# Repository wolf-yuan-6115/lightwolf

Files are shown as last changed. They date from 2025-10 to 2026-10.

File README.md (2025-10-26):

# LightWolf

> Sponsored by [Hack Club Blueprint](https://blueprint.hackclub.com/r/137?ref=r) program
> 
> To meet program requirements, `JOURNAL.md` and `bom.csv` files are included in this repository root.

LightWolf is a recreate version of Raspberry Pi Pico development board created by me. It's used to experiment with PCB designing and electronics.

Currently, LightWolf comes with following vairants:
- **LightWolf 2350** (`/2350`): Raspberry Pi RP2350 based development board with 4 MB of flash, USB C connector, a bunch of GPIO pins and 3 user LEDs.
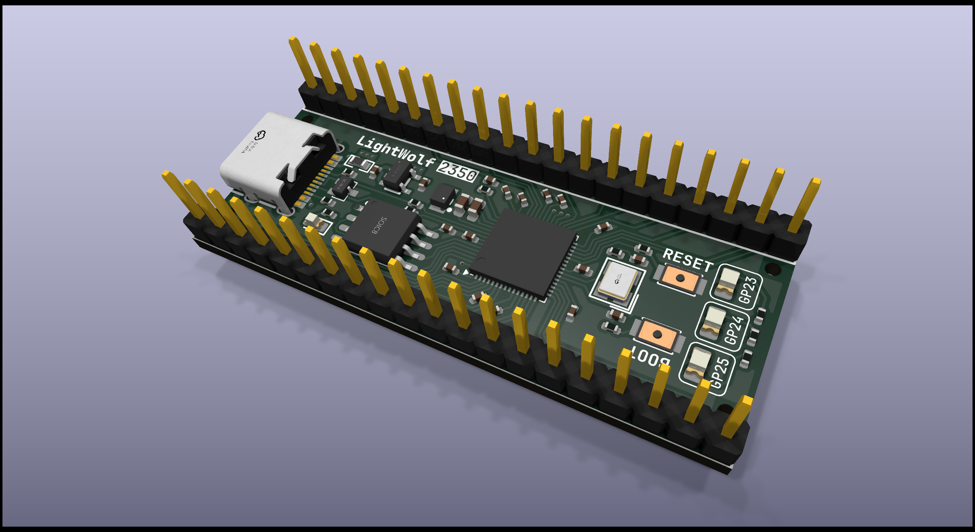
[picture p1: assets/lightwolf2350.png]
LightWolf 2350
  

> Depending on my free time, I may create more variants of LightWolf in the future.

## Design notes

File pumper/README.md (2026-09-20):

# Pumper

Pumper is an experimental RP2354-based USB Audio Class 2 DAC. The board uses a
PCM5102A DAC with OPA1652 and OPA1622 analog stages in a compact design intended
for learning about USB audio and DAC hardware.

The firmware provides a ten-band parametric EQ, headphone crossfeed, output
processing, USB host volume and mute, and persistent EQ profiles. Settings can
be controlled from either the React WebHID controller or the native Android
controller. Both controllers preview edits live and save persistent settings
only through explicit save actions.

## Supported audio formats

Pumper accepts stereo PCM over USB Audio Class 2 in the following formats:

| Sample rate | 16-bit stereo | Packed 24-bit stereo |
| --- | --- | --- |
| 44.1 kHz | Yes | Yes |
| 48 kHz | Yes | Yes |
| 88.2 kHz | Yes | Yes |
| 96 kHz | Yes | Yes |
| 176.4 kHz | Yes | No |
| 192 kHz | Yes | No |

## Audio processing and hardware path

Audio packets cross from the USB-facing core into the real-time DSP core
through a fixed block pool. After processing, ping-pong DMA feeds the PIO I2S
transmitter; the analog stages then filter, buffer, attenuate, and drive the
headphone output.

```mermaid
flowchart TB
    HOST[USB host<br/>UAC2 stereo PCM]

    subgraph DIGITAL[Digital audio path]
        direction LR
        USB[TinyUSB on RP2354 core 0<br/>receive and decode USB packets]
        QUEUE[Fixed audio-block queue<br/>core 0 to core 1]
        EQ[Preamp and<br/>10-band parametric EQ]
        XF[Headphone crossfeed]
        HOSTCTL[USB host<br/>gain and mute]
        OUTPROC[Output processing<br/>balance, mono, and width]
        LIMIT[Always-on<br/>stereo limiter]
        PACK[Final PCM quantization<br/>and I2S packing]
        I2S[Ping-pong DMA and PIO<br/>I2S transmitter]
        DAC[PCM5102A<br/>I2S DAC]

        USB --> QUEUE --> EQ --> XF --> HOSTCTL --> OUTPROC --> LIMIT --> PACK --> I2S --> DAC
    end

    subgraph ANALOG[Analog audio path]
        direction LR
        FILTER[Passive output filters]
        BUFFER[OPA1652<br/>stereo buffer]
        VOLUME[Dual-gang analog<br/>volume control]
        DRIVER[OPA1622<br/>headphone driver]
        PROTECT[Output ESD protection]
        JACK[3.5 mm TRRS<br/>analog output]

        FILTER --> BUFFER --> VOLUME --> DRIVER --> PROTECT --> JACK
    end

    HOST --> USB
    DAC --> FILTER
```

## Repository layout

- [`firmware/`](firmware/) — RP2354 firmware and portable host tests.
- [`web/`](web/) — React/TypeScript WebHID controller.
- [`android/`](android/) — experimental Android USB-host controller.
- [`assets/`](assets/) — board and assembled-device images.
- KiCad source files in the repository root — schematic and PCB design.

## Build and run

### Firmware

The firmware requires the Pico SDK, CMake, Ninja, a native C compiler, and the
Arm GNU embedded toolchain. See [`firmware/README.md`](firmware/README.md) for
SDK setup, supported audio formats, flashing, and troubleshooting.

```sh
export PICO_SDK_PATH="${HOME}/Projects/pico-sdk"
cmake -S firmware -B firmware/build -G Ninja \
  -DCMAKE_BUILD_TYPE=Release \
  -DPICO_BOARD=pico2 \
  -DPICO_PLATFORM=rp2350-arm-s \
  -DPICO_FLASH_SIZE_BYTES=2097152
cmake --build firmware/build --target rp2350_usb_dac -j
```

Flash `firmware/build/rp2350_usb_dac.uf2` using the RP2354 BOOTSEL drive.

### Web controller

Use a Chromium-based browser. WebHID works on a secure origin and on
`http://localhost`.

```sh
cd web
pnpm install
pnpm dev
```

See [`web/README.md`](web/README.md) for Linux HID permissions, tests,
production builds, previewing, and deployment.

### Android controller

The Android controller requires JDK 17 and Android SDK API 37. Android Studio
can open [`android/`](android/) directly.

```sh
cd android
./gradlew testDebugUnitTest lintDebug assembleDebug
```

See [`android/README.md`](android/README.md) for the debug simulator and USB
device requirements.

### Firmware host tests

These tests do not require the Pico SDK:

```sh
cmake -S firmware/tests -B /tmp/pumper-firmware-tests
cmake --build /tmp/pumper-firmware-tests
ctest --test-dir /tmp/pumper-firmware-tests --output-on-failure
```

## Hardware

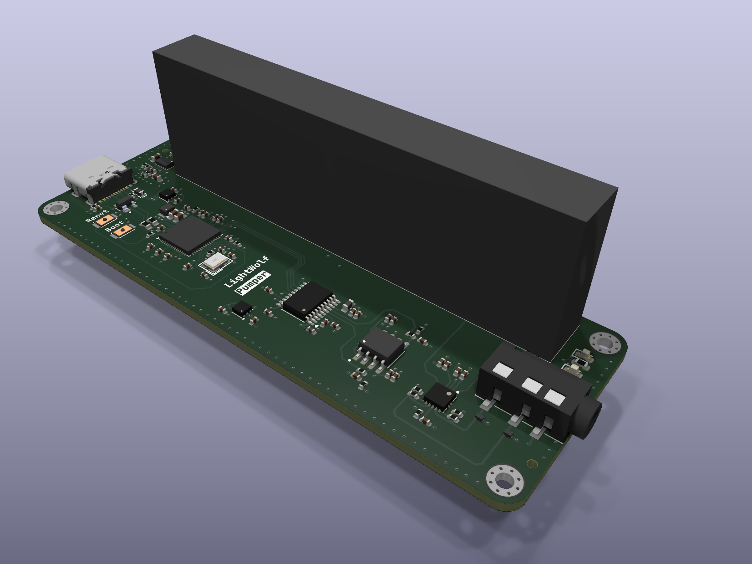
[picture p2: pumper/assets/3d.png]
PCB render


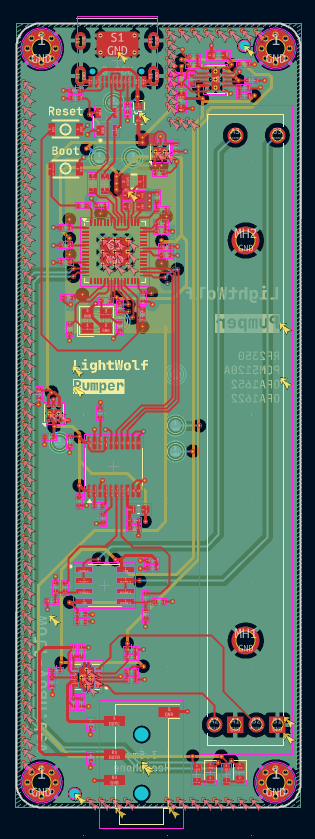
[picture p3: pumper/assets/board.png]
PCB


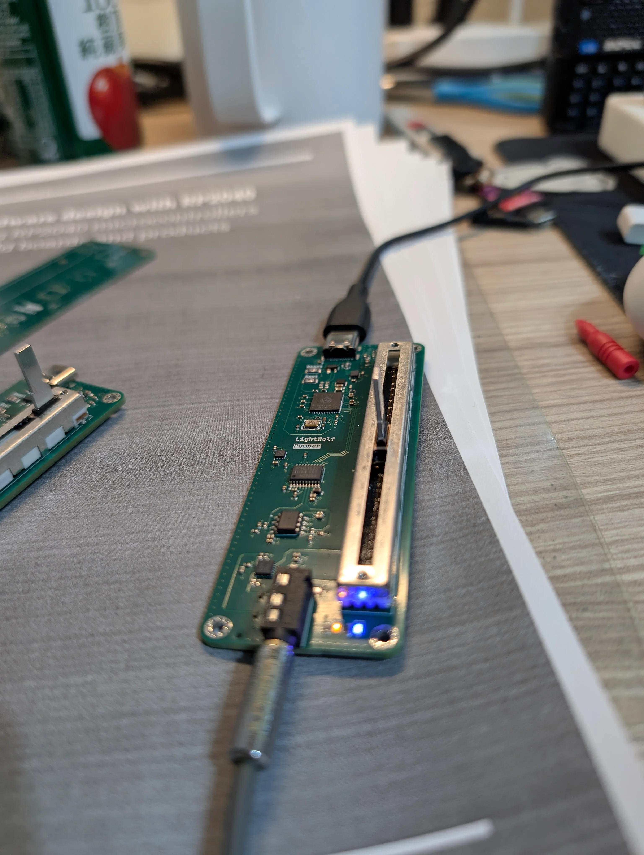
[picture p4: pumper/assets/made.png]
Assembled board


## Bill of materials

| Item | Cost |
| --- | --- |
| PCB shipping | $6.12 |
| PCB assembly | $86.18 |
| PCB | $11.43 |
| **Total** | **$103.73** |

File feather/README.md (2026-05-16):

# Feather

A USB DAC that provides even better audio quality compared to Pumper. Since I want to make the board as small as possible, the board itself is only 6x4 cm.

This board has two outputs: One is 3.5mm unbalanced output, another one is 4.4mm balanced, for headphone that supports this and it can provide more power through this port.

## Why Feather?

Due to being *half* Hi-Fi fan, I want to try out some new method to get better audio. Like previous project Pumper, already got amazing power to drive headphone. Though it has some flaw and I think it's got not very balanced sound profile.

Feather is aimed to elimate the problem encountered on Pumper, with improved DAC and op-amp and one more balanced output. It should be a lot better at driving headphone and provide good audio.

## Images

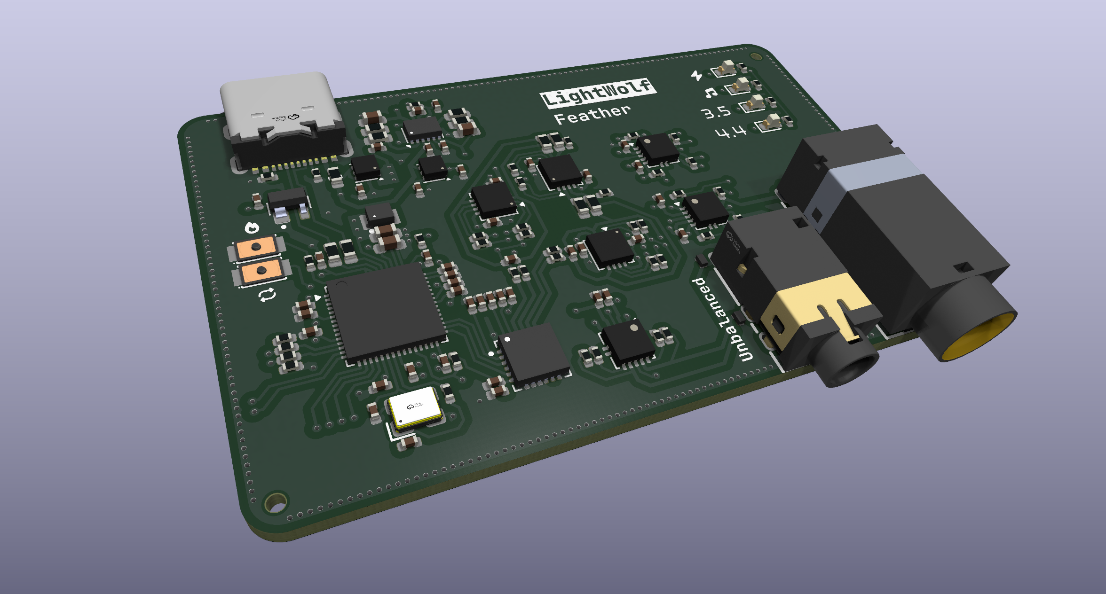
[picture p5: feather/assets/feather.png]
PCB render


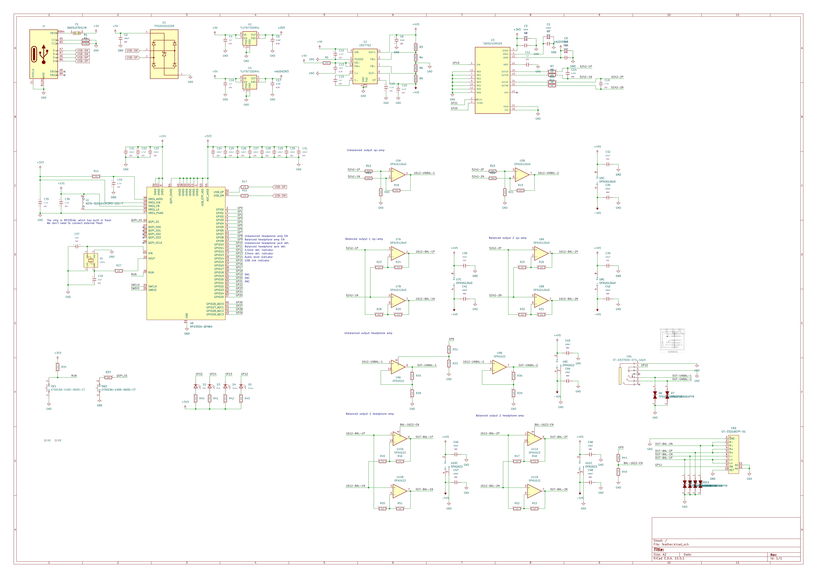
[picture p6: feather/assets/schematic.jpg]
Schematic


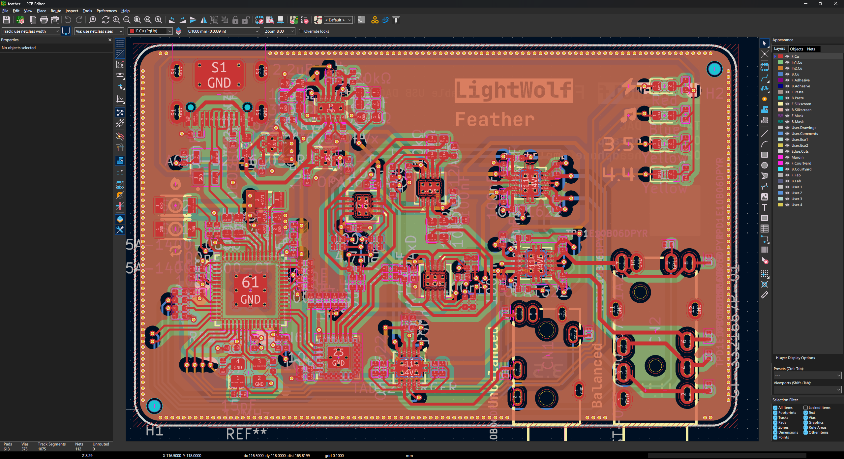
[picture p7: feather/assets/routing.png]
Routing


> It's a 4 layer board, with dedicated GND plane and power plane.

## BOM

| Name | Cost |
| --- | --- |
| PCB Shipping | $4.86 |
| PCB Assambly | $117.63 |
| PCB | $7.00 |
| Coupon | $-9.00 |
| **Total** | **$120.49** |

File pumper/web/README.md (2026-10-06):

# Pumper WebHID controller

The web controller is a static React application for the LightWolf Pumper USB
DAC. It uses TypeScript, Vite, Tailwind CSS 4, daisyUI, and Lucide icons.

It provides:

- Live ten-band parametric EQ preview with response graph, automatic preamp,
  input/output level meters updating at 50 Hz, and a firmware 3.3 limiter activity indicator.
- An always-on live output spectrum behind the EQ curve on firmware 3.5 or newer.
- Ten device profiles with separate load, save, default, and delete actions.
- USB sample-rate, bit-depth, stream, volume, and mute status.
- Headphone crossfeed and, on firmware 3.0 or newer, global output processing.
- The additional low-pass, high-pass, notch, and constant-peak band-pass EQ
  filters available on firmware 3.0 or newer.
- Firmware restart and BOOTSEL handoff actions.
- A responsive firmware 3.4 diagnostics grid for DSP, buffering, USB, and
  storage telemetry.

Live edits are sent to the DAC for preview. Flash is changed only by an
explicit profile, crossfeed, output-processing, default, or delete action.

The output spectrum uses a separate −96–0 dBFS scale and 256 logarithmic
points from 20 Hz to 20 kHz. Its 2,048-sample analysis window covers about
43–46 ms of audio, with native frequency spacing of roughly 22–23 Hz;
the display points do not provide independent resolution below that spacing.
It combines stereo power and targets 20 updates per second, dropping visual
updates when necessary to prioritize playback. Spectrum reports share the level
meter connection lifecycle, with no toggle or browser setting. Animation pauses
while the page is hidden. The spectrum animates
between reports with a fast rise and a short decay. Android does not
have the spectrum feature yet.

## Requirements

- Chromium-based browser with WebHID support
- Node.js and pnpm
- A Pumper DAC for hardware control

WebHID works from a secure origin and from `http://localhost`; no special
firmware development-origin flag is required.

## Development

From this directory:

```sh
pnpm install
pnpm dev
```

Open the local Vite URL in Chromium and connect the DAC over USB.

### Linux device access

Linux may create generic HID nodes without write permission for the logged-in
user. Install the project rule once, reload udev, and reconnect the DAC:

```sh
sudo install -m 0644 ../udev/70-pumper-webhid.rules /etc/udev/rules.d/
sudo udevadm control --reload-rules
```

The rule is restricted to the Pumper USB VID/PID and grants access to the
active desktop session through systemd-logind.

## Verification

```sh
pnpm test
pnpm build
pnpm preview
```

The production build is written to `dist/`.

## Deployment

The project is configured for Cloudflare Workers Static Assets:

```sh
pnpm deploy
```

Configure the Worker's custom domain separately in Cloudflare if deploying to
`pumper.wolf-yuan.dev`.

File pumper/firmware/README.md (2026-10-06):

# Pumper firmware

The firmware runs on the RP2354 board and exposes a composite USB Audio Class
2 device plus a vendor HID control interface. It provides a ten-band
parametric EQ, headphone crossfeed, global output processing, USB host volume
and mute, persistent profiles, and device diagnostics for the WebHID and
Android controllers.

Firmware 3.4 supports stereo PCM in these formats:

- 16-bit at 44.1, 48, 88.2, 96, 176.4, and 192 kHz.
- Packed 24-bit at 44.1, 48, 88.2, and 96 kHz.

The 24-bit alternate is not available at 176.4 or 192 kHz. Profile changes and
audio-control previews are live; persistent settings are changed only by the
corresponding save, default, or delete action. Audio is briefly muted while a
persistent setting is written and verified.
Realtime meter reports also identify limiter gain reduction for controller clip
indicators. A separate telemetry report exposes device uptime, DSP load, I2S
buffer health, USB feedback, limiter activity, and transport/storage counters.

Firmware 4.0 provides a live output spectrum that is always displayed by the web
controller (also supported on firmware 3.5): 256 display points over 20 Hz–20 kHz, targeting 20 updates per
second. The display measures processed digital audio before the fixed I²S
output gain; it does not measure the analog DAC output.

## Requirements

- CMake 3.13 or newer
- Ninja, or another CMake build tool
- A native C/C++ compiler for Pico SDK host tools
- Arm GNU embedded toolchain, including `arm-none-eabi-gcc`
- Pico SDK 2.3.0 with its Git submodules initialized

On Debian or Ubuntu:

```sh
sudo apt install build-essential cmake git ninja-build gcc-arm-none-eabi libnewlib-arm-none-eabi
```

Check the two tools most commonly missing during configuration:

```sh
arm-none-eabi-gcc --version
ninja --version
```

## Pico SDK setup

Clone the verified SDK release with its submodules and point
`PICO_SDK_PATH` at the checkout:

```sh
git clone --branch 2.3.0 --recurse-submodules \
  https://github.com/raspberrypi/pico-sdk.git "${HOME}/Projects/pico-sdk"
export PICO_SDK_PATH="${HOME}/Projects/pico-sdk"
```

The RP2350 USB audio endpoint requires the following TinyUSB fixes when they
are not already present in the SDK checkout:

```sh
git -C "${PICO_SDK_PATH}/lib/tinyusb" fetch origin
git -C "${PICO_SDK_PATH}/lib/tinyusb" cherry-pick 86c28b76f 1ec93757f
```

Keep these SDK changes in the Pico SDK checkout; they are not project source
files.

## Configure and build

Run from the repository root. The project uses the `pico2` board definition,
the `rp2350-arm-s` platform, and the RP2354's 2 MiB flash configuration:

```sh
cmake -S firmware -B firmware/build -G Ninja \
  -DCMAKE_BUILD_TYPE=Release \
  -DPICO_BOARD=pico2 \
  -DPICO_PLATFORM=rp2350-arm-s \
  -DPICO_FLASH_SIZE_BYTES=2097152

cmake --build firmware/build --target rp2350_usb_dac -j
```

The UF2 image is written to:

```text
firmware/build/rp2350_usb_dac.uf2
```

For later source changes, rerun only the build command. Configure into a fresh
build directory if the SDK, board, platform, or toolchain changes. The build
checks the firmware size and reserves the final 8 KiB of flash for settings.

## Flashing

To flash manually:

1. Disconnect the DAC.
2. Hold the RP2354 BOOTSEL button while reconnecting USB.
3. Release BOOTSEL when the USB mass-storage drive appears.
4. Copy `firmware/build/rp2350_usb_dac.uf2` to the drive.
5. Wait for the drive to disconnect and the DAC to restart.

The WebHID and Android controllers can also request a BOOTSEL restart. They do
not upload the UF2; the image must still be copied to the boot-ROM drive.
Existing profiles are stored outside the UF2 image.

## Host tests

The portable configuration, DSP, protocol, audio-format, and profile-storage
tests do not require the Pico SDK:

```sh
cmake -S firmware/tests -B /tmp/pumper-firmware-tests
cmake --build /tmp/pumper-firmware-tests
ctest --test-dir /tmp/pumper-firmware-tests --output-on-failure
```

## Troubleshooting

- `Compiler 'arm-none-eabi-gcc' not found`: install the Arm embedded toolchain
  or add it to `PATH`.
- `CMAKE_MAKE_PROGRAM is not set` with the Ninja generator: install Ninja or
  choose another installed CMake generator.
- If USB audio or its isochronous endpoint does not work, verify the TinyUSB
  fixes above, configure a fresh build directory, and flash the newly built
  UF2.

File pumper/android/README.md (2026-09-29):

# Pumper Controller for Android

The Android app is an experimental native controller for the LightWolf Pumper
USB DAC. It uses Android USB host APIs and the same HID control protocol as the
WebHID controller in [`../web/`](../web/).

The app provides:

- Live ten-band parametric EQ preview, response graph, automatic preamp,
  signal meters, and a firmware 3.3 limiter activity indicator.
- Audio status including USB sample rate, bit depth, stream state, and host
  master volume/mute.
- Headphone crossfeed with Off, Low, Medium, High, and Custom modes.
- Firmware 3.0 output processing for mono, channel swap, polarity, balance,
  and stereo width.
- Firmware 3.0 low-pass, high-pass, notch, and constant-peak band-pass EQ
  filters.
- Ten profiles with separate save, select, default, and delete actions.
- Firmware diagnostics, normal restart, and BOOTSEL handoff.
- Firmware 3.4 telemetry for DSP load, I2S buffering, USB feedback, limiter
  activity, and transport/storage health.

Crossfeed requires firmware 2.2 or newer. Output processing and the additional
EQ filter types require firmware 3.0 or newer. Live edits do not write flash;
the app saves crossfeed, output processing, and profiles independently through
explicit actions.

## Requirements

- Android 14 or newer (`minSdk 34`)
- Android SDK API 37
- JDK 17
- Android Studio, or the included Gradle wrapper
- An Android USB-host device and a data-capable USB cable or OTG adapter for
  physical DAC testing

If the SDK or Java paths are not configured, set `ANDROID_HOME` and
`JAVA_HOME` before using the Gradle wrapper.

## Build and verify

Run from this directory:

```sh
./gradlew testDebugUnitTest
./gradlew lintDebug
./gradlew assembleDebug
```

The debug APK is written to
`app/build/outputs/apk/debug/app-debug.apk`. To install it on a connected
development device, run:

```sh
./gradlew installDebug
```

Android Studio can open the `android/` directory directly.

## Debug simulator

Debug builds include **Open simulated DAC** on the disconnected screen. The
simulator allows UI and controller workflows to be exercised without Pumper
hardware. It is not included in release builds.

The simulator does not validate Android USB permissions, HID endpoint
discovery, or compatibility with a physical DAC. Those paths require an
Android USB-host device and Pumper hardware.

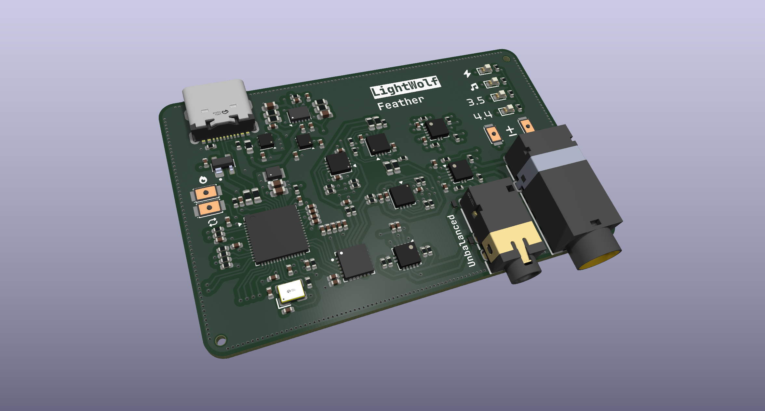
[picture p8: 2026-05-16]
feather/export/feather.png

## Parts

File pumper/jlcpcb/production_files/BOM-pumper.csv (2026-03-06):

Comment | Designator | Footprint | LCSC | Quantity
0603L075SLYR | F1 | F0603 | C207016 | 1
100nF | C12,C14,C15,C16,C17,C18,C19,C20,C21,C22,C3,C31,C32,C33,C35,C37,C42,C43,C47 | C_0402 | C1525 | 19
10kΩ | R5 | R_0402 | C25744 | 1
10uF | C30,C34,C36,C41,C45,C46,C5,C8 | C_0402 | C15525 | 8
120kΩ | R4,R6 | R_0402 | C25750 | 2
15pF | C26,C29 | C_0402 | C1548 | 2
180Ω | R23 | R_0603 | C22828 | 1
1TS015A-1400-0600-CT | SW1,SW2 | SW-SMD_L3.0-W2.0-LS3.5 | C319433 | 2
1kΩ | R12,R13,R16,R17,R18,R19,R20,R21,R8 | R_0402 | C11702 | 9
1uF | C1,C4,C9 | C_0402 | C52923 | 3
2.2nF | C38,C39 | C_0402 | C1531 | 2
2.2uF | C2,C40,C44 | C_0402 | C12530 | 3
2.2uF | C11,C6 | C_0603 | C23630 | 2
27Ω | R10,R11 | R_0603 | C25190 | 2
2kΩ | R14,R15 | R_0402 | C4109 | 2
330kΩ | R3,R7 | R_0402 | C25778 | 2
33Ω | R9 | R_0402 | C25105 | 1
4.7uF | C24,C25 | C_0603 | C19666 | 2
4.7uF | C10,C13,C23,C7 | C_0402 | C23733 | 4
47kΩ | R22 | R_0402 | C25792 | 1
5.1kΩ | R1,R2 | R_0402 | C25905 | 2
560Ω | R24 | R_0603 | C23204 | 1
ABM8-272-T3_C20625731 | U5 | CRYSTAL-SMD_4P-L3.2-W2.5-BL | C20625731 | 1
AOTA-B201610S3R3-101-T | L1 | IND-SMD_L2.0-W1.6_AOTA-B201610S3R3-101-T | C42411119 | 1
AudioJack4 | J2 | Jack_3.5mm_KoreanHropartsElec_PJ-320D-4A_Horizontal | C95562 | 1
Connector, USB-TYPE-C-16P | J1 | TYPE-C-SMD_HX-TYPE-C-16PIN | C5178539 | 1
LED | D2 | D_0603 | C2288 | 1
LM27762 | U3 | WSON-12-1EP_3x2mm_P0.5mm_EP1x2.65_ThermalVias | C473398 | 1
OPA1622IDRCR | U8 | IC_OPA1622IDRCR | C2876559 | 1
OPA1652AIDR | U6 | SOIC127P599X175-8N | C30025 | 1
PCM5102A | U7 | TSSOP-20_4.4x6.5mm_P0.65mm | C107671 | 1
RP2354A-QFN60 | U4 | QFN-60-1EP_7x7mm_P0.4mm_EP3.4x3.4mm_ThermalVias | C41378174 | 1
RS6011DP6002 | VR1 | RS6011DP6002 | C470553 | 1
TLV76733DRVx | U1,U2 | WSON-6-1EP_2x2mm_P0.65mm_EP1x1.6mm_ThermalVias | C2848334 | 2
TPD1E10B06DPYR | D4,D5 | DIO_TPD1E10B06DPYR | C48260 | 2
TPD2E001DZDR | D1 | SOT192P237X122-4N | C89411 | 1
Yellow | D3 | D_0603 | C89811 | 1
~ | FB1 | FB_0603 | C1002 | 1
TestPoint | TP9 | TestPoint_Pad_D1.0mm |  | 1
TestPoint | TP8 | TestPoint_Pad_D1.0mm |  | 1
TestPoint | TP7 | TestPoint_Pad_D1.0mm |  | 1
TestPoint | TP6 | TestPoint_Pad_D1.0mm |  | 1
TestPoint | TP5 | TestPoint_Pad_D1.0mm |  | 1
TestPoint | TP4 | TestPoint_Pad_D1.0mm |  | 1
TestPoint | TP3 | TestPoint_Pad_D1.0mm |  | 1
TestPoint | TP1 | TestPoint_Pad_D1.0mm |  | 1
TestPoint | TP2 | TestPoint_Pad_D1.0mm |  | 1

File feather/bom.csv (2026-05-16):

Comment | Designator | Footprint | LCSC | Quantity
0603L075SLYR | F1 | Fuse_0603_1608Metric | C207016 | 1
100kΩ | R33,R51 | R_0402 | C25741 | 2
100nF | C1,C2,C21,C23,C24,C25,C26,C27,C28,C29,C3,C30,C31,C32,C9 | C_0402 | C1525 | 15
100nF | C34,C38,C39,C41,C42,C43,C44,C45,C46,C47,C48 | C_0402 | C307331 | 11
10kΩ | R18,R19,R20,R21,R5 | R_0402 | C25744 | 5
10kΩ | R12,R13,R15,R16 | R_0603 | C25804 | 4
10uF | C11,C13,C7,C8 | C_0402 | C15525 | 4
120kΩ | R4,R6 | R_0603 | C25808 | 2
12MHz | X1 | OSC-SMD_4P-L3.2-W2.5-BL_SIT8008BI | C20625731 | 1
15pF | C37,C40 | C_0402 | C1548 | 2
1TS015A-1400-0600-CT | SW1,SW2,SW3,SW4 | SW-SMD_L3.0-W2.0-LS3.5 | C319433 | 4
1kΩ | R10,R11,R23,R24,R25,R26,R27,R28,R29,R30,R31,R32,R34,R35,R36,R37,R38,R39,R40,R42,R43,R44,R45,R46,R47,R48,R49,R50,R52,R53,R54,R55,R7,R8 | R_0402 | C11702 | 34
1uF | C12,C15,C16,C4 | C_0402 | C52923 | 4
2.2uF | C17,C5 | C_0402 | C12530 | 2
2.2uF | C20,C6 | C_0603 | C23630 | 2
27Ω | R17,R22 | R_0603 | C25190 | 2
330kΩ | R3,R9 | R_0603 | C23137 | 2
330Ω | R41 | R_0402 | C25104 | 1
33Ω | R14 | R_0402 | C25105 | 1
4.7nF | C14,C18 | C_0402 | C1538 | 2
4.7uF | C35,C36 | C_0603 | C19666 | 2
4.7uF | C10,C19,C22,C33 | C_0402 | C23733 | 4
5.1kΩ | R1,R2 | R_0402 | C25905 | 2
AOTA-B201610S3R3-101-T | L1 | IND-SMD_L2.0-W1.6_AOTA-B201610S3R3-101-T | C42411119 | 1
Blue | D3 | D_0603 | C7496823 | 1
Connector, USB-TYPE-C-16P | J1 | TYPE-C-SMD_HX-TYPE-C-16PIN | C2927039 | 1
GT-3321667P-01 | CN2 | AUDIO-TH_GT-3321667P-01 | C2762984 | 1
LM27762 | U2 | WSON-12-1EP_3x2mm_P0.5mm_EP1x2.65_ThermalVias | C473398 | 1
OPA1612AxD | U5,U7,U8 | WSON-8-1EP_3x3mm_P0.5mm_EP1.2x2mm_ThermalVias | C2058640 | 3
OPA1622 | U10,U11,U9 | Texas_S-PVSON-N10_ThermalVias | C2876559 | 3
RP2354A | U6 | QFN-60-1EP_7x7mm_P0.4mm_EP3.4x3.4mm_ThermalVias | C42411118 | 1
Red | D2 | D_0603 | C2286 | 1
ST-0337D00-071-1A2H | CN1 | AUDIO-TH_ST-0337D00-071-1A2H | C2829972 | 1
TAD5242IRGER | U3 | IC_TAD5242IRGER | C42414591 | 1
TLV76733DRVx | U1,U4 | WSON-6-1EP_2x2mm_P0.65mm_EP1x1.6mm_ThermalVias | C2848334 | 2
TPD1E10B06DPYR | D10,D11,D12,D13,D6,D7,D8,D9 | DIO_TPD1E10B06DPYR | C48260 | 8
TPD2E001DZDR | D1 | SOT192P237X122-4N | C89411 | 1
Yellow | D4,D5 | D_0603 | C89811 | 2

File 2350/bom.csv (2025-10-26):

Comment | Designator | Footprint | LCSC | Quantity
0603L100SLYR | U2 | R0603 | C207017 | 1
100nF | C13,C14,C15,C16,C2,C3,C4,C5,C6,C7,C8 | C_0402 | C1525 | 11
10uF | C12,C9 | C_0402 | C15525 | 2
15pF | C10,C11 | C_0402 | C1548 | 2
1TS015A-1400-0600-CT | BOOT1,RESET1 | SW-SMD_L3.0-W2.0-LS3.5 | C319433 | 2
1kΩ | R1,R8 | R_0402 | C11702 | 2
33Ω | R6,R7,R9 | R_0402 | C25105 | 3
4.7uF | C17,C18 | C_0603 | C19666 | 2
4.7uF | C19 | C_0402 | C23733 | 1
470nF | C1 | C_0402 | C47339 | 1
470Ω | R10,R11,R12,R4 | R_0402 | C25117 | 4
5.1kΩ | R13,R2,R3 | R_0402 | C25905 | 3
ABM8-272-T3_C20625731 | U1 | CRYSTAL-SMD_4P-L3.2-W2.5-BL | C20625731 | 1
AOTA-B201610S3R3-101-T | L1 | IND-SMD_L2.0-W1.6_AOTA-B201610S3R3-101-T | C42411119 | 1
DS1021-1X20SF11-B | U5,U6 | HDR-TH_20P-P2.54-V-M | C7430376 | 2
Green | D4,D5 | D_0805 | C2297 | 2
RP2350A_C42411118 | U4 | QFN-60-1EP_7x7mm_P0.4mm_EP3.4x3.4mm_ThermalVias | C42411118 | 1
TPD2E2U06DCKR | D1 | SC-70-3_L2.0-W1.3-P0.65-LS2.1-BL | C1855726 | 1
TYPE-C-31-M-12 | USBC1 | USB-C_SMD-TYPE-C-31-M-12_1 | C165948 | 1
W25Q64JVSSIQ_C179171 | U3 | SOIC-8_L5.3-W5.3-P1.27-LS8.0-BL | C179171 | 1
White | D2 | D_0603 | C2290 | 1
XC6220B331MR-G | Q1 | SOT-25_L3.0-W1.6-P0.95-LS2.8-TL | C86534 | 1
Yellow | D3 | D_0805 | C2296 | 1

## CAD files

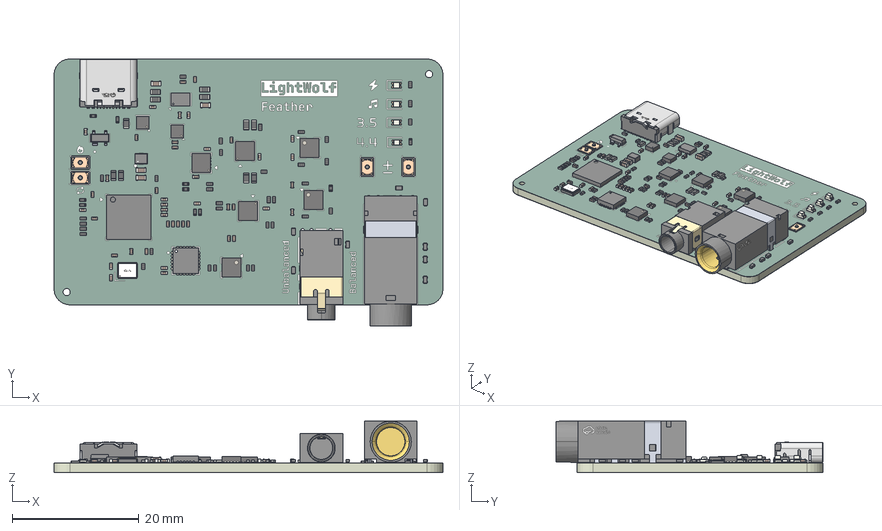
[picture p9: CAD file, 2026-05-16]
feather/export/feather.step
61.4 x 42.2 x 8.17 mm
C_0402_1005Metric x 44
R_0603_1608Metric x 10
R_0402_1005Metric x 45
LED_0603_1608Metric_Castellated x 4
TYPE-C-SMD_HX-TYPE-C-16PIN
WSON_6_1EP_2x2mm_P065mm_EP1x16mm x 2
OSC-SMD_4P-L3.2-W2.5-CJ13-320001210A20
Texas_S_PVSON_N10 x 3
AUDIO-TH_ST-0337D00-071-1A2H
SW-SMD_L3.0-W2.0-LS3.5 x 4
RGE24
WSON_8_1EP_3x3mm_P05mm_EP16x20mm x 3
DPY2 x 8
LM27762DSSR
Fuse_0603_1608Metric
IND-SMD_L2.0-W1.6_AOTA-B201610S3R3-101-T
AUDIO-TH_GT-3321667P-01
C_0603_1608Metric x 4
DZD4
RP2350A-QFN60
feather_silkscreen x 2
feather_soldermask x 2
feather_PCB

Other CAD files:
feather/export/feather.stl

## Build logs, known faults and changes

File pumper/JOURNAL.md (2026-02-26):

# 2/27 Nah LM27762 you come back

So basically, I've done following:

1. Relocated LM27762 to far corner from analog circuit
2. Made some cool branding
3. Rerouted several parts



# 2/25 Getting rid of LM27762

Posted the design in KiCad Discord server, and I got some feedback. The most important one is LM27762 is VERY noisy and picky about PCB design from my research. I'm gonna upgrade (Kinda of) and make both AMP run in BTL mode.



# 2/23 Airnote is now pumper

I initially named it Airnote because I want it to me a portable Bluetooth DAC. But it seems like it's not possible and it's now just a USB DAC.

But I finished the schematic and PCB routing!

pumper_page-0001
pumper_page-0002
pumper_page-0003



# 2/22 It's been a big day

Well I threw my schematic into an AI tool and it told me... OPA2141 is too weak (well I mean tl;dr)



Going to replace it with OPA1652

# 2/22 Completed whole routing

Yayyy, but I'm still not sure wether this board will work or not...



# 2/22 Completed power and OPA2141 routing

The power is harder than I was expecting. The chip is so small...



# 2/22 Completed RP2354 routing



# 2/21 Finished all schematic

airnote_page-0001
airnote_page-0002
airnote_page-0003

# 2/21 RP2354A MCU schematic done!



# 2/21 Back from Lunar New Year holiday

Finally decided to use RP2354A (The one with built in flash), and splitted the design into 3 schematics.



# 2/14 YEAHHHH no ESP32 now

ESP32-C3 doesn't have native USB (USB OTG) so we will stick with RP2350! (Or 2040)

Since ESP32 WROOM needs to use standard SMT, we can save some money through using 2350 or 2040.

# 2/12 Just added two pin headers

Nothing new, just two additional header for GPIOs and UART.

# 2/12 Schematic done!

Basically got three TI's chip to get good audio.

From ESP32-C3, to PCM5102A, to OPA2141, finally to OPA1622. 

airnote_page-0001

But I'm not sure if it will work or not. I get into too much field I'm not familiar with.

# 2/11 Reading datasheet...

Just reading datasheet and drawing schematic



# 2/10 Snap, ESP32-S3 doesn't have classic BT

Initially I went with ESP32-S3 because it got bunch of processing power. But it looks like S3 only have Bluetooth LE which doesn't have A2DP. Gotta went with C3. Currently searching for chips.

# 2/6 TWO USB PORTS? What da hel

Soooo I just realized ESP32-S3 got a native USB, but it seems like we still need USB to UART chip for recovery...? Still digging and I think I will have only one which is native port.

Still researching strapping pins.

# 2/5 Started working on AirNote

Current planning is to use ESP32-S3 as MCU, paired with TI's PCM5102 DAC for high quality audio playback. 



Already has some plan in my mind, currently working on power rails and USB input.

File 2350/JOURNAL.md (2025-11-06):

<!--
  ===================    !!READ THIS NOTICE!!   ====================
  DO NOT edit this file manually. Your changes WILL BE OVERWRITTEN!
  This journal is auto generated and updated by Hack Club Blueprint.
  To edit this file, please edit your journal entries on Blueprint.
  ==================================================================
-->

## 10/21/2025 - Drew the schematic  

Drew the schematic, read whole bunch of datasheets.

I ultimately decided to use RP2350, with a 8 MB SPI flash, along with high technology... USB-C connector.

There will also be some pins header on the board.



## 10/22/2025 12 AM - Partially routed PCB  

Got some routing on the PCB now!

Currently only placed main MCU on the board and pin header, other thing is still waiting to do.

I'm concerned about the very limited board size... Hope everything will fit inside the Raspberry Pi Pico size



## 10/22/2025 11:03 PM - Routed non GPIO part on PCB  

Ayyyy some great progress... though there's a bigger challenge upcoming.

I routed all non GPIO pins to RP2350! This leaves me with a bunch of GPIOs. I hope I could route them without getting myself crazy.



## 10/22/2025 11:25 PM - Changed to 4 layer board  

2 layer board made by routing a lotttt messy, soo I decided to change my board to a 4 layer board.

After switching, I don't need to deal with 3V3 and 1V1 plane anymore, yayy



## 10/23/2025 12 AM - Thing didn't go as expected  

After changing the board to a 4 layer one, I don't think I did a great job at trace management...

The board now looks even more messy, I think I need to redo the whole wring someday.



## 10/23/2025 9 PM - Finished rerouting the PCB!  

Yayyy, finally finished rerouting the PCB with 4 layers board!

The inner layer now acts like 3V3 and 5V pane, it heavily reduced the complexity of my route. I think current one is good to ship... just one thing left...

Time for silkscreen art!




> Sadly Hackatime wasn't up during these hours. I tried my best to remember to run it when I start KiCad

## 10/23/2025 11 PM - Finished cooking silkscreen art  

I think I finished my silkscreen art! Though I didn't find a great way to automate the process of labeling GPIO pins, I just adjust and change them manually.




## 10/26/2025 - Ahh board design got some trouble  

I posted my design on Reddit and some people helped me :D

Fixed several issues, including problematic BOOTSEL button, the board should be done now! I didn't see that my design uses via-in-pad, so um I need to spend few extra bucks on via :/

Hope the board works when it arrives



## 11/6/2025 9 PM - Faulty design, faulty board  

So, I just ran into a trouble.

The board arrived, not shorted but RP2350 did not function (USB drive does not appear on the computer, in other word RP2350 is not working correctly). I currently suspect that `VREG_AVDD`'s capacitor is not correctly wire up, and RP2350 didn't work afterwards.

I've spend a while trying to debug, but this seems like the only possible reason why the board doesn't work.



## 11/6/2025 11 PM - Fixed the board, sort of...  

I fixed the board! Thanks to `@colon three` in Hack Club Slack, the problem is not capacitor, it's not resistor. It's crystal oscillator! The project is finally ended here, for who got `60wfo` revision board, a working board is only a few tweak away!



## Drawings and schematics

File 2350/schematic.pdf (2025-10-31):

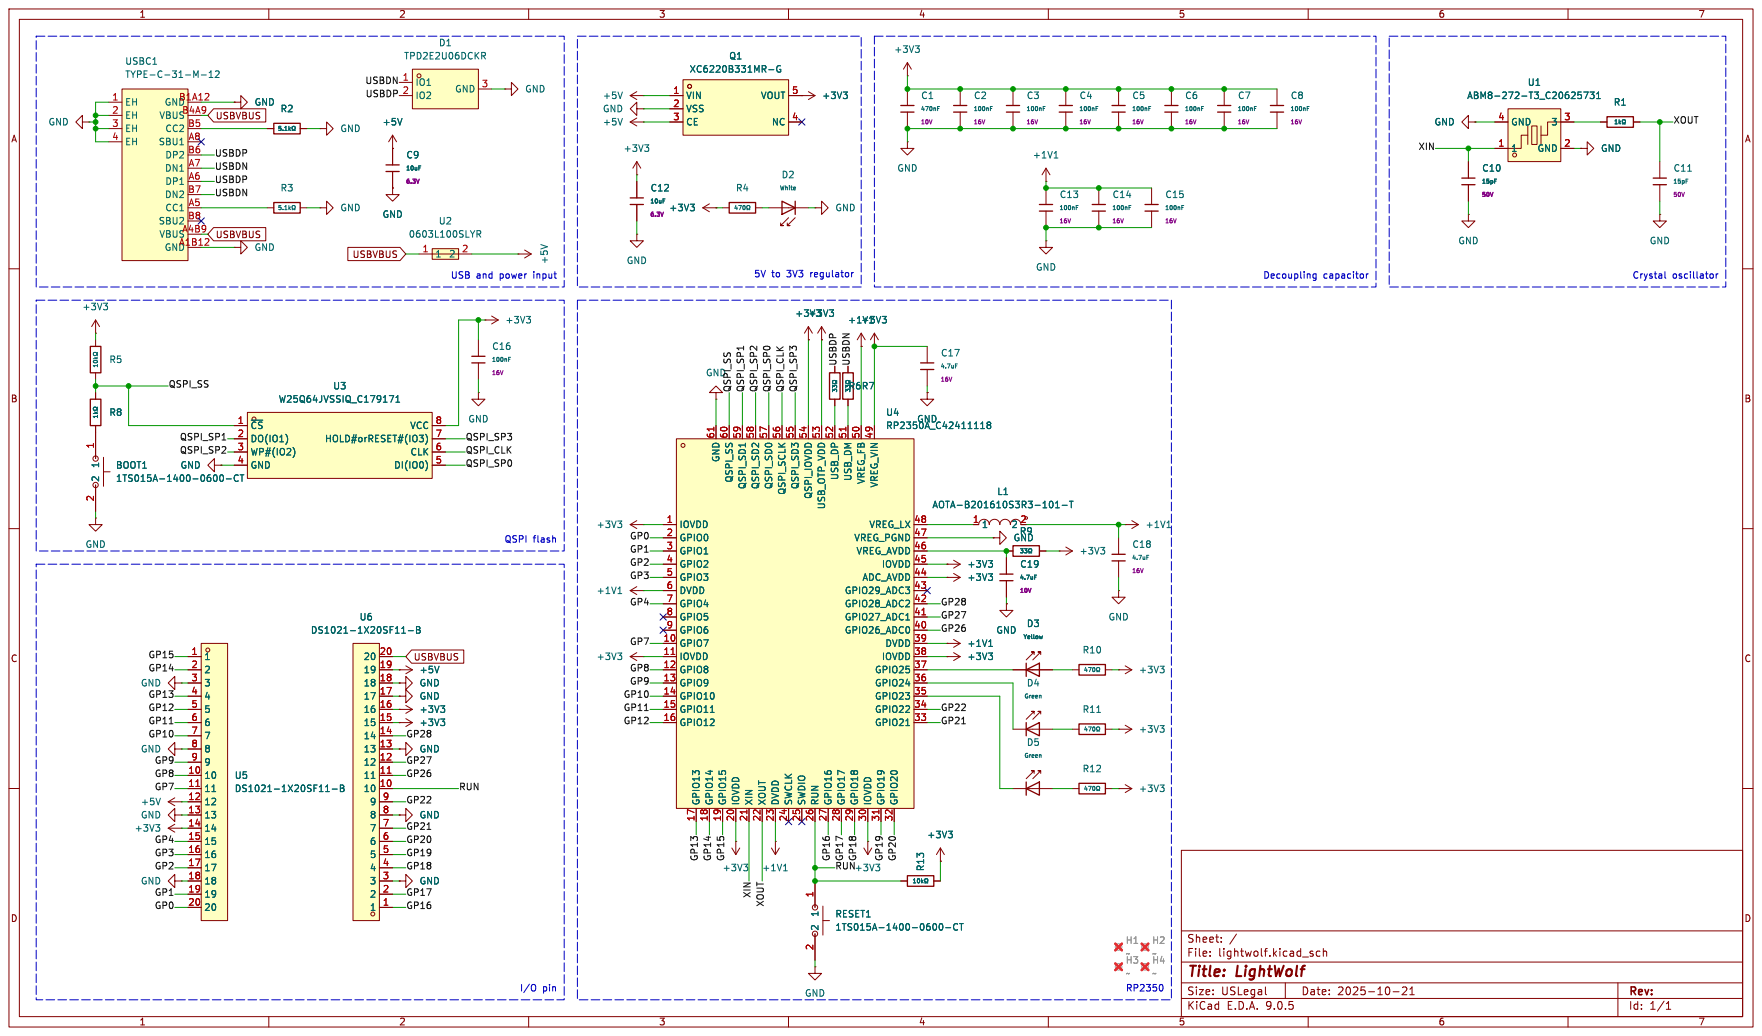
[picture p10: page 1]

+3V3 GND GND GND GND GND

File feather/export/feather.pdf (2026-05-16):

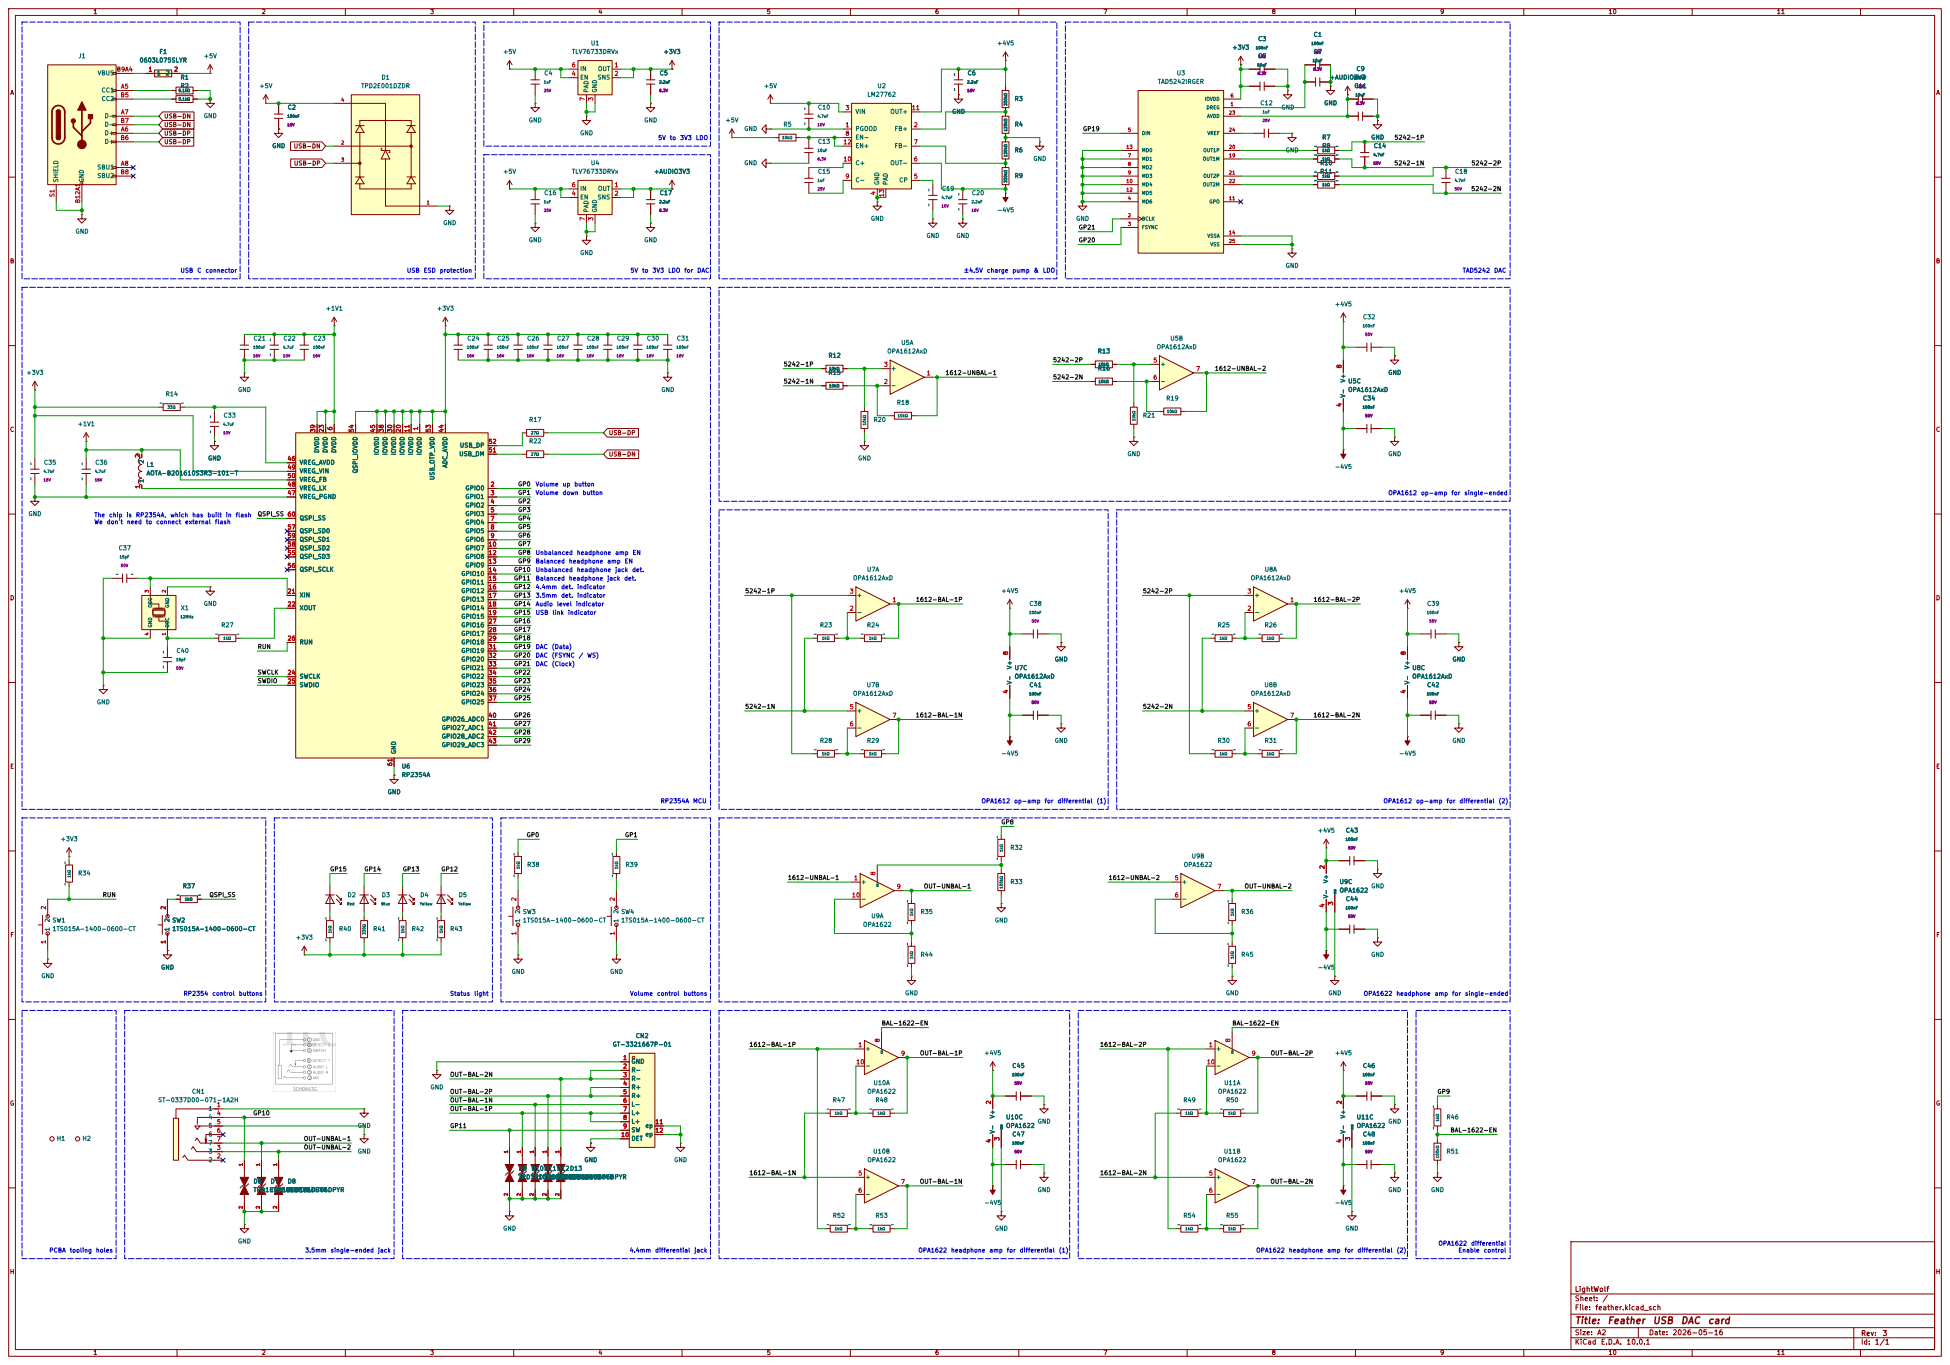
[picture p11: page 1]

4.7uF 10V USB-DP USB-DP USB-DN
USB-DN

5V to 3V3 LDO for DAC

USB-DP USB-DN

Unbalanced headphone jack det. Volume up button
Volume down button Balanced headphone amp EN

OPA1612 op-amp for single-ended OPA1612 op-amp for differential (1) RP2354 control buttons

The chip is RP2354A, which has built in flash We don't need to connect external flash

Unbalanced headphone amp EN

USB link indicator 4.4mm det. indicator

OPA1612 op-amp for differential (2)

OUT-BAL-2P OUT-BAL-1N

OPA1622 headphone amp for differential (1)

LightWolf
Sheet: /
File: feather.kicad_sch
Title: Feather USB DAC card

Size: A2 | Rev: 3
KiCad E.D.A. 10.0.1 | Id: 1/1

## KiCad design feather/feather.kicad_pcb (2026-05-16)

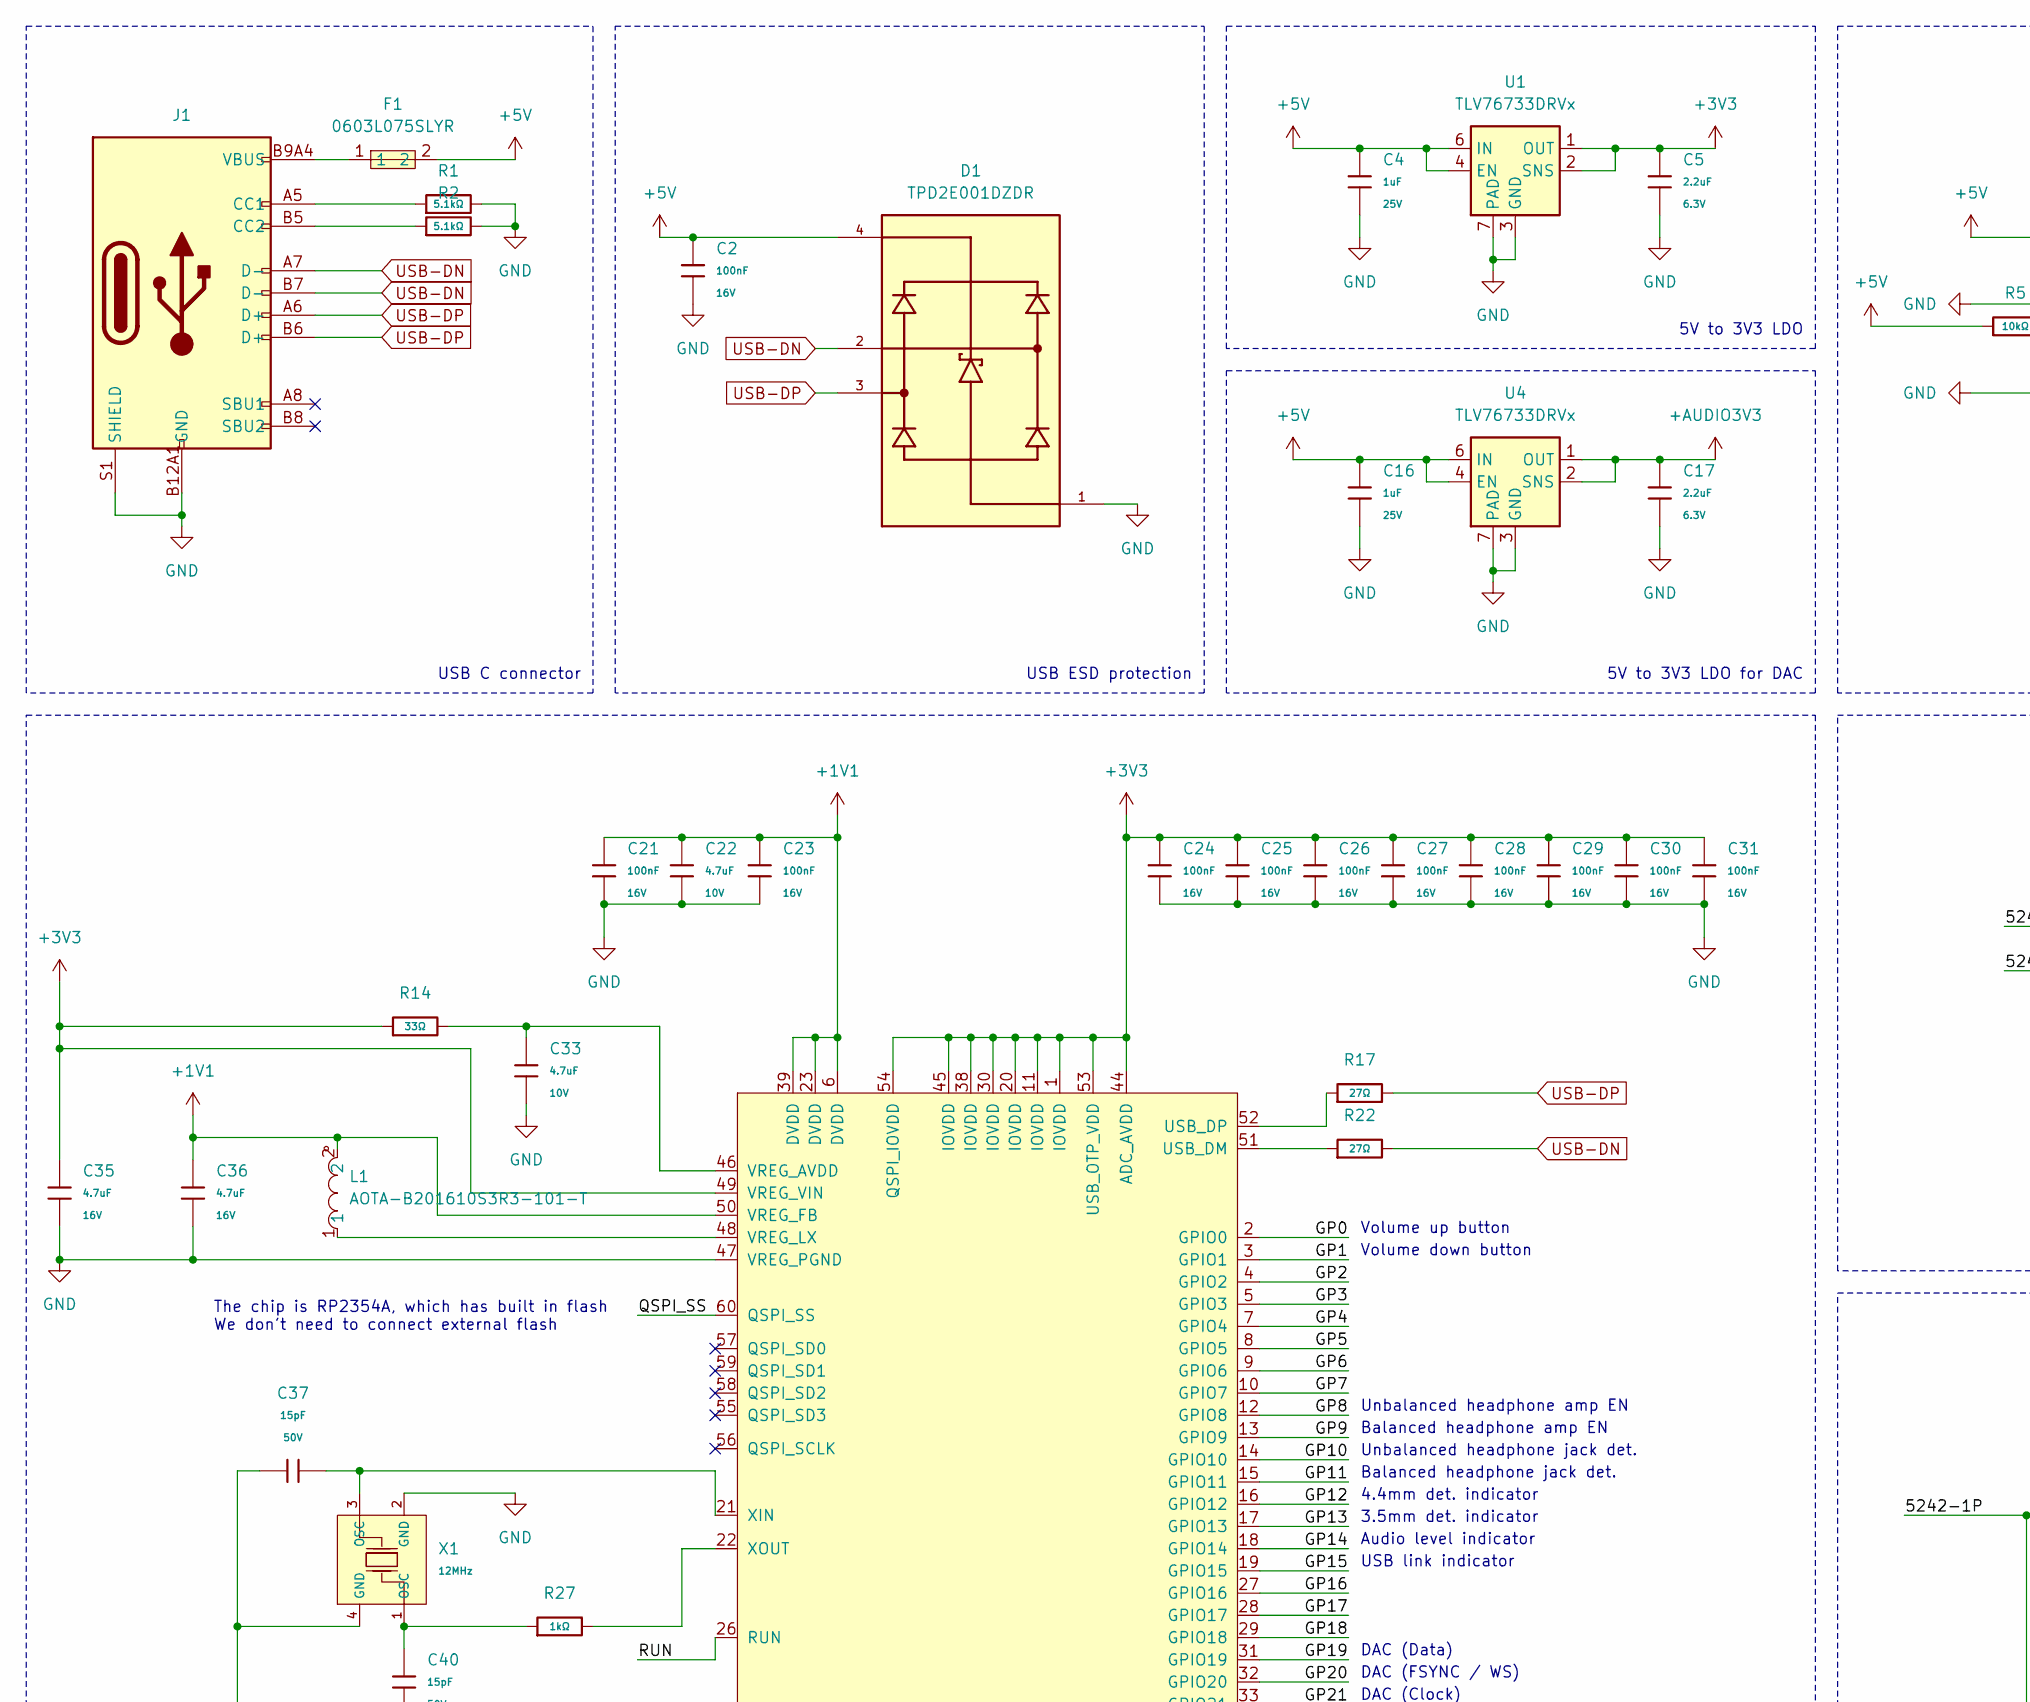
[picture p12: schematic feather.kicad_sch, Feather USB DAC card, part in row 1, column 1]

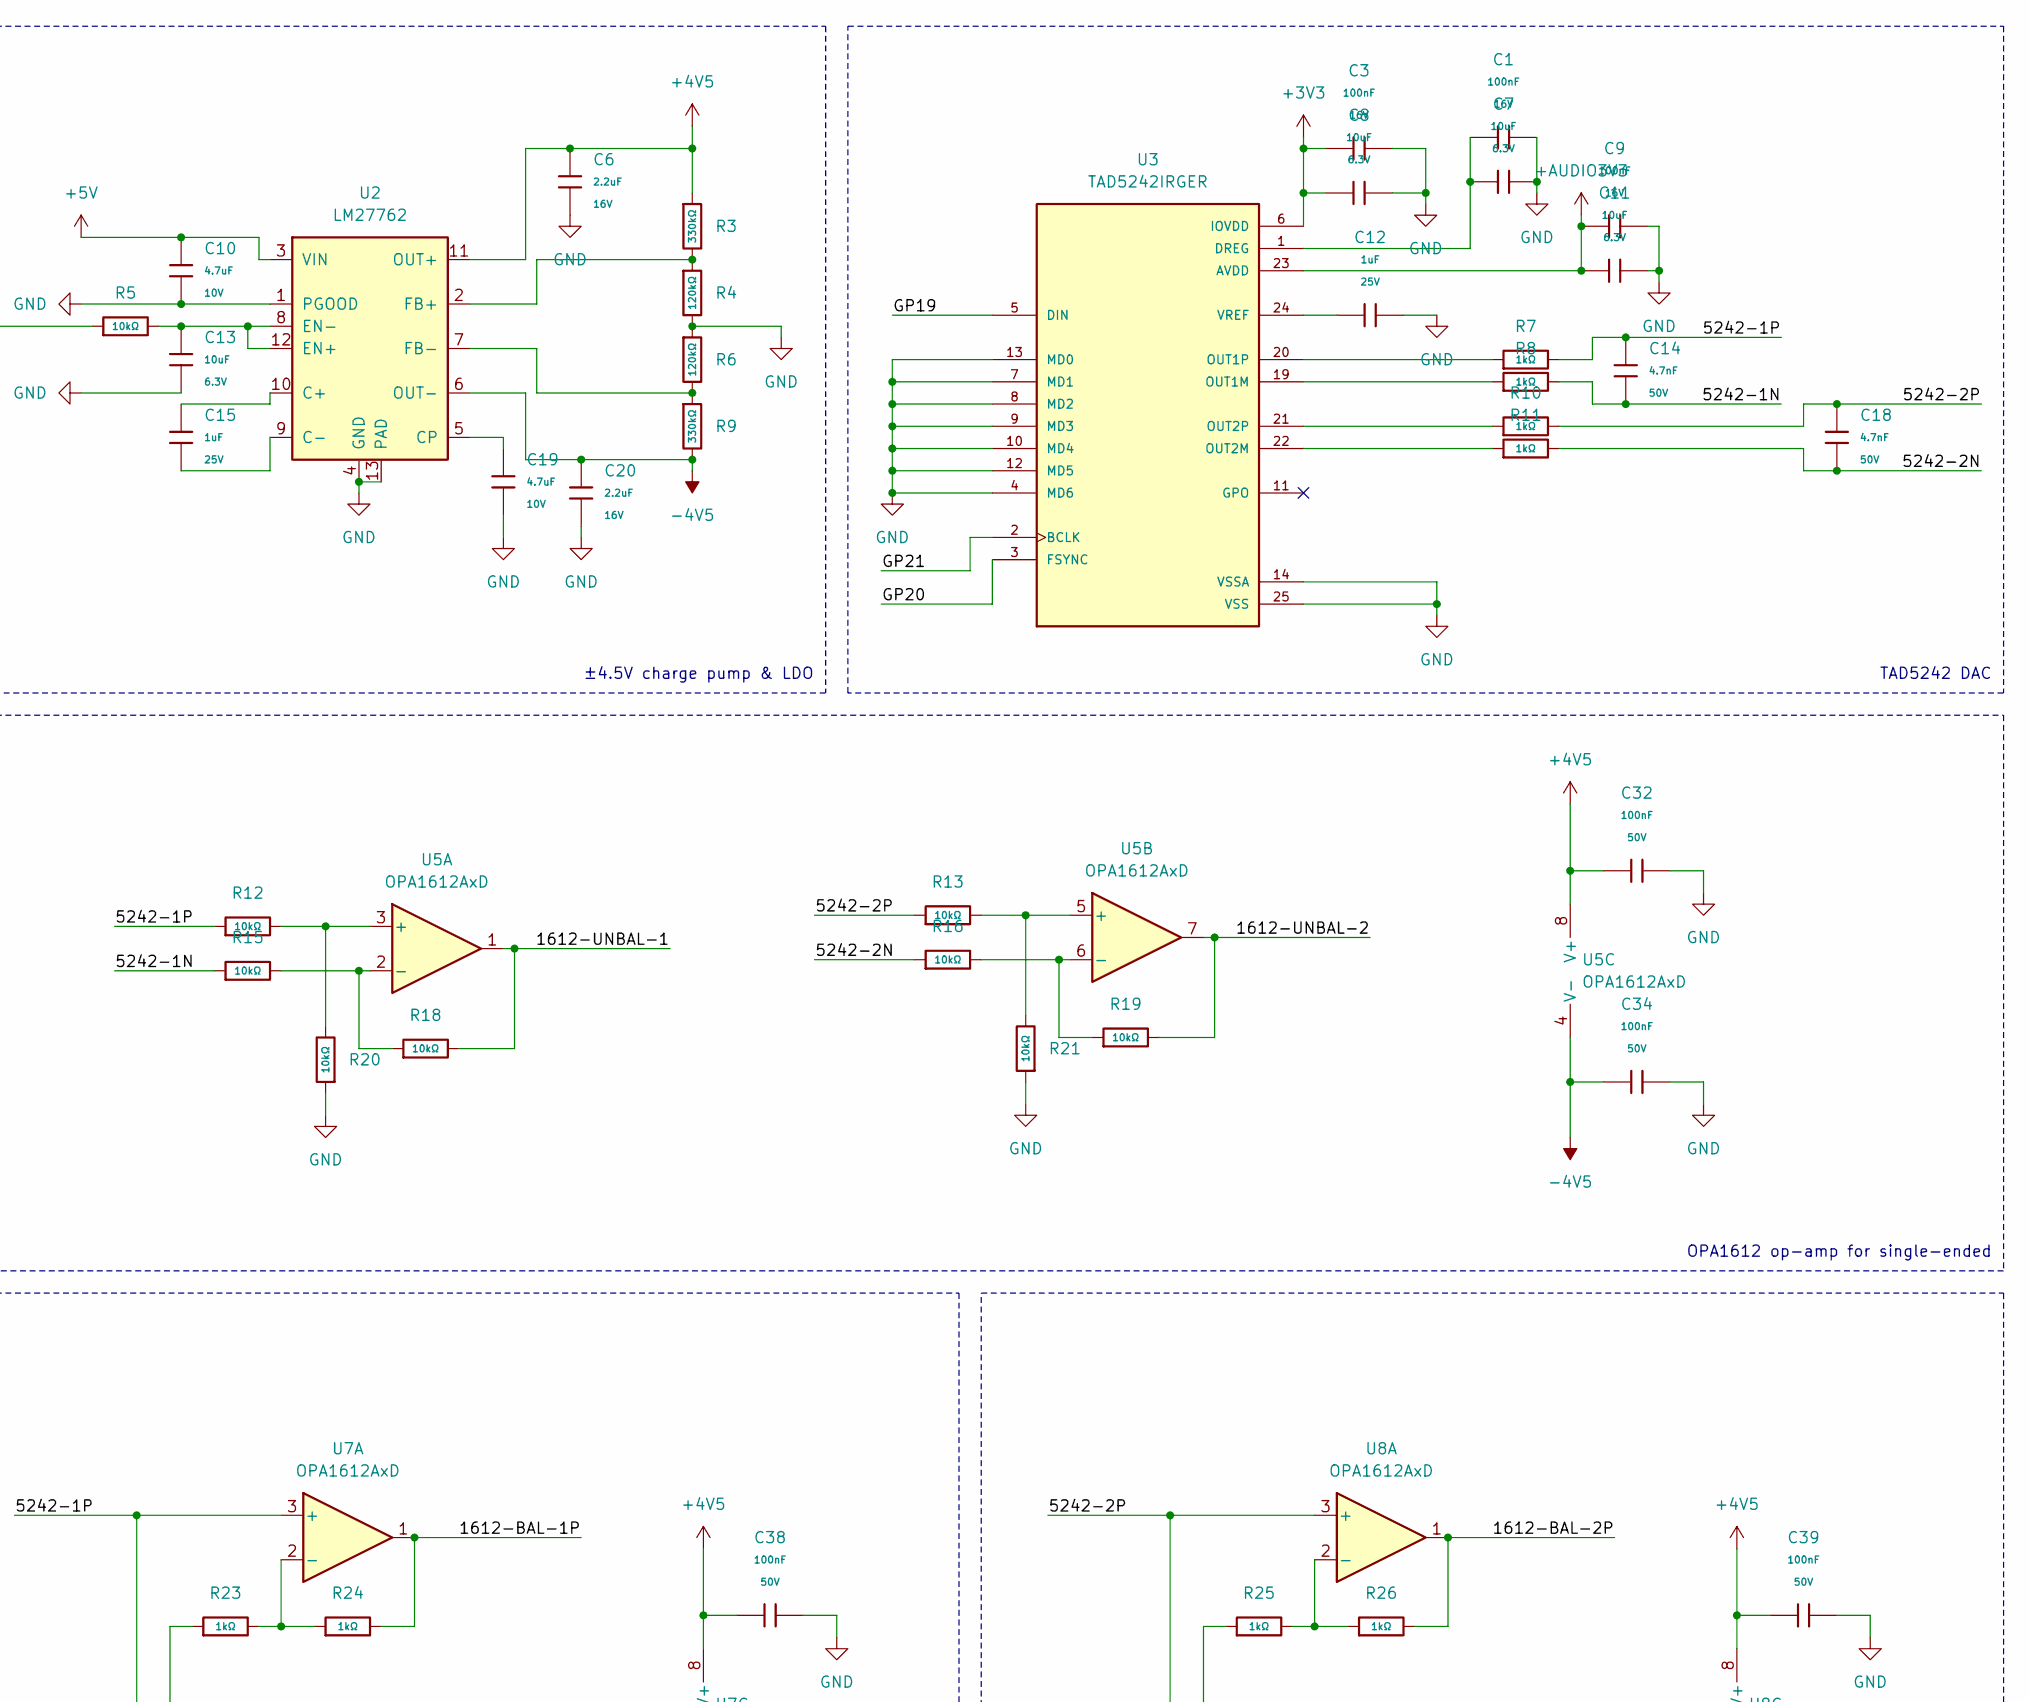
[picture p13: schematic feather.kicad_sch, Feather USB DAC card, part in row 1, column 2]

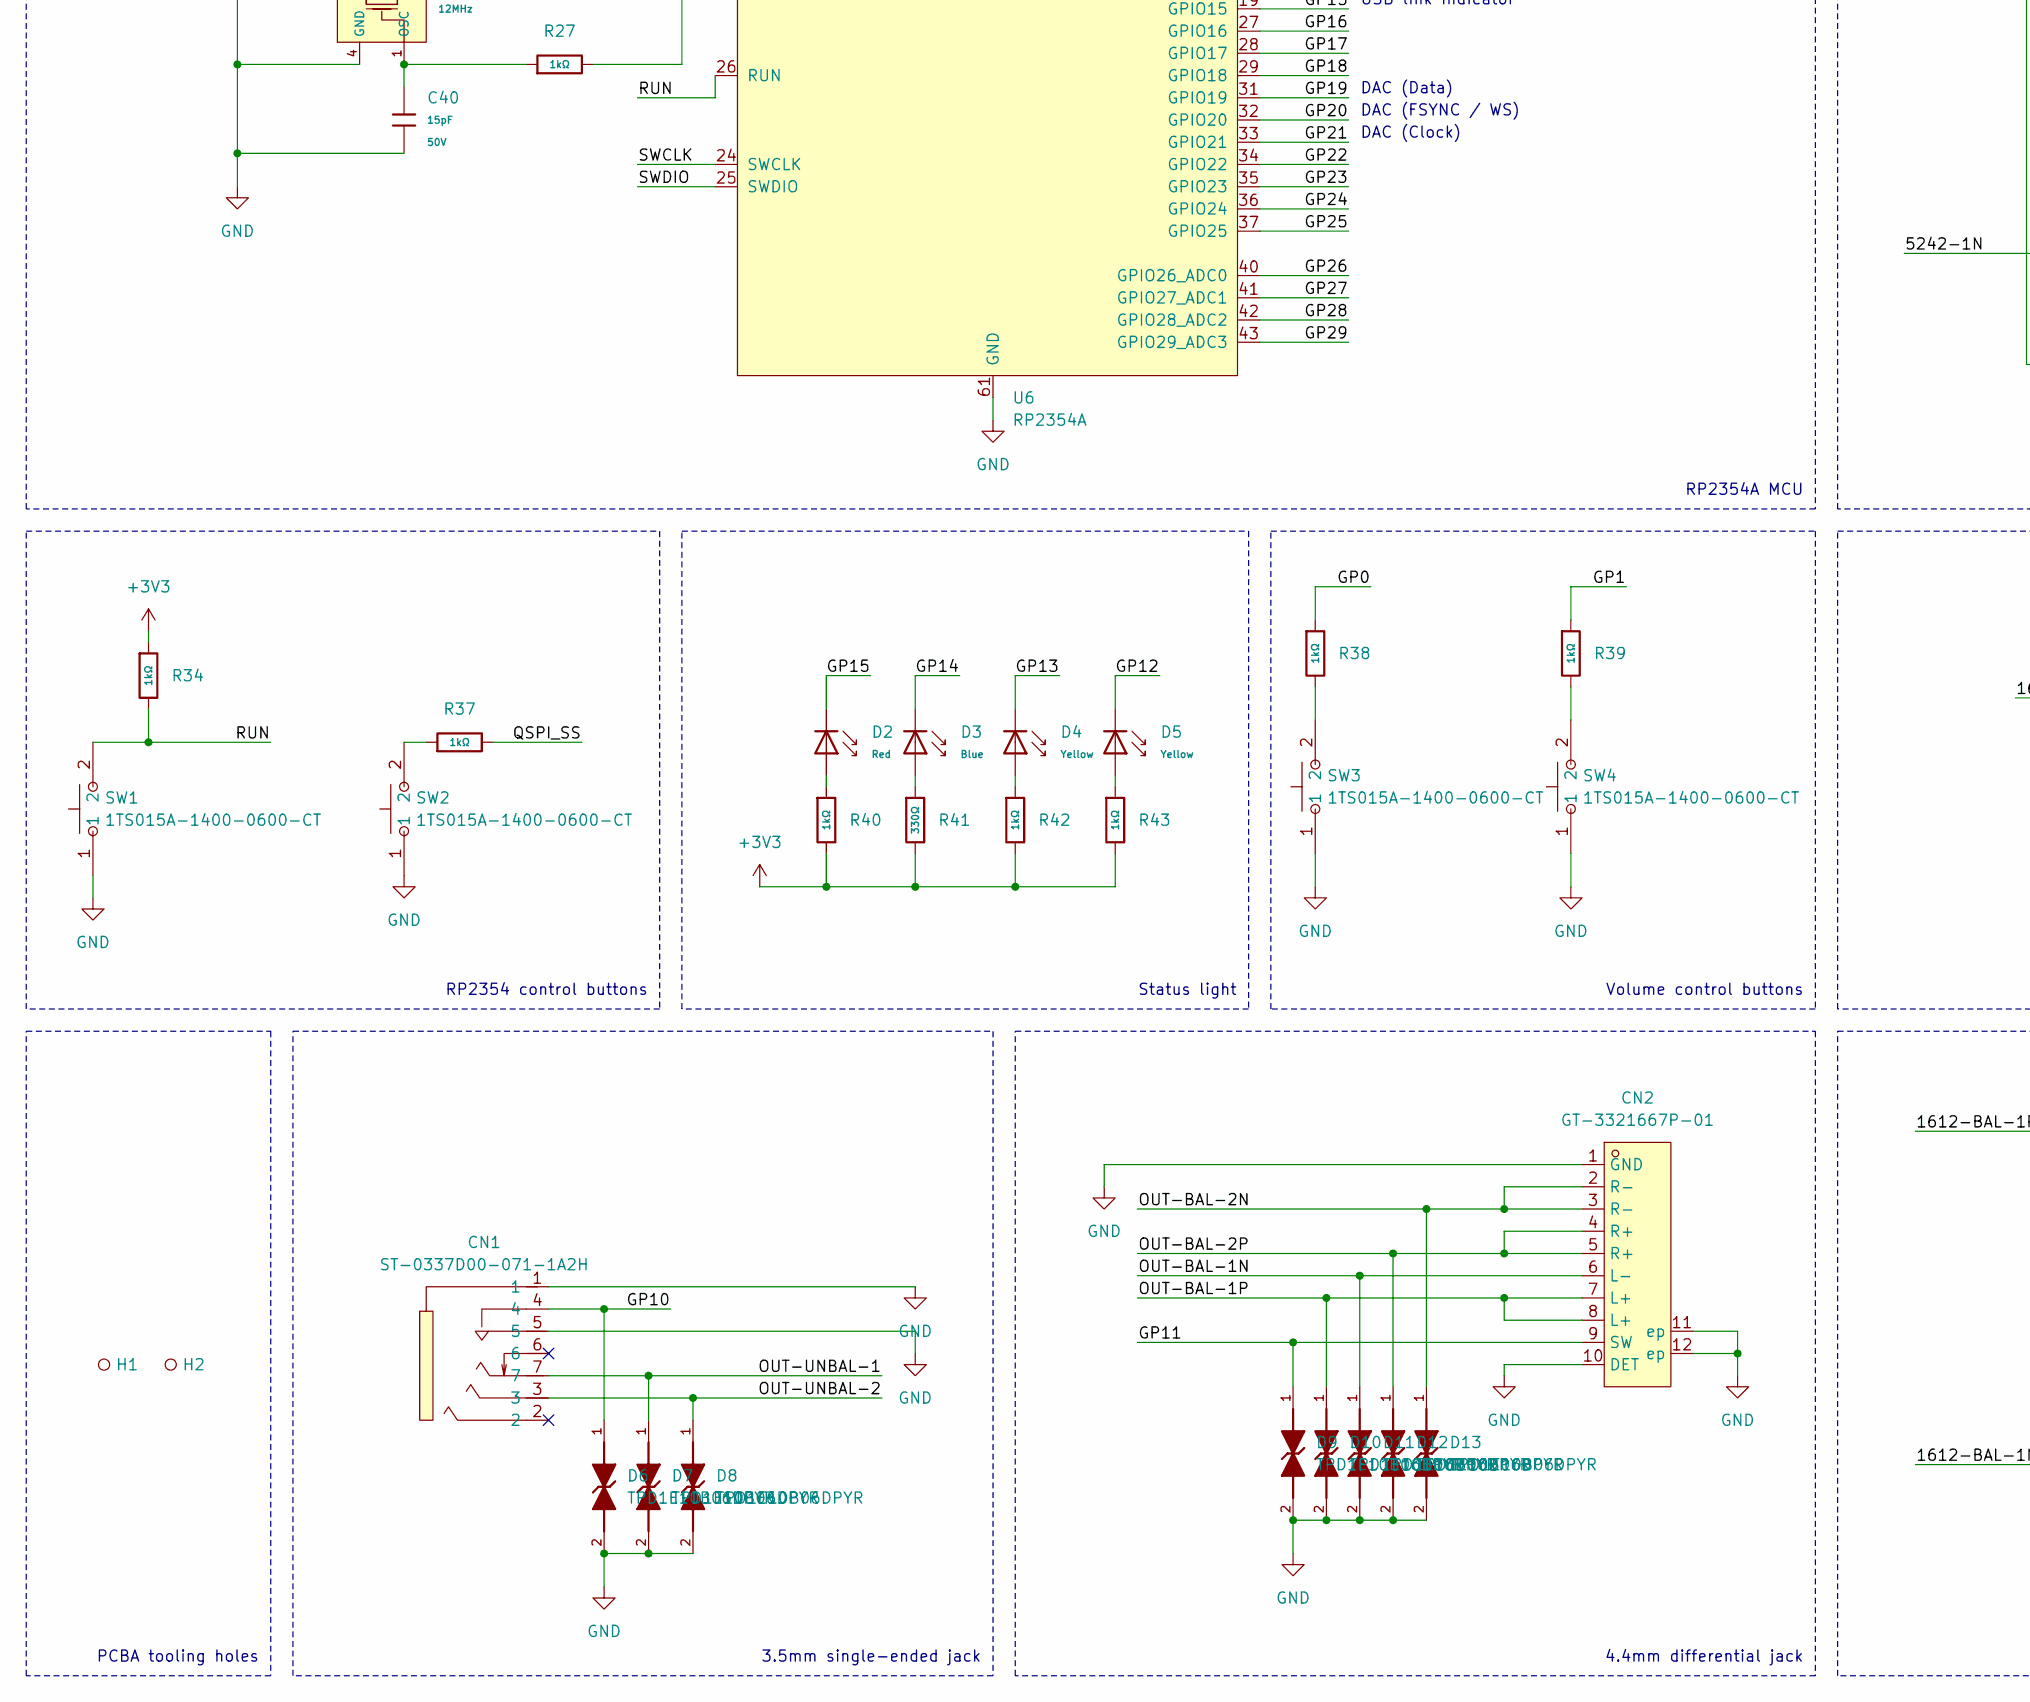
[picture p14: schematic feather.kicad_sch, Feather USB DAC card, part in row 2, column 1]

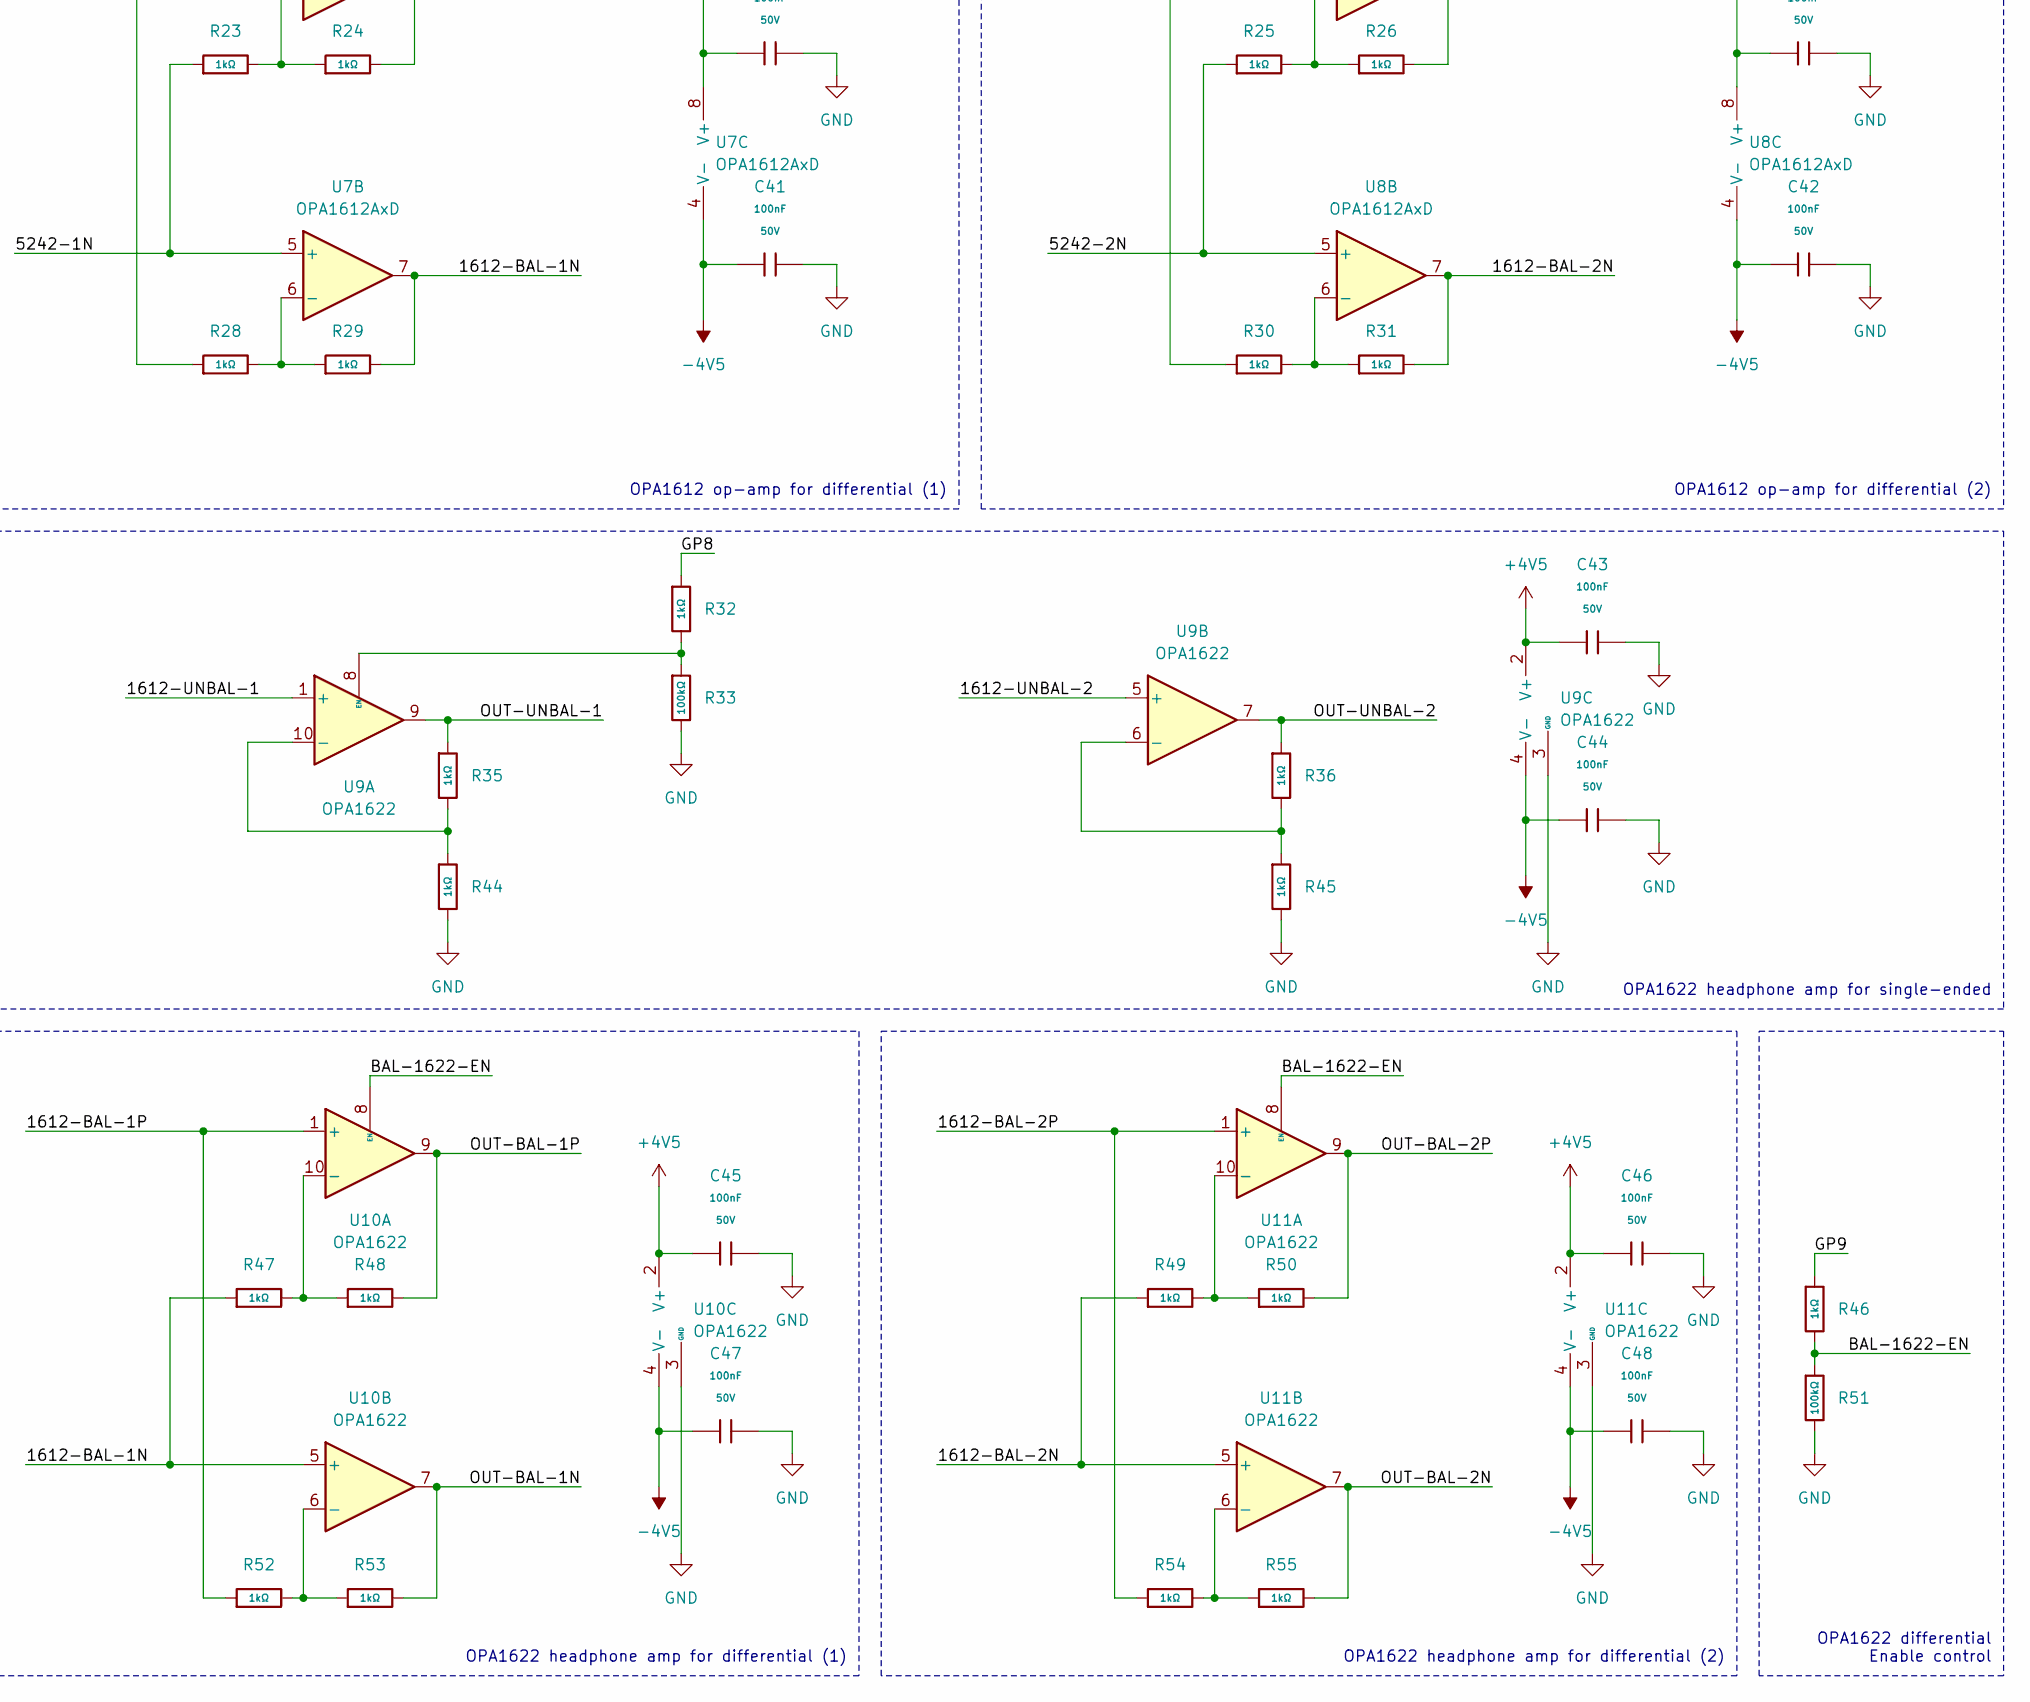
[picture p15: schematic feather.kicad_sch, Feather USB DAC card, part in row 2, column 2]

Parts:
C1, C2, C3, C9, C21, C23, C24, C25, C26, C27, C28, C29, C30, C31: 100nF; C_0402; Voltage Rated 16V; Tolerance ±10%; Part CL05B104KO5NNNC; LCSC C1525
C4, C12, C15, C16: 1uF; C_0402; Voltage Rated 25V; Tolerance ±10%; Part CL05A105KA5NQNC; LCSC C52923
C5, C17: 2.2uF; C_0402; Voltage Rated 6.3V; Tolerance ±20%; Part CL05A225MQ5NSNC; LCSC C12530
C6, C20: 2.2uF; C_0603; Voltage Rated 16V; Tolerance ±10%; Part CL10A225KO8NNNC; LCSC C23630
C7, C8, C11, C13: 10uF; C_0402; Voltage Rated 6.3V; Tolerance ±20%; Part CL05A106MQ5NUNC; LCSC C15525
C10, C19, C22, C33: 4.7uF; C_0402; Voltage Rated 10V; Tolerance ±20%; Part CL05A475MP5NRNC; LCSC C23733
C14, C18: 4.7nF; C_0402; Voltage Rated 50V; Tolerance ±10%; Part 0402B472K500NT; LCSC C1538
C32: 100nF; C_0402; Voltage Rated 50V; Tolerance ±10%; Part CL05B104KB54PNC; LCSC C1525
C34, C38, C39, C41, C42, C43, C44, C45, C46, C47, C48: 100nF; C_0402; Voltage Rated 50V; Tolerance ±10%; Part CL05B104KB54PNC; LCSC C307331
C35, C36: 4.7uF; C_0603; Voltage Rated 16V; Tolerance ±10%; Part CL10A475KO8NNNC; LCSC C19666
C37, C40: 15pF; C_0402; Voltage Rated 50V; Tolerance ±5%; Part 0402CG150J500NT; LCSC C1548
CN1: ST-0337D00-071-1A2H; AUDIO-TH_ST-0337D00-071-1A2H; MPN ST-0337D00-071-1A2H; LCSC Part C2829972
CN2: GT-3321667P-01; AUDIO-TH_GT-3321667P-01; MPN GT-3321667P-01; LCSC Part C2762984
D1: TPD2E001DZDR; SOT192P237X122-4N; PARTREV I; LCSC C89411
D2: Red; D_0603; Forward Voltage (VF) 1.6V~2.6V; Part KT-0603R; LCSC C2286
D3: Blue; D_0603; LCSC C7496823
D4, D5: Yellow; D_0603; Forward Voltage (VF) 1.6V~2.6V; Part NCD0603Y2; LCSC C89811
D6, D7, D8, D9, D10, D11, D12, D13: TPD1E10B06DPYR; DIO_TPD1E10B06DPYR; PARTREV G; LCSC C48260
F1: 0603L075SLYR; Fuse_0603_1608Metric; LCSC Part C207016
H1, H2: Hole_Tooling_JLCPCB
J1: Connector, USB-TYPE-C-16P; TYPE-C-SMD_HX-TYPE-C-16PIN; LCSC C2927039
L1: AOTA-B201610S3R3-101-T; IND-SMD_L2.0-W1.6_AOTA-B201610S3R3-101-T; LCSC Part C42411119
R1, R2: 5.1kΩ; R_0402; Overload Voltage (Max) 50V; Tolerance ±1%; Part 0402WGF5101TCE; LCSC C25905
R3, R9: 330kΩ; R_0603; Overload Voltage (Max) 75V; Tolerance ±1%; Part 0603WAF3303T5E; LCSC C23137
R4, R6: 120kΩ; R_0603; Overload Voltage (Max) 75V; Tolerance ±1%; Part 0603WAF1203T5E; LCSC C25808
R5, R18, R19, R20, R21: 10kΩ; R_0402; Overload Voltage (Max) 50V; Tolerance ±1%; Part 0402WGF1002TCE; LCSC C25744
R7, R8, R10, R11, R23, R24, R25, R26, R27, R28, R29, R30, R31, R32, R34, R35, R36, R37, R38, R39, R40, R42, R43, R44, R45, R46, R47, R48, R49, R50, R52, R53, R54, R55: 1kΩ; R_0402; Overload Voltage (Max) 50V; Tolerance ±1%; Part 0402WGF1001TCE; LCSC C11702
R12, R13, R15, R16: 10kΩ; R_0603; Overload Voltage (Max) 75V; Tolerance ±1%; Part 0603WAF1002T5E; LCSC C25804
R14: 33Ω; R_0402; Overload Voltage (Max) 50V; Tolerance ±1%; Part 0402WGF330JTCE; LCSC C25105
R17, R22: 27Ω; R_0603; Overload Voltage (Max) 75V; Tolerance ±1%; Part 0603WAF270JT5E; LCSC C25190
R33, R51: 100kΩ; R_0402; Overload Voltage (Max) 50V; Tolerance ±1%; Part 0402WGF1003TCE; LCSC C25741
R41: 330Ω; R_0402; Overload Voltage (Max) 50V; Tolerance ±1%; Part 0402WGF3300TCE; LCSC C25104
SW1, SW2, SW3, SW4: 1TS015A-1400-0600-CT; SW-SMD_L3.0-W2.0-LS3.5; LCSC Part C319433
U1, U4: TLV76733DRVx; WSON-6-1EP_2x2mm_P0.65mm_EP1x1.6mm_ThermalVias; LCSC C2848334
U2: LM27762; WSON-12-1EP_3x2mm_P0.5mm_EP1x2.65_ThermalVias; LCSC C473398
U3: TAD5242IRGER; IC_TAD5242IRGER; PARTREV A; LCSC C42414591
U5, U7, U8: OPA1612AxD; WSON-8-1EP_3x3mm_P0.5mm_EP1.2x2mm_ThermalVias; LCSC C2058640
U6: RP2354A; QFN-60-1EP_7x7mm_P0.4mm_EP3.4x3.4mm_ThermalVias; LCSC C42411118
U9, U10, U11: OPA1622; Texas_S-PVSON-N10_ThermalVias; LCSC C2876559
X1: 12MHz; OSC-SMD_4P-L3.2-W2.5-BL_SIT8008BI; LCSC C20625731

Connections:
+1V1: C21.1, C22.1, C23.1, C36.1, L1.2, U6.6 (DVDD), U6.23 (DVDD), U6.39 (DVDD), U6.50 (VREG_FB)
+3V3: C3.1, C5.1, C8.1, C24.1, C25.1, C26.1, C27.1, C28.1, C29.1, C30.1, C31.1, C35.1, R14.1, R34.1, R40.2, R41.2, R42.2, R43.2, U1.1 (OUT), U1.2 (SNS), U3.6 (IOVDD), U6.1 (IOVDD), U6.11 (IOVDD), U6.20 (IOVDD), U6.30 (IOVDD), U6.38 (IOVDD), U6.44 (ADC_AVDD), U6.45 (IOVDD), U6.49 (VREG_VIN), U6.53 (USB_OTP_VDD), U6.54 (QSPI_IOVDD)
+4V5: C6.1, C32.1, C38.1, C39.1, C43.1, C45.1, C46.1, R3.1, U2.11 (OUT+), U5.8 (V+), U7.8 (V+), U8.8 (V+), U9.2 (V+), U10.2 (V+), U11.2 (V+)
+5V: C2.1, C4.1, C10.1, C16.1, D1.4, F1.2, R5.1, U1.4 (EN), U1.6 (IN), U2.3 (VIN), U4.4 (EN), U4.6 (IN)
+AUDIO3V3: C9.1, C11.1, C17.1, U3.23 (AVDD), U4.1 (OUT), U4.2 (SNS)
-4V5: C20.1, C34.1, C41.1, C42.1, C44.1, C47.1, C48.1, R9.2, U2.6 (OUT-), U5.4 (V-), U7.4 (V-), U8.4 (V-), U9.4 (V-), U9.11 (V-), U10.4 (V-), U10.11 (V-), U11.4 (V-), U11.11 (V-)
/1612-BAL-1N: R29.2, R47.1, U7.7, U10.5 (+)
/1612-BAL-1P: R24.2, R52.1, U7.1, U10.1 (+)
/1612-BAL-2N: R31.2, R49.1, U8.7, U11.5 (+)
/1612-BAL-2P: R26.2, R54.1, U8.1, U11.1 (+)
/1612-UNBAL-1: R18.2, U5.1, U9.1 (+)
/1612-UNBAL-2: R19.2, U5.7, U9.5 (+)
/5242-1N: C14.2, R8.2, R15.1, R23.1, U7.5 (+)
/5242-1P: C14.1, R7.2, R12.1, R28.1, U7.3 (+)
/5242-2N: C18.2, R11.2, R16.1, R25.1, U8.5 (+)
/5242-2P: C18.1, R10.2, R13.1, R30.1, U8.3 (+)
/BAL-1622-EN: R46.2, R51.1, U10.8 (EN), U11.8 (EN)
/GP0: R38.1, U6.2 (GPIO0)
/GP1: R39.1, U6.3 (GPIO1)
/GP2: U6.4 (GPIO2)
/GP3: U6.5 (GPIO3)
/GP4: U6.7 (GPIO4)
/GP5: U6.8 (GPIO5)
/GP6: U6.9 (GPIO6)
/GP7: U6.10 (GPIO7)
/GP8: R32.1, U6.12 (GPIO8)
/GP9: R46.1, U6.13 (GPIO9)
/GP10: CN1.4, D6.1, U6.14 (GPIO10)
/GP11: CN2.9 (SW), D9.1, U6.15 (GPIO11)
/GP12: D5.1, U6.16 (GPIO12)
/GP13: D4.1, U6.17 (GPIO13)
/GP14: D3.1, U6.18 (GPIO14)
/GP15: D2.1, U6.19 (GPIO15)
/GP16: U6.27 (GPIO16)
/GP17: U6.28 (GPIO17)
/GP18: U6.29 (GPIO18)
/GP19: U3.5 (DIN), U6.31 (GPIO19)
/GP20: U3.3 (FSYNC), U6.32 (GPIO20)
/GP21: U3.2 (BCLK), U6.33 (GPIO21)
/GP22: U6.34 (GPIO22)
/GP23: U6.35 (GPIO23)
/GP24: U6.36 (GPIO24)
/GP25: U6.37 (GPIO25)
/GP26: U6.40 (GPIO26_ADC0)
/GP27: U6.41 (GPIO27_ADC1)
/GP28: U6.42 (GPIO28_ADC2)
/GP29: U6.43 (GPIO29_ADC3)
/OUT-BAL-1N: CN2.6 (L-), D11.1, R53.2, U10.7
/OUT-BAL-1P: CN2.7 (L+), CN2.8 (L+), D10.1, R48.2, U10.9
/OUT-BAL-2N: CN2.2 (R-), CN2.3 (R-), D13.1, R55.2, U11.7
/OUT-BAL-2P: CN2.4 (R+), CN2.5 (R+), D12.1, R50.2, U11.9
/OUT-UNBAL-1: CN1.7, D7.1, R35.1, U9.9
/OUT-UNBAL-2: CN1.3, D8.1, R36.1, U9.7
/QSPI_SS: R37.2, U6.60 (QSPI_SS)
/RUN: R34.2, SW1.2, U6.26 (RUN)
/SWCLK: U6.24 (SWCLK)
/SWDIO: U6.25 (SWDIO)
GND: C1.2, C2.2, C3.2, C4.2, C5.2, C6.2, C7.2, C8.2, C9.2, C10.2, C11.2, C12.2, C13.2, C16.2, C17.2, C19.2, C20.2, C21.2, C22.2, C23.2, C24.2, C25.2, C26.2, C27.2, C28.2, C29.2, C30.2, C31.2, C32.2, C33.2, C34.2, C35.2, C36.2, C37.1, C38.2, C39.2, C40.2, C41.2, C42.2, C43.2, C44.2, C45.2, C46.2, C47.2, C48.2, CN1.1, CN1.5, CN2.1 (GND), CN2.10 (DET), CN2.11 (ep), CN2.12 (ep), D1.1, D6.2, D7.2, D8.2, D9.2, D10.2, D11.2, D12.2, D13.2, J1.A12B1 (GND), J1.B12A1 (GND), J1.S1 (SHIELD), R1.2, R2.2, R4.2, R6.1, R20.1, R21.1, R33.2, R44.2, R45.2, R51.2, SW1.1, SW2.1, SW3.1, SW4.1, U1.3 (GND), U1.5 (GND), U1.7 (PAD), U2.1 (PGOOD), U2.4 (GND), U2.13 (PAD), U3.4 (MD6), U3.7 (MD1), U3.8 (MD2), U3.9 (MD3), U3.10 (MD4), U3.12 (MD5), U3.13 (MD0), U3.14 (VSSA), U3.15 (VSSA), U3.16 (VSSA), U3.17 (VSSA), U3.18 (VSSA), U3.25 (VSS), U3.A1 (VSS), U3.A2 (VSS), U3.A3 (VSS), U3.A4 (VSS), U4.3 (GND), U4.5 (GND), U4.7 (PAD), U6.47 (VREG_PGND), U6.61 (GND), U9.3 (GND), U10.3 (GND), U11.3 (GND), X1.2 (GND), X1.4 (GND)
unnamed: C40.1, R27.1, X1.1 (OSC)
unnamed: D2.2, R40.1
unnamed: D3.2, R41.1
unnamed: D4.2, R42.1
unnamed: D5.2, R43.1
unnamed: F1.1, J1.A9B4 (VBUS), J1.B9A4 (VBUS)
unnamed: J1.A5 (CC1), R1.1
unnamed: J1.B5 (CC2), R2.1
unnamed: R37.1, SW2.2
unnamed: R38.2, SW3.2
unnamed: R39.2, SW4.2
unnamed: C15.1, U2.10 (C+)
unnamed: C15.2, U2.9 (C-)
unnamed: C19.1, U2.5 (CP)
unnamed: C13.1, R5.2, U2.8 (EN-), U2.12 (EN+)
unnamed: R3.2, R4.1, U2.2 (FB+)
unnamed: R6.2, R9.1, U2.7 (FB-)
unnamed: C1.1, C7.1, U3.1 (DREG)
unnamed: R8.1, U3.19 (OUT1M)
unnamed: R7.1, U3.20 (OUT1P)
unnamed: R11.1, U3.22 (OUT2M)
unnamed: R10.1, U3.21 (OUT2P)
unnamed: C12.1, U3.24 (VREF)
unnamed: R12.2, R20.2, U5.3 (+)
unnamed: R15.2, R18.1, U5.2 (-)
unnamed: R13.2, R21.2, U5.5 (+)
unnamed: R16.2, R19.1, U5.6 (-)
unnamed: R22.1, U6.51 (USB_DM)
unnamed: R17.1, U6.52 (USB_DP)
unnamed: C33.1, R14.2, U6.46 (VREG_AVDD)
unnamed: L1.1, U6.48 (VREG_LX)
unnamed: C37.2, U6.21 (XIN), X1.3 (OSC)
unnamed: R27.2, U6.22 (XOUT)
unnamed: R23.2, R24.1, U7.2 (-)
unnamed: R28.2, R29.1, U7.6 (-)
unnamed: R25.2, R26.1, U8.2 (-)
unnamed: R30.2, R31.1, U8.6 (-)
unnamed: R35.2, R44.1, U9.10 (-)
unnamed: R32.2, R33.1, U9.8 (EN)
unnamed: R36.2, R45.1, U9.6 (-)
unnamed: R47.2, R48.1, U10.10 (-)
unnamed: R52.2, R53.1, U10.6 (-)
unnamed: R49.2, R50.1, U11.10 (-)
unnamed: R54.2, R55.1, U11.6 (-)
USB-DN: D1.2, J1.A7 (D-), J1.B7 (D-), R22.2
USB-DP: D1.3, J1.A6 (D+), J1.B6 (D+), R17.2

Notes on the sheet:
Status light
3.5mm single-ended jack
OPA1622 headphone amp for single-ended
Unbalanced headphone amp EN
OPA1622 headphone amp for differential (1)
RP2354 control buttons
USB link indicator
OPA1622 differential Enable control
USB C connector
5V to 3V3 LDO
Volume up button
OPA1612 op-amp for differential (2)
Unbalanced headphone jack det.
RP2354A MCU
Volume control buttons
DAC (FSYNC / WS)
OPA1612 op-amp for differential (1)
TAD5242 DAC
4.4mm differential jack
Audio level indicator
The chip is RP2354A, which has built in flash We don't need to connect external flash
5V to 3V3 LDO for DAC
DAC (Clock)
PCBA tooling holes
USB ESD protection
Volume down button
4.4mm det. indicator
DAC (Data)
OPA1612 op-amp for single-ended
OPA1622 headphone amp for differential (2)
±4.5V charge pump & LDO
Balanced headphone amp EN
3.5mm det. indicator
Balanced headphone jack det.

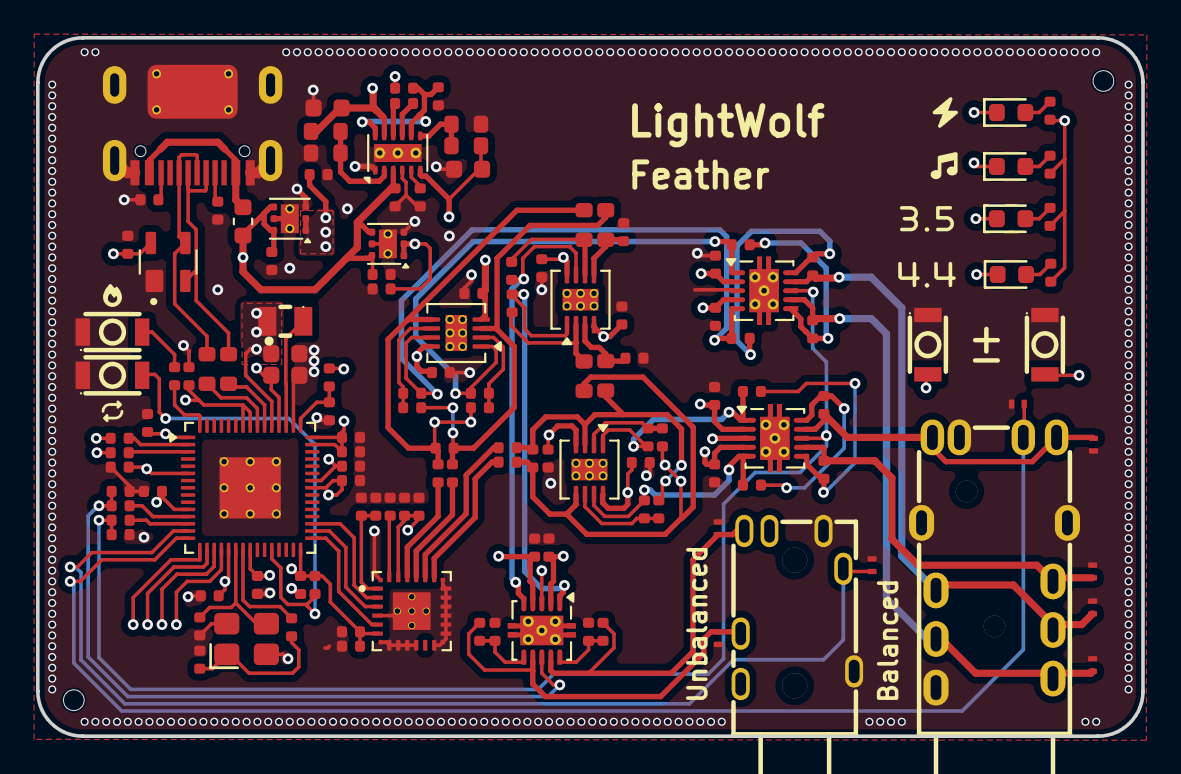
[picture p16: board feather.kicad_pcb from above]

Board: 4 copper layers, 61.4 x 38.8 mm, 139 parts (0 on the bottom side), 85 nets.

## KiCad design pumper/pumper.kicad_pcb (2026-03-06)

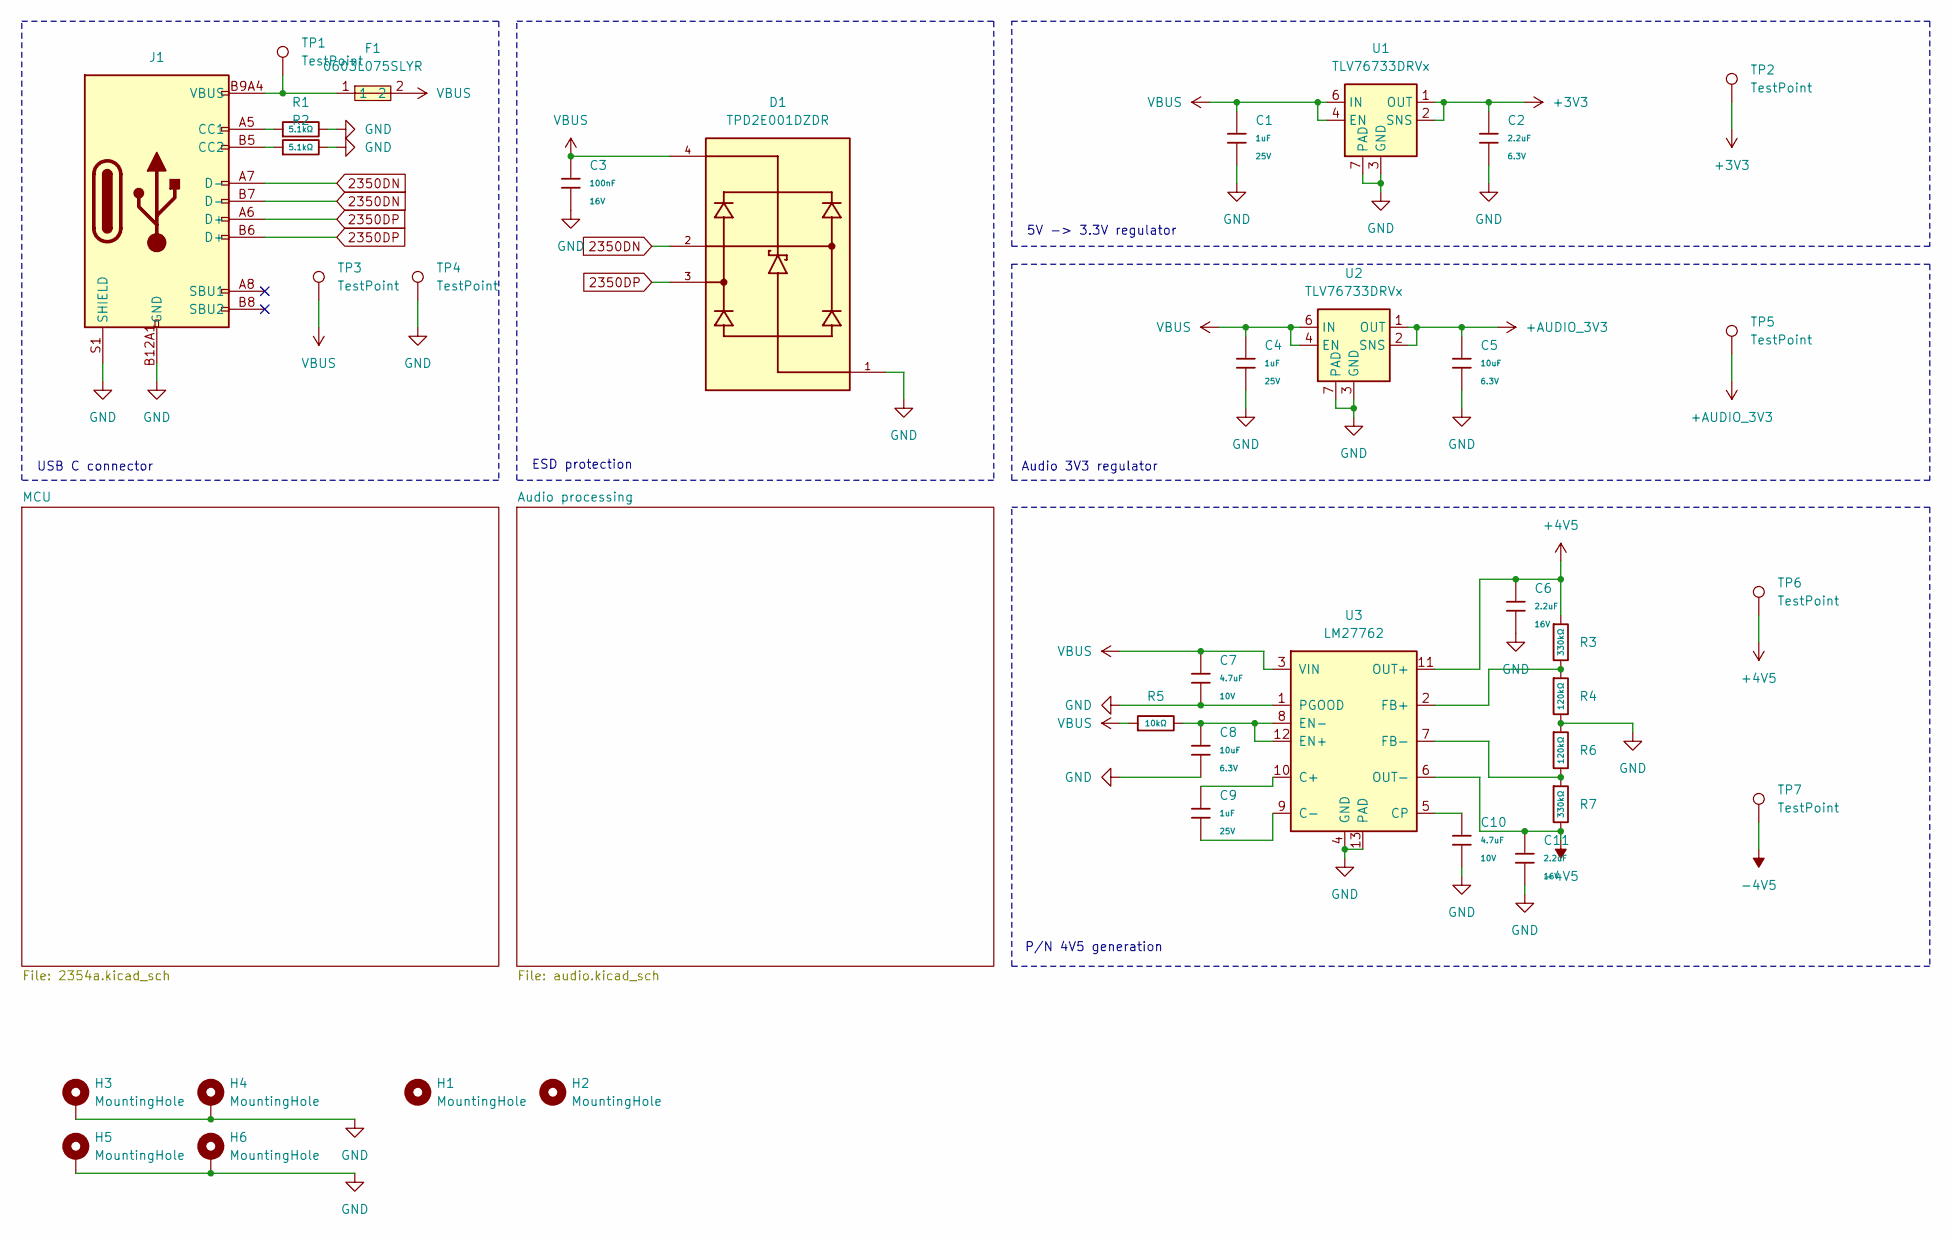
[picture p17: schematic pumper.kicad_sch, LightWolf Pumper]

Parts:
C1, C4, C9: 1uF; C_0402; Voltage Rated 25V; Tolerance ±10%; Part CL05A105KA5NQNC; LCSC C52923
C2: 2.2uF; C_0402; Voltage Rated 6.3V; Tolerance ±20%; Part CL05A225MQ5NSNC; LCSC C12530
C3: 100nF; C_0402; Voltage Rated 16V; Tolerance ±10%; Part CL05B104KO5NNNC; LCSC C1525
C5, C8: 10uF; C_0402; Voltage Rated 6.3V; Tolerance ±20%; Part CL05A106MQ5NUNC; LCSC C15525
C6, C11: 2.2uF; C_0603; Voltage Rated 16V; Tolerance ±10%; Part CL10A225KO8NNNC; LCSC C23630
C7, C10: 4.7uF; C_0402; Voltage Rated 10V; Tolerance ±20%; Part CL05A475MP5NRNC; LCSC C23733
D1: TPD2E001DZDR; SOT192P237X122-4N; PARTREV I
F1: 0603L075SLYR; F0603; LCSC Part C207016
H1, H2: MountingHole; ToolingHole_1.152mm
H3, H4, H5, H6: MountingHole; MountingHole_2.2mm_M2_Pad_Via
J1: Connector, USB-TYPE-C-16P; TYPE-C-SMD_HX-TYPE-C-16PIN; LCSC C2927039
R1, R2: 5.1kΩ; R_0402; Overload Voltage (Max) 50V; Tolerance ±1%; Part 0402WGF5101TCE; LCSC C25905
R3, R7: 330kΩ; R_0402; Overload Voltage (Max) 50V; Tolerance ±1%; Part 0402WGF3303TCE; LCSC C25778
R4, R6: 120kΩ; R_0402; Overload Voltage (Max) 50V; Tolerance ±1%; Part 0402WGF1203TCE; LCSC C25750
R5: 10kΩ; R_0402; Overload Voltage (Max) 50V; Tolerance ±1%; Part 0402WGF1002TCE; LCSC C25744
TP1, TP2, TP3, TP4, TP5, TP6, TP7: TestPoint; TestPoint_Pad_D1.0mm
U1, U2: TLV76733DRVx; WSON-6-1EP_2x2mm_P0.65mm_EP1x1.6mm_ThermalVias
U3: LM27762; WSON-12-1EP_3x2mm_P0.5mm_EP1x2.65_ThermalVias

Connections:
2350DN: D1.2, J1.A7 (D-), J1.B7 (D-); also elsewhere on the board
2350DP: D1.3, J1.A6 (D+), J1.B6 (D+); also elsewhere on the board
+3V3: C2.1, TP2.1, U1.1 (OUT), U1.2 (SNS); also elsewhere on the board
+4V5: C6.1, R3.1, TP6.1, U3.11 (OUT+); also elsewhere on the board
+AUDIO_3V3: C5.1, TP5.1, U2.1 (OUT), U2.2 (SNS); also elsewhere on the board
-4V5: C11.1, R7.2, TP7.1, U3.6 (OUT-); also elsewhere on the board
GND: C1.2, C2.2, C3.2, C4.2, C5.2, C6.2, C7.2, C8.2, C10.2, C11.2, D1.1, H3.1, H4.1, H5.1, H6.1, J1.A12B1 (GND), J1.B12A1 (GND), J1.S1 (SHIELD), R1.2, R2.2, R4.2, R6.1, TP4.1, U1.3 (GND), U1.5 (GND), U1.7 (PAD), U2.3 (GND), U2.5 (GND), U2.7 (PAD), U3.1 (PGOOD), U3.4 (GND), U3.13 (PAD); also elsewhere on the board
unnamed: F1.1, J1.A9B4 (VBUS), J1.B9A4 (VBUS), TP1.1
unnamed: J1.A5 (CC1), R1.1
unnamed: J1.B5 (CC2), R2.1
unnamed: C9.1, U3.10 (C+)
unnamed: C9.2, U3.9 (C-)
unnamed: C10.1, U3.5 (CP)
unnamed: C8.1, R5.2, U3.8 (EN-), U3.12 (EN+)
unnamed: R3.2, R4.1, U3.2 (FB+)
unnamed: R6.2, R7.1, U3.7 (FB-)
VBUS: C1.1, C3.1, C4.1, C7.1, D1.4, F1.2, R5.1, TP3.1, U1.4 (EN), U1.6 (IN), U2.4 (EN), U2.6 (IN), U3.3 (VIN)

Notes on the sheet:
ESD protection
Audio 3V3 regulator
P/N 4V5 generation
USB C connector
5V -> 3.3V regulator

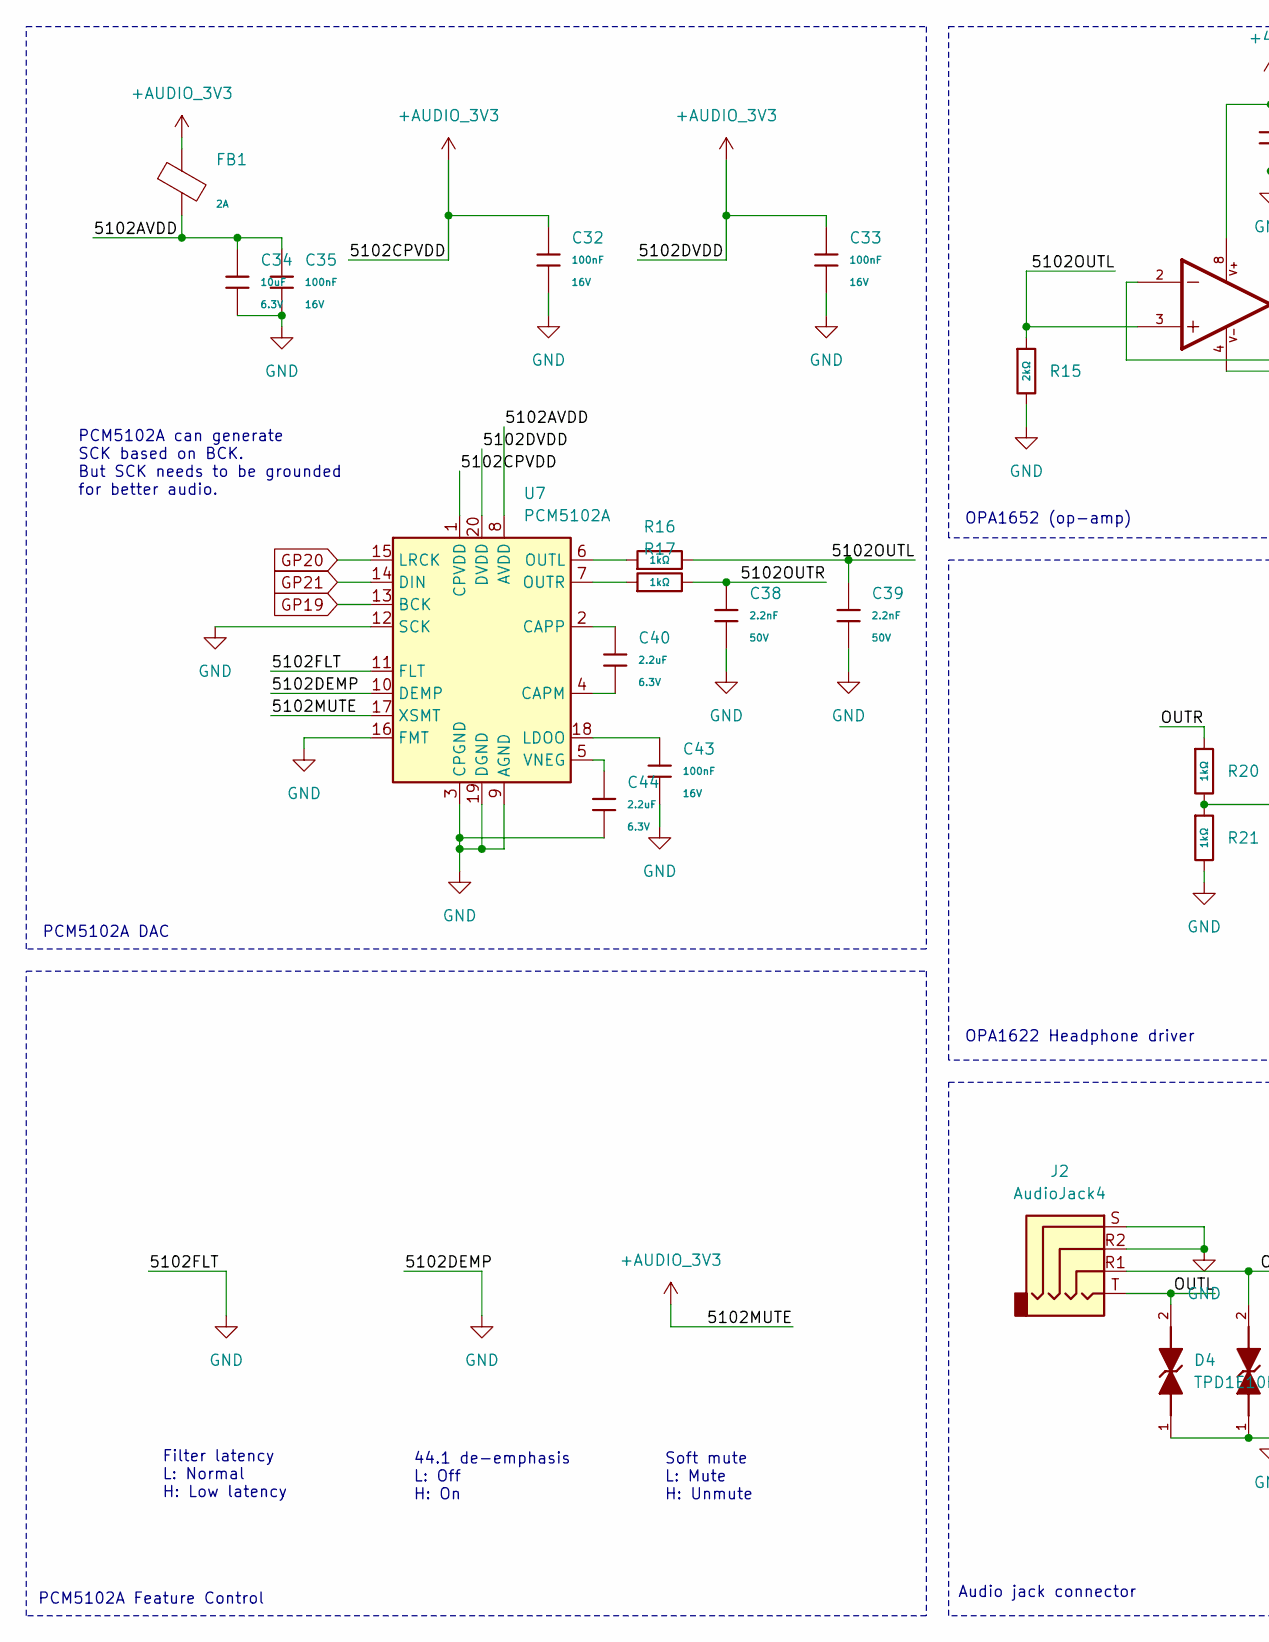
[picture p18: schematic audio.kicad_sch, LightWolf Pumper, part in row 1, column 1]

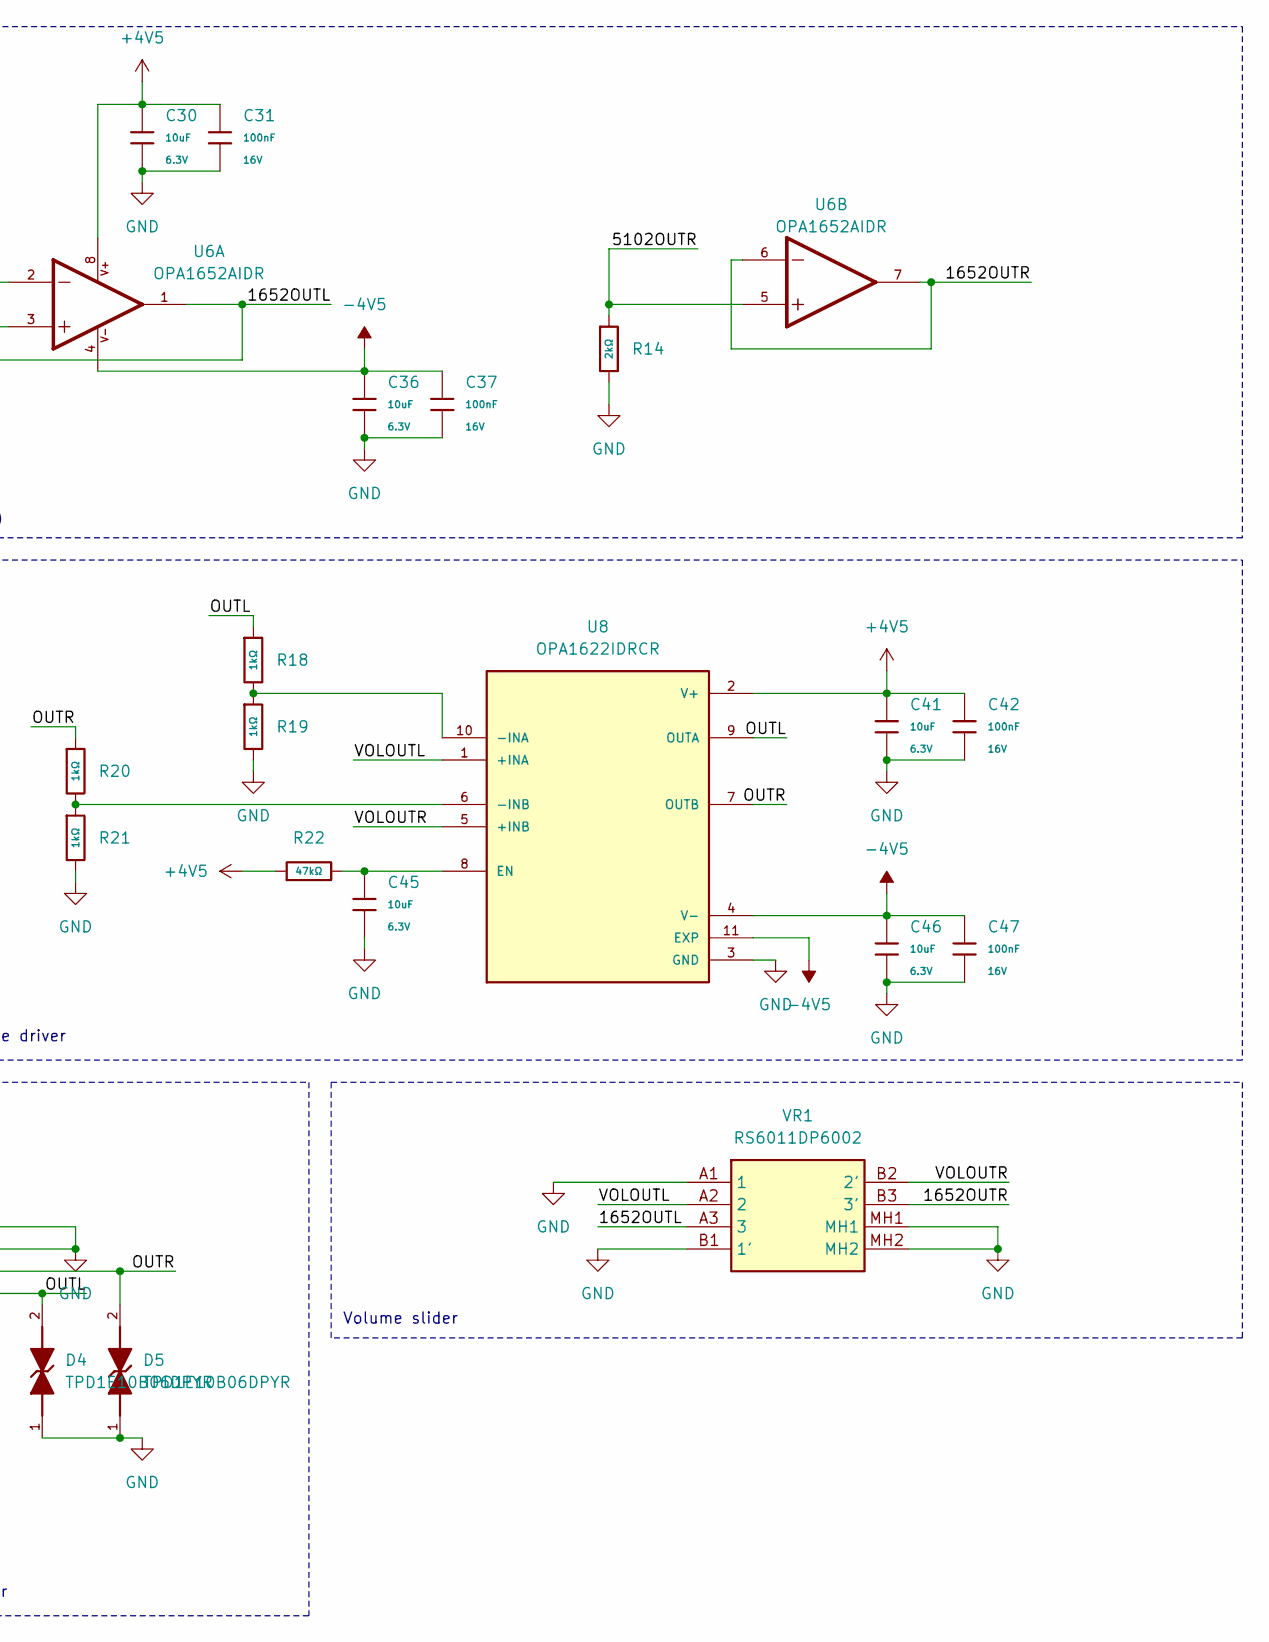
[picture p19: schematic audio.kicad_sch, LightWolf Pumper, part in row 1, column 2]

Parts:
C30, C34, C36, C41, C45, C46: 10uF; C_0402; Voltage Rated 6.3V; Tolerance ±20%; Part CL05A106MQ5NUNC; LCSC C15525
C31, C32, C33, C35, C37, C42, C43, C47: 100nF; C_0402; Voltage Rated 16V; Tolerance ±10%; Part CL05B104KO5NNNC; LCSC C1525
C38, C39: 2.2nF; C_0402; Voltage Rated 50V; Tolerance ±10%; Part 0402B222K500NT; LCSC C1531
C40, C44: 2.2uF; C_0402; Voltage Rated 6.3V; Tolerance ±20%; Part CL05A225MQ5NSNC; LCSC C12530
D4, D5: TPD1E10B06DPYR; DIO_TPD1E10B06DPYR; PARTREV G
FB1: FB_0603; Current Rating 2A; Tolerance ±25%; Part BLM18PG121SN1D; LCSC C14709
J2: AudioJack4; Jack_3.5mm_KoreanHropartsElec_PJ-320D-4A_Horizontal
R14, R15: 2kΩ; R_0402; Overload Voltage (Max) 50V; Tolerance ±1%; Part 0402WGF2001TCE; LCSC C4109
R16, R17, R18, R19, R20, R21: 1kΩ; R_0402; Overload Voltage (Max) 50V; Tolerance ±1%; Part 0402WGF1001TCE; LCSC C11702
R22: 47kΩ; R_0402; Overload Voltage (Max) 50V; Tolerance ±1%; Part 0402WGF4702TCE; LCSC C25792
U6: OPA1652AIDR; SOIC127P599X175-8N; PARTREV B
U7: PCM5102A; TSSOP-20_4.4x6.5mm_P0.65mm
U8: OPA1622IDRCR; IC_OPA1622IDRCR; PARTREV B; DigiKey_Part_Number 296-45038-1-ND
VR1: RS6011DP6002; Mouser Part Number 688-RS6011DP6002

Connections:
+4V5: C30.1, C31.1, C41.1, C42.1, R22.1, U6.8, U8.2 (V+); also elsewhere on the board
+AUDIO_3V3: C32.1, C33.1, FB1.1, U7.1 (CPVDD), U7.17 (XSMT), U7.20 (DVDD); also elsewhere on the board
-4V5: C36.1, C37.1, C46.1, C47.1, U6.4, U8.4 (V-), U8.11 (EXP), U8.12 (EXP), U8.13 (EXP), U8.14 (EXP), U8.15 (EXP); also elsewhere on the board
/Audio processing/1652OUTL: U6.1, U6.2, VR1.A3 (3)
/Audio processing/1652OUTR: U6.6, U6.7, VR1.B3 (3')
/Audio processing/5102AVDD: C34.1, C35.1, FB1.2, U7.8 (AVDD)
/Audio processing/5102OUTL: C39.1, R15.1, R16.2, U6.3
/Audio processing/5102OUTR: C38.1, R14.1, R17.2, U6.5
/Audio processing/OUTL: D4.2, J2.T, R18.1, U8.9 (OUTA)
/Audio processing/OUTR: D5.2, J2.R1, R20.1, U8.7 (OUTB)
/Audio processing/VOLOUTL: U8.1 (+INA), VR1.A2 (2)
/Audio processing/VOLOUTR: U8.5 (+INB), VR1.B2 (2')
GND: C30.2, C31.2, C32.2, C33.2, C34.2, C35.2, C36.2, C37.2, C38.2, C39.2, C41.2, C42.2, C43.2, C44.2, C45.2, C46.2, C47.2, D4.1, D5.1, J2.R2, J2.S, R14.2, R15.2, R19.2, R21.2, U7.3 (CPGND), U7.9 (AGND), U7.10 (DEMP), U7.11 (FLT), U7.12 (SCK), U7.16 (FMT), U7.19 (DGND), U8.3 (GND), VR1.A1 (1), VR1.B1 (1'), VR1.MH1, VR1.MH2; also elsewhere on the board
GP19: U7.13 (BCK); also elsewhere on the board
GP20: U7.15 (LRCK); also elsewhere on the board
GP21: U7.14 (DIN); also elsewhere on the board
unnamed: C40.2, U7.4 (CAPM)
unnamed: C40.1, U7.2 (CAPP)
unnamed: C43.1, U7.18 (LDOO)
unnamed: R16.1, U7.6 (OUTL)
unnamed: R17.1, U7.7 (OUTR)
unnamed: C44.1, U7.5 (VNEG)
unnamed: R18.2, R19.1, U8.10 (-INA)
unnamed: R20.2, R21.1, U8.6 (-INB)
unnamed: C45.1, R22.2, U8.8 (EN)

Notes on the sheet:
Audio jack connector
OPA1622 Headphone driver
PCM5102A DAC
Soft mute L: Mute H: Unmute
Filter latency L: Normal H: Low latency
44.1 de-emphasis L: Off H: On
OPA1652 (op-amp)
PCM5102A Feature Control
Volume slider
PCM5102A can generate SCK based on BCK. But SCK needs to be grounded for better audio.

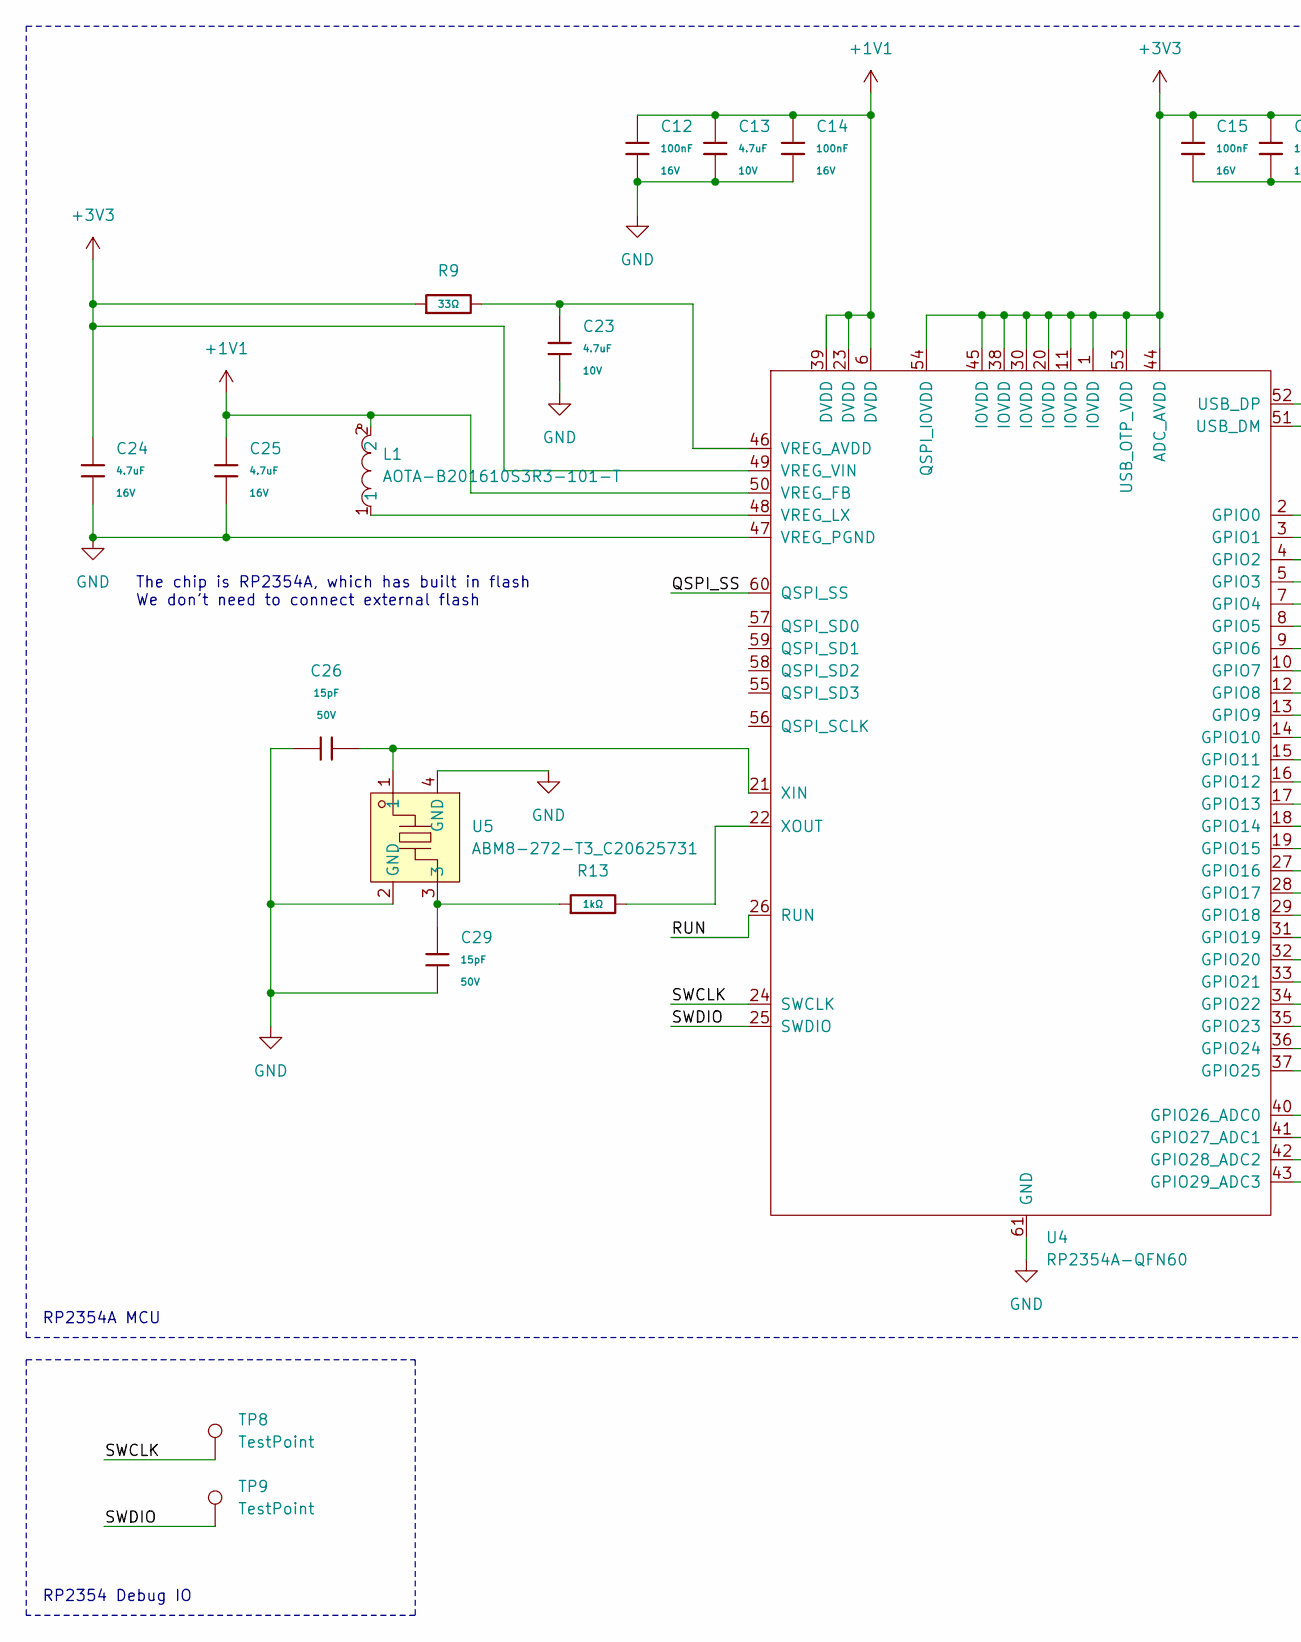
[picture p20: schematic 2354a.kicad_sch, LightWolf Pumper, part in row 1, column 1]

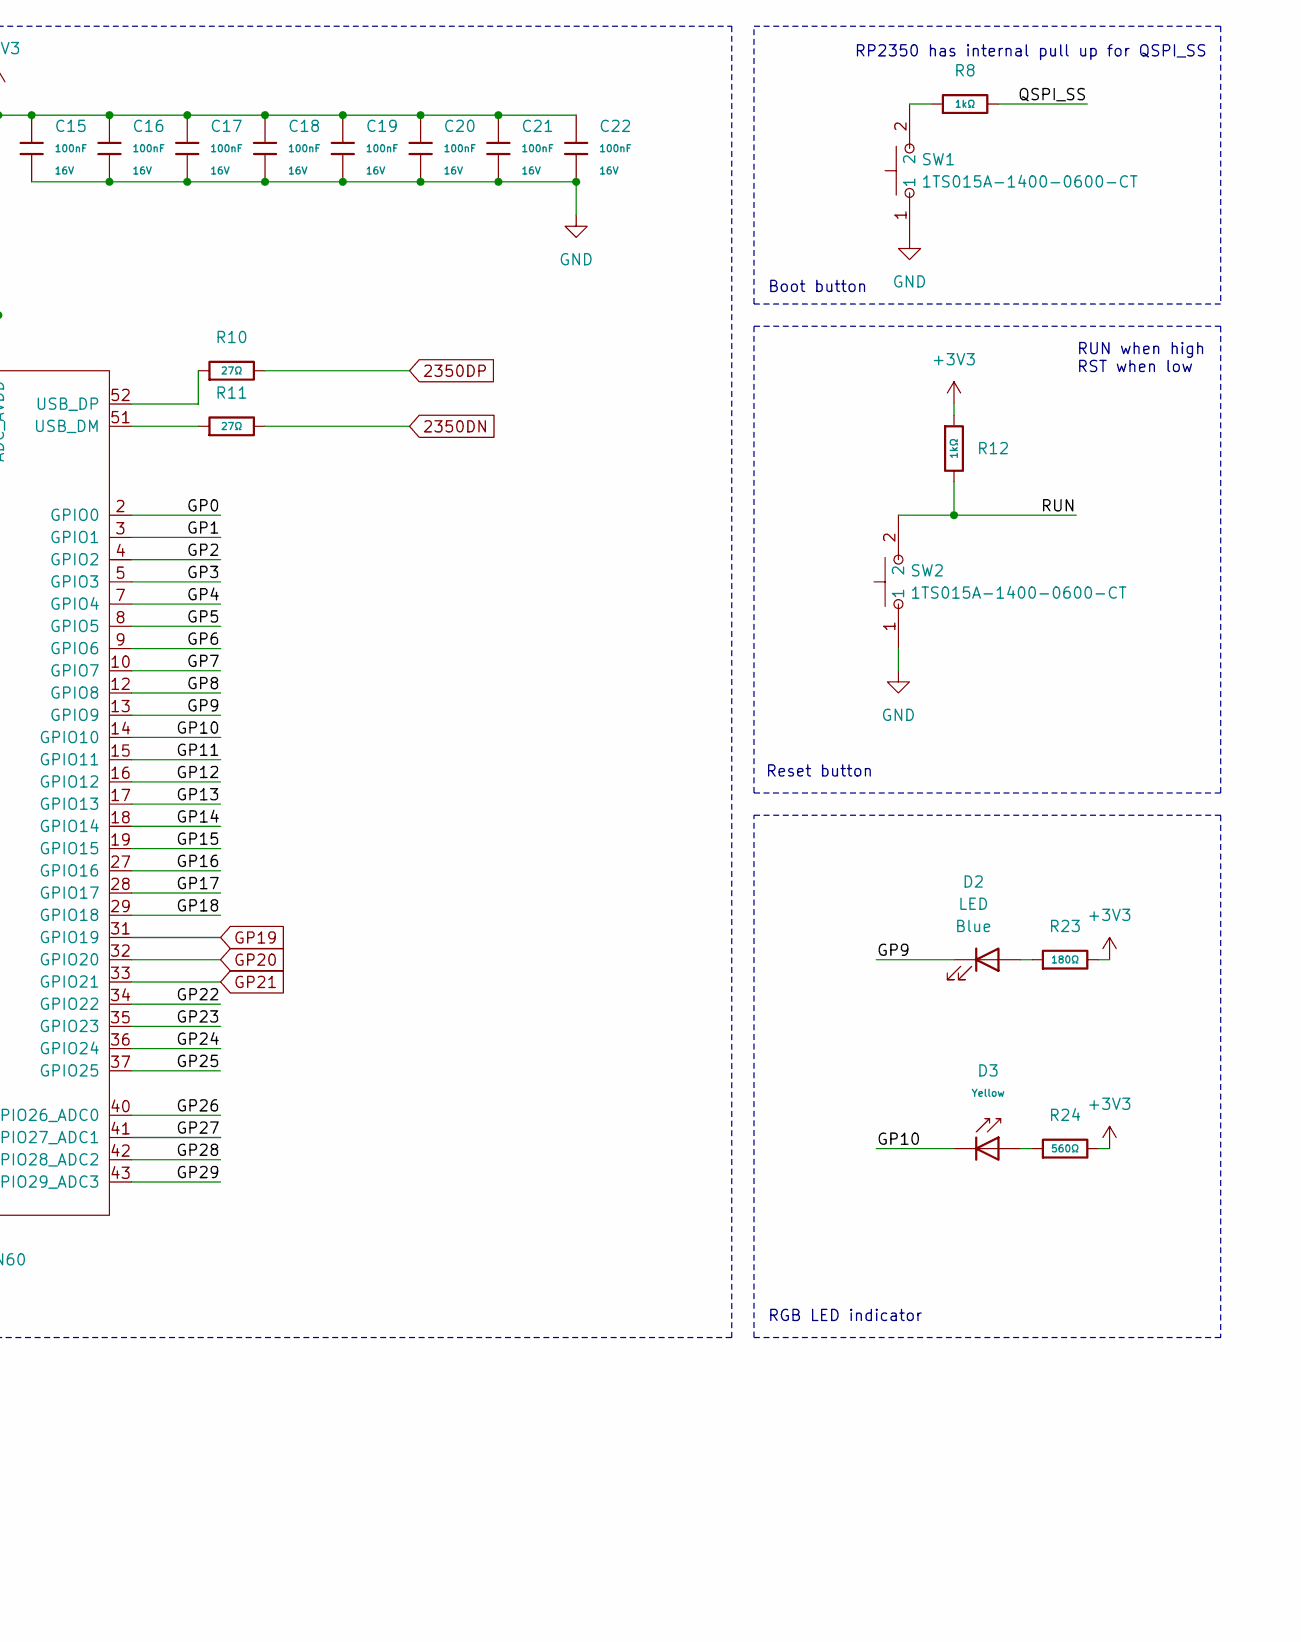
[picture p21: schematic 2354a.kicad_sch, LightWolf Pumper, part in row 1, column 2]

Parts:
C12, C14, C15, C16, C17, C18, C19, C20, C21, C22: 100nF; C_0402; Voltage Rated 16V; Tolerance ±10%; Part CL05B104KO5NNNC; LCSC C1525
C13, C23: 4.7uF; C_0402; Voltage Rated 10V; Tolerance ±20%; Part CL05A475MP5NRNC; LCSC C23733
C24, C25: 4.7uF; C_0603; Voltage Rated 16V; Tolerance ±10%; Part CL10A475KO8NNNC; LCSC C19666
C26, C29: 15pF; C_0402; Voltage Rated 50V; Tolerance ±5%; Part 0402CG150J500NT; LCSC C1548
D2: LED; D_0603; LCSC C2288
D3: Yellow; D_0603; Forward Voltage (VF) 1.6V~2.6V; Part NCD0603Y2; LCSC C89811
L1: AOTA-B201610S3R3-101-T; IND-SMD_L2.0-W1.6_AOTA-B201610S3R3-101-T; LCSC Part C42411119
R8, R12, R13: 1kΩ; R_0402; Overload Voltage (Max) 50V; Tolerance ±1%; Part 0402WGF1001TCE; LCSC C11702
R9: 33Ω; R_0402; Overload Voltage (Max) 50V; Tolerance ±1%; Part 0402WGF330JTCE; LCSC C25105
R10, R11: 27Ω; R_0603; Overload Voltage (Max) 75V; Tolerance ±1%; Part 0603WAF270JT5E; LCSC C25190
R23: 180Ω; R_0603; Overload Voltage (Max) 75V; Tolerance ±1%; Part 0603WAF1800T5E; LCSC C22828
R24: 560Ω; R_0603; Overload Voltage (Max) 75V; Tolerance ±1%; Part 0603WAF5600T5E; LCSC C23204
SW1, SW2: 1TS015A-1400-0600-CT; SW-SMD_L3.0-W2.0-LS3.5; LCSC Part C319433
TP8, TP9: TestPoint; TestPoint_Pad_D1.0mm
U4: RP2354A-QFN60; QFN-60-1EP_7x7mm_P0.4mm_EP3.4x3.4mm_ThermalVias
U5: ABM8-272-T3_C20625731; CRYSTAL-SMD_4P-L3.2-W2.5-BL; LCSC Part C20625731

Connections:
2350DN: R11.2; also elsewhere on the board
2350DP: R10.2; also elsewhere on the board
+1V1: C12.1, C13.1, C14.1, C25.1, L1.2, U4.6 (DVDD), U4.23 (DVDD), U4.39 (DVDD), U4.50 (VREG_FB)
+3V3: C15.1, C16.1, C17.1, C18.1, C19.1, C20.1, C21.1, C22.1, C24.1, R9.1, R12.1, R23.2, R24.2, U4.1 (IOVDD), U4.11 (IOVDD), U4.20 (IOVDD), U4.30 (IOVDD), U4.38 (IOVDD), U4.44 (ADC_AVDD), U4.45 (IOVDD), U4.49 (VREG_VIN), U4.53 (USB_OTP_VDD), U4.54 (QSPI_IOVDD); also elsewhere on the board
/MCU/GP0: U4.2 (GPIO0)
/MCU/GP1: U4.3 (GPIO1)
/MCU/GP2: U4.4 (GPIO2)
/MCU/GP3: U4.5 (GPIO3)
/MCU/GP4: U4.7 (GPIO4)
/MCU/GP5: U4.8 (GPIO5)
/MCU/GP6: U4.9 (GPIO6)
/MCU/GP7: U4.10 (GPIO7)
/MCU/GP8: U4.12 (GPIO8)
/MCU/GP9: D2.1 (K), U4.13 (GPIO9)
/MCU/GP10: D3.1, U4.14 (GPIO10)
/MCU/GP11: U4.15 (GPIO11)
/MCU/GP12: U4.16 (GPIO12)
/MCU/GP13: U4.17 (GPIO13)
/MCU/GP14: U4.18 (GPIO14)
/MCU/GP15: U4.19 (GPIO15)
/MCU/GP16: U4.27 (GPIO16)
/MCU/GP17: U4.28 (GPIO17)
/MCU/GP18: U4.29 (GPIO18)
/MCU/GP22: U4.34 (GPIO22)
/MCU/GP23: U4.35 (GPIO23)
/MCU/GP24: U4.36 (GPIO24)
/MCU/GP25: U4.37 (GPIO25)
/MCU/GP26: U4.40 (GPIO26_ADC0)
/MCU/GP27: U4.41 (GPIO27_ADC1)
/MCU/GP28: U4.42 (GPIO28_ADC2)
/MCU/GP29: U4.43 (GPIO29_ADC3)
/MCU/QSPI_SS: R8.2, U4.60 (QSPI_SS)
/MCU/RUN: R12.2, SW2.2, U4.26 (RUN)
/MCU/SWCLK: TP8.1, U4.24 (SWCLK)
/MCU/SWDIO: TP9.1, U4.25 (SWDIO)
GND: C12.2, C13.2, C14.2, C15.2, C16.2, C17.2, C18.2, C19.2, C20.2, C21.2, C22.2, C23.2, C24.2, C25.2, C26.1, C29.2, SW1.1, SW2.1, U4.47 (VREG_PGND), U4.61 (GND), U5.2 (GND), U5.4 (GND); also elsewhere on the board
GP19: U4.31 (GPIO19); also elsewhere on the board
GP20: U4.32 (GPIO20); also elsewhere on the board
GP21: U4.33 (GPIO21); also elsewhere on the board
unnamed: C29.1, R13.1, U5.3
unnamed: D2.2 (A), R23.1
unnamed: D3.2, R24.1
unnamed: R8.1, SW1.2
unnamed: R11.1, U4.51 (USB_DM)
unnamed: R10.1, U4.52 (USB_DP)
unnamed: C23.1, R9.2, U4.46 (VREG_AVDD)
unnamed: L1.1, U4.48 (VREG_LX)
unnamed: C26.2, U4.21 (XIN), U5.1
unnamed: R13.2, U4.22 (XOUT)

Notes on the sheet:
The chip is RP2354A, which has built in flash We don't need to connect external flash
Reset button
RP2354A MCU
RP2354 Debug IO
RUN when high RST when low
Boot button
RP2350 has internal pull up for QSPI_SS
RGB LED indicator

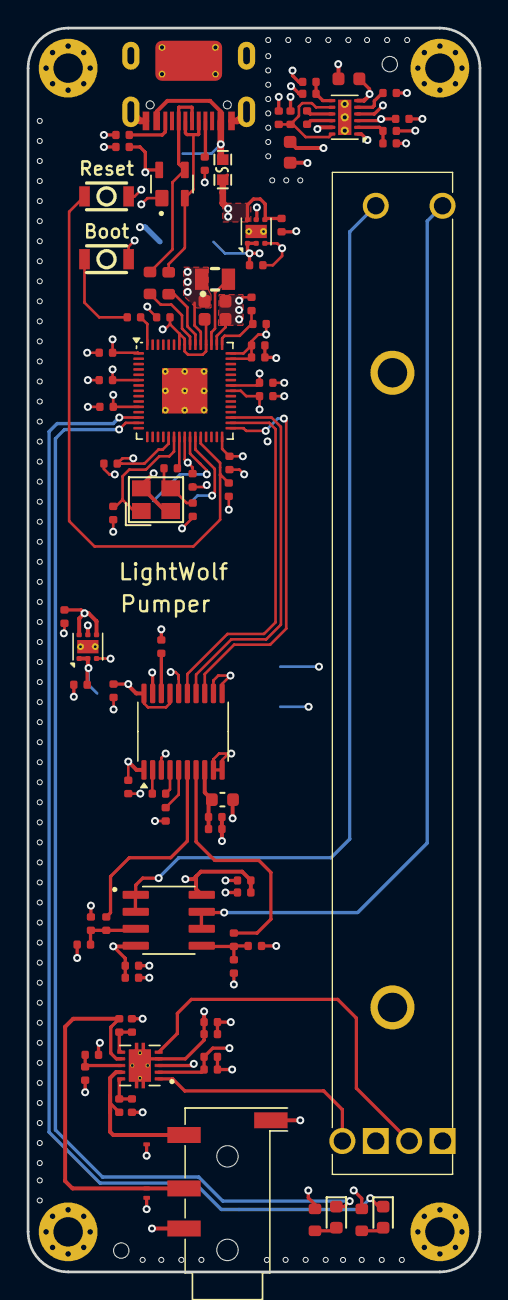
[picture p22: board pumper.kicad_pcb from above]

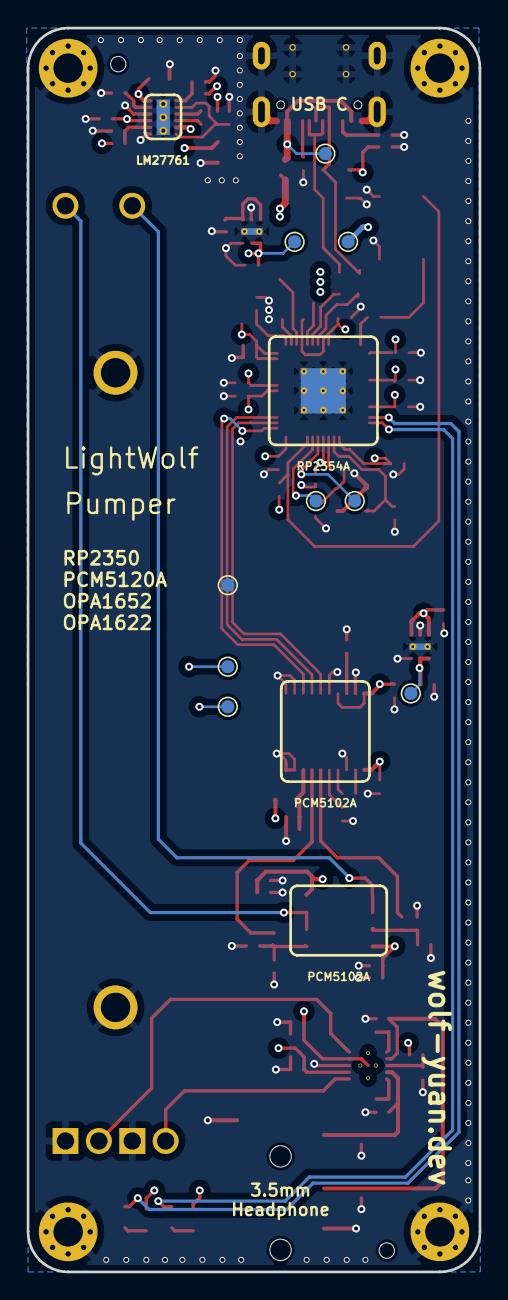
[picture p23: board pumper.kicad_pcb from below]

Board: 4 copper layers, 33.8 x 93.1 mm, 105 parts (9 on the bottom side), 55 nets.

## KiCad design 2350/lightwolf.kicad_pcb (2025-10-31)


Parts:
BOOT1: 1TS015A-1400-0600-CT; SW-SMD_L3.0-W2.0-LS3.5; LCSC Part C319433
C1: 470nF; C_0402; Voltage Rated 10V; Tolerance ±10%; Part CL05A474KP5NNNC; LCSC C47339
C2, C3, C4, C5, C6, C7, C8, C13, C14, C15, C16: 100nF; C_0402; Voltage Rated 16V; Tolerance ±10%; Part CL05B104KO5NNNC; LCSC C1525
C9, C12: 10uF; C_0402; Voltage Rated 6.3V; Tolerance ±20%; Part CL05A106MQ5NUNC; LCSC C15525
C10, C11: 15pF; C_0402; Voltage Rated 50V; Tolerance ±5%; Part 0402CG150J500NT; LCSC C1548
C17, C18: 4.7uF; C_0603; Voltage Rated 16V; Tolerance ±10%; Part CL10A475KO8NNNC; LCSC C19666
C19: 4.7uF; C_0402; Voltage Rated 10V; Tolerance ±20%; Part CL05A475MP5NRNC; LCSC C23733
D1: TPD2E2U06DCKR; SC-70-3_L2.0-W1.3-P0.65-LS2.1-BL; LCSC Part C1855726
D2: White; D_0603; Part KT-0603W; LCSC C2290
D3: Yellow; D_0805; Part KT-0805Y; LCSC C2296
D4, D5: Green; D_0805; Part KT-0805G; LCSC C2297
H1, H2, H3, H4: Hole_Tooling_JLCPCB; not fitted
L1: AOTA-B201610S3R3-101-T; IND-SMD_L2.0-W1.6_AOTA-B201610S3R3-101-T; LCSC Part C42411119
Q1: XC6220B331MR-G; SOT-25_L3.0-W1.6-P0.95-LS2.8-TL; LCSC Part C86534
R1, R8: 1kΩ; R_0402; Overload Voltage (Max) 50V; Tolerance ±1%; Part 0402WGF1001TCE; LCSC C11702
R2, R3: 5.1kΩ; R_0402; Overload Voltage (Max) 50V; Tolerance ±1%; Part 0402WGF5101TCE; LCSC C25905
R4, R10, R11, R12: 470Ω; R_0402; Overload Voltage (Max) 50V; Tolerance ±1%; Part 0402WGF4700TCE; LCSC C25117
R5, R13: 10kΩ; R_0402; Overload Voltage (Max) 50V; Tolerance ±1%; Part 0402WGF1002TCE; LCSC C25744
R6, R7, R9: 33Ω; R_0402; Overload Voltage (Max) 50V; Tolerance ±1%; Part 0402WGF330JTCE; LCSC C25105
RESET1: 1TS015A-1400-0600-CT; SW-SMD_L3.0-W2.0-LS3.5; LCSC Part C319433
U1: ABM8-272-T3_C20625731; CRYSTAL-SMD_4P-L3.2-W2.5-BL; LCSC Part C20625731
U2: 0603L100SLYR; R0603; LCSC Part C207017
U3: W25Q64JVSSIQ_C179171; SOIC-8_L5.3-W5.3-P1.27-LS8.0-BL; LCSC Part C179171
U4: RP2350A_C42411118; QFN-60-1EP_7x7mm_P0.4mm_EP3.4x3.4mm_ThermalVias; LCSC Part C42411118
U5, U6: DS1021-1X20SF11-B; HDR-TH_20P-P2.54-V-M; LCSC Part C7430376
USBC1: TYPE-C-31-M-12; USB-C_SMD-TYPE-C-31-M-12_1; LCSC Part C165948

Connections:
+1V1: C13.1, C14.1, C15.1, C18.1, L1.2, U4.6 (DVDD), U4.23 (DVDD), U4.39 (DVDD), U4.50 (VREG_FB)
+3V3: C1.1, C2.1, C3.1, C4.1, C5.1, C6.1, C7.1, C8.1, C12.1, C16.1, C17.1, Q1.5 (VOUT), R4.1, R5.1, R9.1, R10.2, R11.2, R12.2, R13.2, U3.8 (VCC), U4.1 (IOVDD), U4.11 (IOVDD), U4.20 (IOVDD), U4.30 (IOVDD), U4.38 (IOVDD), U4.44 (ADC_AVDD), U4.45 (IOVDD), U4.49 (VREG_VIN), U4.53 (USB_OTP_VDD), U4.54 (QSPI_IOVDD), U5.14, U6.15, U6.16
+5V: C9.1, Q1.1 (VIN), Q1.3 (CE), U2.2, U5.12, U6.19
/GP0: U4.2 (GPIO0), U5.20
/GP1: U4.3 (GPIO1), U5.19
/GP2: U4.4 (GPIO2), U5.17
/GP3: U4.5 (GPIO3), U5.16
/GP4: U4.7 (GPIO4), U5.15
/GP7: U4.10 (GPIO7), U5.11
/GP8: U4.12 (GPIO8), U5.10
/GP9: U4.13 (GPIO9), U5.9
/GP10: U4.14 (GPIO10), U5.7
/GP11: U4.15 (GPIO11), U5.6
/GP12: U4.16 (GPIO12), U5.5
/GP13: U4.17 (GPIO13), U5.4
/GP14: U4.18 (GPIO14), U5.2
/GP15: U4.19 (GPIO15), U5.1
/GP16: U4.27 (GPIO16), U6.1
/GP17: U4.28 (GPIO17), U6.2
/GP18: U4.29 (GPIO18), U6.4
/GP19: U4.31 (GPIO19), U6.5
/GP20: U4.32 (GPIO20), U6.6
/GP21: U4.33 (GPIO21), U6.7
/GP22: U4.34 (GPIO22), U6.9
/GP26: U4.40 (GPIO26_ADC0), U6.11
/GP27: U4.41 (GPIO27_ADC1), U6.12
/GP28: U4.42 (GPIO28_ADC2), U6.14
/QSPI_CLK: U3.6 (CLK), U4.56 (QSPI_SCLK)
/QSPI_SP0: U3.5 (DI(IO0)), U4.57 (QSPI_SD0)
/QSPI_SP1: U3.2 (DO(IO1)), U4.59 (QSPI_SD1)
/QSPI_SP2: U3.3 (WP#(IO2)), U4.58 (QSPI_SD2)
/QSPI_SP3: U3.7 (HOLD#orRESET#(IO3)), U4.55 (QSPI_SD3)
/QSPI_SS: R5.2, R8.1, U3.1 (~CS), U4.60 (QSPI_SS)
/RUN: R13.1, RESET1.1, U4.26 (RUN), U6.10
/USBDN: D1.1 (IO1), R7.1, USBC1.A7 (DN1), USBC1.B7 (DN2)
/USBDP: D1.2 (IO2), R6.1, USBC1.A6 (DP1), USBC1.B6 (DP2)
/XIN: C10.1, U1.1, U4.21 (XIN)
/XOUT: C11.1, R1.2, U4.22 (XOUT)
GND: BOOT1.2, C1.2, C2.2, C3.2, C4.2, C5.2, C6.2, C7.2, C8.2, C9.2, C10.2, C11.2, C12.2, C13.2, C14.2, C15.2, C16.2, C17.2, C18.2, C19.2, D1.3 (GND), D2.1, Q1.2 (VSS), R2.2, R3.1, RESET1.2, U1.2 (GND), U1.4 (GND), U3.4 (GND), U4.47 (VREG_PGND), U4.61 (GND), U5.3, U5.8, U5.13, U5.18, U6.3, U6.8, U6.13, U6.17, U6.18, USBC1.1 (EH), USBC1.2 (EH), USBC1.3 (EH), USBC1.4 (EH), USBC1.A1B12 (GND), USBC1.B1A12 (GND)
unnamed: BOOT1.1, R8.2
unnamed: D2.2, R4.2
unnamed: D3.2, R10.1
unnamed: D4.2, R11.1
unnamed: D5.2, R12.1
unnamed: R1.1, U1.3
unnamed: D5.1, U4.35 (GPIO23)
unnamed: D4.1, U4.36 (GPIO24)
unnamed: D3.1, U4.37 (GPIO25)
unnamed: R7.2, U4.51 (USB_DM)
unnamed: R6.2, U4.52 (USB_DP)
unnamed: C19.1, R9.2, U4.46 (VREG_AVDD)
unnamed: L1.1, U4.48 (VREG_LX)
unnamed: R3.2, USBC1.A5 (CC1)
unnamed: R2.1, USBC1.B5 (CC2)
USBVBUS: U2.1, U6.20, USBC1.A4B9 (VBUS), USBC1.B4A9 (VBUS)

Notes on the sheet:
QSPI flash
Decoupling capacitor
5V to 3V3 regulator
RP2350
Crystal oscillator
USB and power input
I/O pin


Board: 4 copper layers, 21.0 x 51.0 mm, 52 parts (0 on the bottom side), 55 nets.

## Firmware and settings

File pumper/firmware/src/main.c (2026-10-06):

#include <stdbool.h>
#include <math.h>
#include <stdint.h>
#include <string.h>

#include "bsp/board_api.h"
#include "hardware/adc.h"
#include "hardware/clocks.h"
#include "hardware/pwm.h"
#include "hardware/vreg.h"
#include "hardware/watchdog.h"
#include "pico/bootrom.h"
#include "pico/multicore.h"
#include "pico/stdlib.h"
#include "pico/util/queue.h"
#include "tusb.h"

#include "audio_feedback.h"
#include "audio_format.h"
#include "eq_config.h"
#include "eq_dsp.h"
#include "audio_controls.h"
#include "hid_activity.h"
#include "eq_protocol.h"
#include "eq_settings.h"
#include "i2s_out.h"
#include "quirk_os_guessing.h"
#include "telemetry.h"
#include "spectrum.h"
#include "usb_descriptors.h"

#define AUDIO_CHANNELS 2u
#define AUDIO_BLOCK_COUNT I2S_AUDIO_BLOCK_COUNT
#define METER_REPORT_INTERVAL_MIN_MS 20u
#define METER_REPORT_INTERVAL_MAX_MS 250u
#define METER_TIMEOUT_MIN_MS 250u
#define METER_TIMEOUT_MAX_MS 5000u
#define DEVICE_RESET_ACK_DELAY_US 250000u
#define DEVICE_RESET_FALLBACK_DELAY_US 1000000u
#define TEMPERATURE_SAMPLE_COUNT 8u
#define ADC_REFERENCE_VOLTAGE 3.3f
#define ADC_MAX_COUNTS 4096.0f
#define TEMPERATURE_REFERENCE_C 27.0f
#define TEMPERATURE_REFERENCE_VOLTAGE 0.706f
#define TEMPERATURE_VOLTAGE_SLOPE 0.001721f
#define IDLE_SYS_CLOCK_KHZ 150000u
#define STREAM_SYS_CLOCK_KHZ 180000u

// GPIO pins for the two status LEDs (active-low, driven via PWM).
#define LED_RED_PIN  10u  // Lit when USB audio streaming is active
#define LED_BLUE_PIN  9u  // Brightness tracks the final output peak level

// PWM configuration: 8-bit counter (wrap = 255).
// Maximum brightness is configured separately for each LED.
#define LED_PWM_WRAP             255u
#define LED_RED_MAX_BRIGHTNESS   ((LED_PWM_WRAP * 40u) / 100u)
#define LED_BLUE_MAX_BRIGHTNESS  ((LED_PWM_WRAP * 60u) / 100u)

static uint32_t const sample_rates[] = {44100u, 48000u, 88200u, 96000u, 176400u, 192000u};
#define N_SAMPLE_RATES TU_ARRAY_SIZE(sample_rates)

// Host controls only the stereo master (index 0). Channel slots stay zero
// for compatibility with the existing HID audio-controls response.
static int8_t s_mute[AUDIO_CHANNELS + 1];

// Volume in UAC2 Q8.8 fixed-point dB (0 = 0 dB, -256 = -1 dB).
// Range advertised: -50 dB (–12800) to 0 dB, in 1 dB (256) steps.
static int16_t s_volume_q8[AUDIO_CHANNELS + 1];

static volatile uint32_t s_sample_rate_hz = 48000u;

// Fixed pool passed from core 0 (USB) to core 1 (DSP) without allocating.
typedef i2s_audio_block_t audio_block_t;
static audio_block_t s_audio_blocks[AUDIO_BLOCK_COUNT];
static uint8_t s_usb_packet[CFG_TUD_AUDIO_FUNC_1_EP_OUT_SZ_MAX];
static queue_t s_free_audio_blocks;
static queue_t s_pending_audio_blocks;

static crossfeed_config_t s_crossfeed_live, s_crossfeed_saved;
static output_processing_config_t s_output_live, s_output_saved;
static hid_activity_t s_hid_activity;
static eq_config_t s_saved_config;
static volatile uint32_t s_config_generation = 1u;
static volatile uint32_t s_applied_generation = 0u;
static volatile uint32_t s_saved_generation = 0u;
static volatile uint32_t s_backpressure_events = 0u;
static volatile bool s_streaming_active = false;
static volatile uint32_t s_stream_generation = 0u;
static volatile audio_sample_format_t s_audio_format = AUDIO_FORMAT_PCM16;
static volatile bool s_dsp_core_ready = false;
static volatile uint32_t s_dsp_max_block_us = 0u;
static uint8_t s_active_profile = 0u;
static uint8_t s_persisted_profile = 0u;

typedef struct {
  eq_level_metrics_t pre_eq;
  eq_level_metrics_t post_eq;
  uint32_t frame_count;
  bool limiter_active;
} meter_accumulator_t;

typedef struct {
  volatile uint32_t sequence;
  eq_config_t config;
  uint32_t generation;
} config_snapshot_t;

typedef struct {
  volatile uint32_t sequence;
  crossfeed_config_t crossfeed;
  output_processing_config_t output;
  float gains[2];
  uint32_t generation;
} controls_snapshot_t;

static config_snapshot_t s_config_snapshots[2];
static controls_snapshot_t s_controls_snapshots[2];
static volatile uint32_t s_config_snapshot_index;
static volatile uint32_t s_controls_snapshot_index;
static volatile uint32_t s_audio_controls_generation = 1u;
static meter_accumulator_t s_meter_accumulators[2];
static volatile uint32_t s_meter_accumulator_index;
static volatile uint32_t s_meter_writers[2];
static bool s_meter_configured = false;
static volatile bool s_meter_active = false;
static uint16_t s_meter_report_interval_ms = 40u;
static uint16_t s_meter_timeout_ms = 1250u;
static uint64_t s_meter_deadline_us = 0u;
static uint64_t s_meter_next_report_us = 0u;
static uint32_t s_meter_sequence = 0u;
static spectrum_frame_t s_spectrum_sending, s_spectrum_waiting;
static bool s_spectrum_sending_valid, s_spectrum_waiting_valid;
static uint8_t s_spectrum_chunk;
static void reset_spectrum_stream(void) {
  spectrum_reset();
  s_spectrum_sending_valid = s_spectrum_waiting_valid = false;
}
static void stop_spectrum_stream(void) {
  spectrum_stop();
  s_spectrum_sending_valid = s_spectrum_waiting_valid = false;
}
static audio_feedback_controller_t s_feedback_controller;
static bool s_feedback_initialized = false;
static uint64_t s_feedback_next_update_us = 0u;

static uint8_t s_hid_response[EQ_PROTOCOL_REPORT_SIZE];
static bool s_hid_response_pending = false;
typedef enum {
  DEVICE_RESET_NONE,
  DEVICE_RESET_RESTART,
  DEVICE_RESET_BOOTSEL,
} device_reset_action_t;
static device_reset_action_t s_device_reset_action = DEVICE_RESET_NONE;
static bool s_device_reset_response_in_flight = false;
static uint64_t s_device_reset_deadline_us = 0u;
typedef enum {
  FLASH_ACTION_SAVE_PROFILE,
  FLASH_ACTION_SET_DEFAULT_PROFILE,
  FLASH_ACTION_DELETE_PROFILE,
  FLASH_ACTION_SAVE_CROSSFEED,
  FLASH_ACTION_SAVE_OUTPUT_PROCESSING,
} flash_action_t;
static bool s_flash_write_pending = false;
static flash_action_t s_flash_action = FLASH_ACTION_SAVE_PROFILE;
static uint8_t s_flash_request_opcode = 0u;
static uint16_t s_flash_request_id = 0u;
static uint8_t s_flash_profile_index = 0u;

static void led_pwm_init(uint pin) {
  gpio_set_function(pin, GPIO_FUNC_PWM);
  uint slice = pwm_gpio_to_slice_num(pin);
  uint channel = pwm_gpio_to_channel(pin);

  pwm_config cfg = pwm_get_default_config();
  pwm_config_set_wrap(&cfg, LED_PWM_WRAP);
  pwm_init(slice, &cfg, false);

  // Board LEDs are active-low: invert PWM so level 0 = fully off (pin high).
  bool invert_a = (channel == PWM_CHAN_A);
  bool invert_b = (channel == PWM_CHAN_B);
  pwm_set_output_polarity(slice, invert_a, invert_b);
  pwm_set_chan_level(slice, channel, 0);
  pwm_set_enabled(slice, true);
}

static void red_led_set(bool on) {
  uint slice = pwm_gpio_to_slice_num(LED_RED_PIN);
  uint channel = pwm_gpio_to_channel(LED_RED_PIN);
  pwm_set_chan_level(slice, channel, on ? LED_RED_MAX_BRIGHTNESS : 0);
}

static void led_set_level(uint pin, uint16_t level) {
  uint slice = pwm_gpio_to_slice_num(pin);
  uint channel = pwm_gpio_to_channel(pin);
  if (level > LED_PWM_WRAP) level = LED_PWM_WRAP;
  pwm_set_chan_level(slice, channel, level);
}

static void set_performance_clock(bool streaming) {
  if (streaming) {
    vreg_set_voltage(VREG_VOLTAGE_1_15);
    sleep_us(1000u);
    set_sys_clock_khz(STREAM_SYS_CLOCK_KHZ, true);
  } else {
    set_sys_clock_khz(IDLE_SYS_CLOCK_KHZ, true);
    vreg_set_voltage(VREG_VOLTAGE_1_10);
  }
  i2s_out_set_format(s_sample_rate_hz, s_audio_format);
}

static void set_streaming_state(bool streaming) {
  if (streaming == s_streaming_active) return;
  if (streaming) set_performance_clock(true);

  s_stream_generation++;
  reset_spectrum_stream();
  if (streaming)
    telemetry_stream_started(time_us_64(), s_stream_generation);
  else
    telemetry_stream_stopped(time_us_64());
  s_streaming_active = streaming;
  s_feedback_initialized = false;
  s_feedback_next_update_us = 0u;
  s_dsp_max_block_us = 0u;
  i2s_out_set_streaming(streaming);
  if (!streaming) {
    audio_block_t *block;
    while (queue_try_remove(&s_pending_audio_blocks, &block))
      queue_add_blocking(&s_free_audio_blocks, &block);
    led_set_level(LED_BLUE_PIN, 0u);
    set_performance_clock(false);
  }
}

static int32_t chip_temperature_millicelsius(void) {
  uint32_t sample_total = 0u;
  for (uint32_t i = 0; i < TEMPERATURE_SAMPLE_COUNT; i++) sample_total += adc_read();
  float average_sample = (float)sample_total / (float)TEMPERATURE_SAMPLE_COUNT;
  float voltage = average_sample * (ADC_REFERENCE_VOLTAGE / ADC_MAX_COUNTS);
  float celsius = TEMPERATURE_REFERENCE_C -
                  (voltage - TEMPERATURE_REFERENCE_VOLTAGE) / TEMPERATURE_VOLTAGE_SLOPE;
  return (int32_t)lrintf(celsius * 1000.0f);
}

// Respond to an unhandled control request with a zero-filled buffer.
// Used as a safe fallback for GET requests on unknown entities.
static bool send_zero_control(uint8_t rhport, tusb_control_request_t const *p_request) {
  static uint8_t const zero_buf[64] = {0};
  uint16_t len = tu_le16toh(p_request->wLength);
  if (len > sizeof(zero_buf)) len = sizeof(zero_buf);
  return tud_control_xfer(rhport, p_request, (void *) zero_buf, len);
}

static bool handle_sample_rate_change(uint32_t new_rate_hz) {
  if (!audio_format_rate_change_valid(s_audio_format, new_rate_hz, s_streaming_active)) return false;
  bool resume = s_streaming_active;
  if (resume) set_streaming_state(false);
  if (resume) tud_audio_clear_ep_out_ff();
  s_sample_rate_hz = new_rate_hz;
  reset_spectrum_stream();
  s_feedback_initialized = false;
  // An idle clock request can precede selection of the next PCM alternate.
  // Defer I2S reconfiguration if the cached previous format cannot use it;
  // set_itf validates and configures the new format before starting playback.
  if (audio_format_rate_valid(s_audio_format, new_rate_hz))
    i2s_out_set_format(s_sample_rate_hz, s_audio_format);
  if (resume) set_streaming_state(true);
  return true;
}

static eq_config_t config_snapshot(uint32_t *generation) {
  for (;;) {
    uint32_t index = __atomic_load_n(&s_config_snapshot_index, __ATOMIC_ACQUIRE);
    config_snapshot_t const *snapshot = &s_config_snapshots[index];
    uint32_t before = __atomic_load_n(&snapshot->sequence, __ATOMIC_ACQUIRE);
    if (before & 1u) continue;
    eq_config_t config = snapshot->config;
    uint32_t value = snapshot->generation;
    __atomic_thread_fence(__ATOMIC_ACQUIRE);
    if (before == __atomic_load_n(&snapshot->sequence, __ATOMIC_RELAXED) &&
        index == __atomic_load_n(&s_config_snapshot_index, __ATOMIC_RELAXED)) {
      if (generation) *generation = value;
      return config;
    }
  }
}

static void publish_config(eq_config_t const *config) {
  uint32_t index = __atomic_load_n(&s_config_snapshot_index, __ATOMIC_RELAXED) ^ 1u;
  config_snapshot_t *snapshot = &s_config_snapshots[index];
  __atomic_add_fetch(&snapshot->sequence, 1u, __ATOMIC_RELAXED);
  snapshot->config = *config;
  snapshot->generation = ++s_config_generation;
  __atomic_add_fetch(&snapshot->sequence, 1u, __ATOMIC_RELEASE);
  __atomic_store_n(&s_config_snapshot_index, index, __ATOMIC_RELEASE);
}

static controls_snapshot_t controls_snapshot(void) {
  for (;;) {
    uint32_t index = __atomic_load_n(&s_controls_snapshot_index, __ATOMIC_ACQUIRE);
    controls_snapshot_t const *snapshot = &s_controls_snapshots[index];
    uint32_t before = __atomic_load_n(&snapshot->sequence, __ATOMIC_ACQUIRE);
    if (before & 1u) continue;
    controls_snapshot_t copy = *snapshot;
    __atomic_thread_fence(__ATOMIC_ACQUIRE);
    if (before == __atomic_load_n(&snapshot->sequence, __ATOMIC_RELAXED) &&
        index == __atomic_load_n(&s_controls_snapshot_index, __ATOMIC_RELAXED)) return copy;
  }
}

static void publish_audio_controls(void) {
  uint32_t index = __atomic_load_n(&s_controls_snapshot_index, __ATOMIC_RELAXED) ^ 1u;
  controls_snapshot_t *snapshot = &s_controls_snapshots[index];
  __atomic_add_fetch(&snapshot->sequence, 1u, __ATOMIC_RELAXED);
  snapshot->crossfeed = s_crossfeed_live;
  snapshot->output = s_output_live;
  audio_effective_gains(s_volume_q8, s_mute, snapshot->gains);
  snapshot->generation = ++s_audio_controls_generation;
  __atomic_add_fetch(&snapshot->sequence, 1u, __ATOMIC_RELEASE);
  __atomic_store_n(&s_controls_snapshot_index, index, __ATOMIC_RELEASE);
}
static void apply_audio_controls(uint32_t *generation) {
  controls_snapshot_t snapshot = controls_snapshot();
  *generation = snapshot.generation;
  audio_controls_set_crossfeed(&snapshot.crossfeed);
  audio_controls_set_output_processing(&snapshot.output);
  audio_controls_set_gains(snapshot.gains);
}

static bool config_is_dirty(void) {
  eq_config_t config = config_snapshot(NULL);
  return !eq_config_equal(&config, &s_saved_config);
}

static void meter_reset(void) {
  uint32_t old = __atomic_load_n(&s_meter_accumulator_index, __ATOMIC_RELAXED);
  uint32_t next = old ^ 1u;
  memset(&s_meter_accumulators[next], 0, sizeof(s_meter_accumulators[next]));
  __atomic_store_n(&s_meter_accumulator_index, next, __ATOMIC_RELEASE);
  while (__atomic_load_n(&s_meter_writers[old], __ATOMIC_ACQUIRE)) tight_loop_contents();
  memset(&s_meter_accumulators[old], 0, sizeof(s_meter_accumulators[old]));
}

static void meter_merge_level(eq_level_metrics_t *accumulator,
                              eq_level_metrics_t const *block) {
  if (block->left_peak > accumulator->left_peak) accumulator->left_peak = block->left_peak;
  if (block->right_peak > accumulator->right_peak) accumulator->right_peak = block->right_peak;
  accumulator->left_square_sum += block->left_square_sum;
  accumulator->right_square_sum += block->right_square_sum;
}

static void meter_accumulate(eq_level_metrics_t const *pre_eq,
                             eq_level_metrics_t const *post_eq, uint16_t frames,
                             bool limiter_active) {
  if (!s_meter_active) return;
  for (;;) {
    uint32_t index = __atomic_load_n(&s_meter_accumulator_index, __ATOMIC_ACQUIRE);
    __atomic_add_fetch(&s_meter_writers[index], 1u, __ATOMIC_ACQUIRE);
    if (index == __atomic_load_n(&s_meter_accumulator_index, __ATOMIC_RELAXED)) {
      meter_merge_level(&s_meter_accumulators[index].pre_eq, pre_eq);
      meter_merge_level(&s_meter_accumulators[index].post_eq, post_eq);
      s_meter_accumulators[index].frame_count += frames;
      s_meter_accumulators[index].limiter_active |= limiter_active;
      __atomic_sub_fetch(&s_meter_writers[index], 1u, __ATOMIC_RELEASE);
      return;
    }
    __atomic_sub_fetch(&s_meter_writers[index], 1u, __ATOMIC_RELEASE);
  }
}

static meter_accumulator_t meter_take(void) {
  uint32_t old = __atomic_load_n(&s_meter_accumulator_index, __ATOMIC_RELAXED);
  uint32_t next = old ^ 1u;
  memset(&s_meter_accumulators[next], 0, sizeof(s_meter_accumulators[next]));
  __atomic_store_n(&s_meter_accumulator_index, next, __ATOMIC_RELEASE);
  while (__atomic_load_n(&s_meter_writers[old], __ATOMIC_ACQUIRE)) tight_loop_contents();
  meter_accumulator_t result = s_meter_accumulators[old];
  memset(&s_meter_accumulators[old], 0, sizeof(s_meter_accumulators[old]));
  return result;
}

static void meter_keepalive(void) {
  uint64_t now = time_us_64();
  s_meter_active = true;
  s_meter_deadline_us = now + (uint64_t)s_meter_timeout_ms * 1000u;
  if (s_meter_next_report_us == 0u) s_meter_next_report_us = now;
}

static void dsp_core_main(void) {
  eq_settings_core_init();
  uint32_t local_generation;
  eq_config_t local_config = config_snapshot(&local_generation);
  controls_snapshot_t initial_controls = controls_snapshot();
  uint32_t local_sample_rate = s_sample_rate_hz;
  eq_init(local_sample_rate, &local_config);
  audio_controls_init(local_sample_rate, &initial_controls.crossfeed, &initial_controls.output);
  uint32_t local_controls_generation = 0u;
  uint32_t local_stream_generation = s_stream_generation;
  apply_audio_controls(&local_controls_generation);
  s_applied_generation = local_generation;
  s_dsp_core_ready = true;

  while (true) {
    audio_block_t *block;
    queue_remove_blocking(&s_pending_audio_blocks, &block);

    if (local_sample_rate != s_sample_rate_hz) {
      local_sample_rate = s_sample_rate_hz;
      eq_set_sample_rate(local_sample_rate);
      audio_controls_reset(local_sample_rate);
    }
    if (s_audio_controls_generation != local_controls_generation)
      apply_audio_controls(&local_controls_generation);
    if (local_stream_generation != block->stream_generation) {
      local_stream_generation = block->stream_generation;
      eq_reset_state();
      audio_controls_reset(local_sample_rate);
    }
    if (s_config_generation != local_generation) {
      uint32_t desired_generation;
      eq_config_t desired = config_snapshot(&desired_generation);
      if (eq_set_config(&desired)) {
        local_generation = desired_generation;
        s_applied_generation = desired_generation;
      }
    }

    if (s_streaming_active && block->stream_generation == s_stream_generation) {
      bool const measure_block = s_meter_active;
      eq_block_metrics_t metrics;
      bool const capture = spectrum_capture_begin(local_sample_rate, block->stream_generation);
      eq_set_output_observer(capture ? spectrum_capture_pair : NULL);
      uint32_t started_us = time_us_32();
      eq_process_interleaved_stereo(block->data.samples, block->frames, &metrics, measure_block);
      uint32_t elapsed_us = time_us_32() - started_us;
      spectrum_capture_end(elapsed_us);
      if (elapsed_us > s_dsp_max_block_us) s_dsp_max_block_us = elapsed_us;
      telemetry_record_audio_block(block->stream_generation, block->frames, elapsed_us,
                                   metrics.limiter_active_frames);

      // Reuse the saturated output metrics collected for HID; no second sample scan.
      uint32_t peak = metrics.post_eq.left_peak;
      if (metrics.post_eq.right_peak > peak) peak = metrics.post_eq.right_peak;
      led_set_level(LED_BLUE_PIN, (uint16_t)((peak * LED_BLUE_MAX_BRIGHTNESS) / 32768u));
      if (measure_block) {
        meter_accumulate(&metrics.pre_eq, &metrics.post_eq, block->frames,
                         metrics.limiter_active_frames != 0u);
      }

      block->word_count = (uint16_t)audio_format_pack_i2s(
          block->data.words, block->data.samples, block->frames, block->format);
      if (i2s_out_submit(block)) block = NULL;
    }
    if (block) queue_add_blocking(&s_free_audio_blocks, &block);
  }
}
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
int main(void) {
  board_init();
  telemetry_init(time_us_64());

  adc_init();
  adc_set_temp_sensor_enabled(true);
  adc_select_input(ADC_TEMPERATURE_CHANNEL_NUM);

  queue_init(&s_free_audio_blocks, sizeof(audio_block_t *), AUDIO_BLOCK_COUNT);
  queue_init(&s_pending_audio_blocks, sizeof(audio_block_t *), AUDIO_BLOCK_COUNT);
  for (uint32_t i = 0; i < AUDIO_BLOCK_COUNT; i++) {
    audio_block_t *block = &s_audio_blocks[i];
    queue_add_blocking(&s_free_audio_blocks, &block);
  }

  eq_settings_core_init();
  uint32_t loaded_generation = 1u;
  eq_config_t initial_config;
  if (!eq_settings_load(&initial_config, &loaded_generation)) {
    eq_config_set_defaults(&initial_config);
    loaded_generation = 1u;
  }
  eq_settings_get_crossfeed(&s_crossfeed_live);
  s_crossfeed_saved = s_crossfeed_live;
  eq_settings_get_output_processing(&s_output_live);
  s_output_saved = s_output_live;
  s_saved_config = initial_config;
  s_config_generation = loaded_generation;
  s_saved_generation = loaded_generation;
  eq_profile_state_t profile_state;
  eq_settings_get_profile_state(&profile_state);
  s_active_profile = profile_state.default_profile;
  s_persisted_profile = profile_state.default_profile;

  for (uint32_t i = 0; i < 2u; ++i) {
    s_config_snapshots[i].config = initial_config;
    s_config_snapshots[i].generation = loaded_generation;
    s_controls_snapshots[i].crossfeed = s_crossfeed_live;
    s_controls_snapshots[i].output = s_output_live;
    s_controls_snapshots[i].gains[0] = 1.0f;
    s_controls_snapshots[i].gains[1] = 1.0f;
    s_controls_snapshots[i].generation = s_audio_controls_generation;
  }

  multicore_launch_core1(dsp_core_main);
  while (!s_dsp_core_ready) tight_loop_contents();

  led_pwm_init(LED_RED_PIN);
  led_pwm_init(LED_BLUE_PIN);
  red_led_set(false);
  led_set_level(LED_BLUE_PIN, 0u);

  i2s_out_init(s_sample_rate_hz, s_audio_format, audio_block_release);

  tud_init(BOARD_TUD_RHPORT);
  board_init_after_tusb();

  memset(s_mute, 0, sizeof(s_mute));
  memset(s_volume_q8, 0, sizeof(s_volume_q8));

  while (true) {
    tud_task();
    device_reset_task();
    hid_control_task();
    meter_stream_task();
    red_led_set(hid_activity_level(&s_hid_activity, time_us_32(), s_streaming_active));
    audio_task();
    audio_feedback_task();
    spectrum_stream_task();
  }
}

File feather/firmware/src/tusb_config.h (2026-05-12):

// TinyUSB configuration for the Feather USB DAC.
//
// This header is included by TinyUSB internals to configure stack behaviour.
// Only USB Device (TUD) mode is enabled; all class drivers except Audio are
// disabled to minimise code size.

#ifndef TUSB_CONFIG_H_
#define TUSB_CONFIG_H_

#ifdef __cplusplus
extern "C" {
#endif

// --- Hardware / BSP overrides (normally supplied by the board support package) ---

#ifndef BOARD_TUD_RHPORT
#define BOARD_TUD_RHPORT 0  // RP2350 has a single USB port on root hub port 0
#endif

#ifndef BOARD_TUD_MAX_SPEED
#define BOARD_TUD_MAX_SPEED OPT_MODE_FULL_SPEED  // USB Full Speed (12 Mbit/s)
#endif

#ifndef CFG_TUSB_MCU
#error CFG_TUSB_MCU must be defined  // Set by the CMake target via target_compile_definitions
#endif

#ifndef CFG_TUSB_OS
#define CFG_TUSB_OS OPT_OS_NONE  // Bare-metal (no RTOS)
#endif

#ifndef CFG_TUSB_DEBUG
#define CFG_TUSB_DEBUG 0  // Set to 2 for verbose TinyUSB debug output over UART
#endif

// --- TinyUSB device stack settings ---

#define CFG_TUD_ENABLED   1
#define CFG_TUD_MAX_SPEED BOARD_TUD_MAX_SPEED

#ifndef CFG_TUSB_MEM_SECTION
#define CFG_TUSB_MEM_SECTION
#endif

#ifndef CFG_TUSB_MEM_ALIGN
#define CFG_TUSB_MEM_ALIGN __attribute__((aligned(4)))
#endif

// Try to auto-detect the host OS so TinyUSB can apply OS-specific workarounds.
#define CFG_QUIRK_OS_GUESSING 1

#ifndef CFG_TUD_ENDPOINT0_SIZE
#define CFG_TUD_ENDPOINT0_SIZE 64  // Control endpoint max packet size (bytes)
#endif

// --- Enabled USB class drivers (all others disabled to save flash/RAM) ---

#define CFG_TUD_AUDIO  1  // USB Audio Class 2
#define CFG_TUD_CDC    0
#define CFG_TUD_MSC    0
#define CFG_TUD_HID    0
#define CFG_TUD_MIDI   0
#define CFG_TUD_VENDOR 0

// --- UAC2 Audio Function 1 parameters ---

#define CFG_TUD_AUDIO_FUNC_1_N_CHANNELS_RX       2       // Stereo (left + right)
#define CFG_TUD_AUDIO_FUNC_1_N_BYTES_PER_SAMPLE_RX 2     // 16-bit samples = 2 bytes
#define CFG_TUD_AUDIO_FUNC_1_RESOLUTION_RX       16      // 16 bits used per sample
#define CFG_TUD_AUDIO_FUNC_1_MAX_SAMPLE_RATE     192000  // Highest advertised sample rate (Hz)
#define CFG_TUD_AUDIO_FUNC_1_DESC_LEN            143     // Byte length of the audio function descriptor
#define CFG_TUD_AUDIO_FUNC_1_N_AS_INT            1       // Number of Audio Streaming interfaces
#define CFG_TUD_AUDIO_FUNC_1_CTRL_BUF_SZ        64      // Buffer for audio control requests (bytes)

// Maximum OUT endpoint packet size for 192 kHz / 16-bit stereo:
//   ceil(192000 / 1000) + 1 extra packet = 193 frames × 2 ch × 2 bytes = 772 bytes.
//   Rounded up to 776 for alignment.
#define CFG_TUD_AUDIO_FUNC_1_EP_OUT_SZ_MAX      776

// Software receive buffer: holds ~5 ms of audio at 192 kHz (enough to absorb
// USB scheduling jitter before the data is forwarded to the I2S ring buffer).
#define CFG_TUD_AUDIO_FUNC_1_EP_OUT_SW_BUF_SZ   8192

// --- Feedback endpoint settings ---

#define CFG_TUD_AUDIO_ENABLE_EP_OUT                    1  // Enable audio OUT (host → device)
#define CFG_TUD_AUDIO_ENABLE_FEEDBACK_EP               1  // Enable SOF feedback for async rate adaptation
#define CFG_TUD_AUDIO_ENABLE_FEEDBACK_FORMAT_CORRECTION 0  // No correction needed at Full Speed

#ifdef __cplusplus
}
#endif

#endif

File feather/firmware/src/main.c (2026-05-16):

// Feather USB DAC — main application entry point.
//
// This firmware implements a USB Audio Class 2 (UAC2) device on the RP2350.
// The host (PC, phone, …) streams 16-bit stereo PCM audio over USB; the
// firmware forwards it to a connected I2S DAC chip via the PIO-based I2S
// driver (i2s_out.c/audio_i2s.pio).
//
// Features:
//   • Supports 44.1 / 48 / 96 / 192 kHz sample rates (host-selectable)
//   • Per-channel mute and volume control via UAC2 Feature Unit
//   • Link LED indicates active USB audio streaming
//   • Loudness indicator shows audio level (peak VU meter, ~33% max brightness)
//   • -3 dB software attenuation applied before I2S output

#include <stdbool.h>
#include <stdint.h>
#include <string.h>

#include "bsp/board_api.h"
#include "hardware/flash.h"
#include "hardware/pwm.h"
#include "hardware/regs/addressmap.h"
#include "hardware/sync.h"
#include "pico/stdlib.h"
#include "tusb.h"

#include "i2s_out.h"
#include "usb_descriptors.h"

#define AUDIO_CHANNELS   2u   // Stereo: left + right
#define AUDIO_FRAME_BYTES 4u  // 2 bytes/sample × 2 channels = 4 bytes per stereo frame

// GPIO pins for the two status LEDs (active-low, driven via PWM).
#define LINK_LED_PIN            15u  // Lit when USB audio streaming is active
#define LOUDNESS_INDICATOR_PIN  14u  // Brightness tracks the audio peak level

// Volume buttons (active-low with pull-ups).
#define VOLUME_UP_BUTTON_PIN    0u
#define VOLUME_DOWN_BUTTON_PIN  1u

// Jack detection and indicator GPIOs.
// GP10/GP11 are active-low jack detect inputs with pull-ups.
// GP8/GP9 default low and are pulled high when the corresponding jack is present.
// GP13 is the 3.5mm jack indicator and GP12 is the 4.4mm jack indicator.
// Both indicators are active-low (low = sink = LED on), default high.
#define JACK_DETECT_1_PIN 10u
#define JACK_DETECT_2_PIN 11u
#define JACK_CTRL_1_PIN    8u
#define JACK_CTRL_2_PIN    9u
#define JACK_35MM_INDICATOR_PIN 13u
#define JACK_44MM_INDICATOR_PIN 12u

// PWM configuration: 8-bit counter (wrap = 255).
// ON_LEVEL is 10% of full scale so the LED is visible but not blinding.
#define LED_PWM_WRAP      255u
#define LED_PWM_ON_LEVEL  ((LED_PWM_WRAP * 10u) / 100u)
#define LINK_LED_FLASH_ON_MS  90u
#define LINK_LED_FLASH_OFF_MS 90u

#define VOLUME_MIN_PERCENT 0u
#define VOLUME_MAX_PERCENT 100u
#define VOLUME_STEP_PERCENT 10u
#define VOLUME_BUTTON_DEBOUNCE_MS 30u
#define VOLUME_SAVE_DELAY_MS 3000u

#define SETTINGS_FLASH_OFFSET (PICO_FLASH_SIZE_BYTES - FLASH_SECTOR_SIZE)
#define SETTINGS_MAGIC 0x4C575646u // "LWVF"
#define SETTINGS_VERSION 1u

// Sample rates advertised to the host via the Clock Source range descriptor.
// The host picks one and sets it via tud_audio_set_req_entity_cb().
static uint32_t const sample_rates[] = {44100u, 48000u, 96000u, 192000u};
#define N_SAMPLE_RATES TU_ARRAY_SIZE(sample_rates)

// Mute state for master (index 0) and each channel (indices 1 and 2).
// Updated by the host through UAC2 Feature Unit set requests.
static int8_t s_mute[AUDIO_CHANNELS + 1];

// Volume in UAC2 Q8.8 fixed-point dB (0 = 0 dB, -256 = -1 dB).
// Range advertised: -50 dB (–12800) to 0 dB, in 1 dB (256) steps.
static int16_t s_volume_q8[AUDIO_CHANNELS + 1];

// Currently active sample rate; updated when the host sends a SET_CUR request
// to the Clock Source entity.
static uint32_t s_sample_rate_hz = 48000u;

// Byte count of the most recent USB isochronous packet, set in the pre-read
// callback and consumed by audio_task().  Marked volatile because it is written
// from a TinyUSB callback (interrupt context) and read from the main loop.
static volatile uint16_t s_rx_size = 0;

static uint8_t s_output_volume_percent = VOLUME_MAX_PERCENT;
static uint8_t s_saved_volume_percent = VOLUME_MAX_PERCENT;
static bool s_volume_dirty = false;
static uint32_t s_volume_save_deadline_ms = 0;

static bool s_link_led_streaming = false;
static bool s_link_led_flash_active = false;
static bool s_link_led_flash_state = false;
static uint8_t s_link_led_flash_toggles_left = 0;
static uint32_t s_link_led_flash_next_ms = 0;

typedef struct {
  bool stable_pressed;
  bool last_raw_pressed;
  uint32_t last_raw_change_ms;
} button_state_t;

static button_state_t s_vol_up_btn = {0};
static button_state_t s_vol_down_btn = {0};

typedef struct __attribute__((packed)) {
  uint32_t magic;
  uint8_t version;
  uint8_t volume_percent;
  uint8_t reserved0;
  uint8_t reserved1;
  uint32_t checksum;
} persisted_settings_t;

static void led_set(uint pin, bool on);

static uint32_t settings_checksum(uint8_t volume_percent) {
  return SETTINGS_MAGIC ^ ((uint32_t) SETTINGS_VERSION << 24u) ^ ((uint32_t) volume_percent << 8u) ^ 0xA55AA55Au;
}

static void led_set_link(bool on) {
  led_set(LINK_LED_PIN, on);
}

static void link_led_apply_current_state(void) {
  if (s_link_led_flash_active) {
    led_set_link(s_link_led_flash_state);
  } else {
    led_set_link(s_link_led_streaming);
  }
}

static void link_led_start_flash(uint8_t flashes) {
  if (flashes == 0) {
    return;
  }
  s_link_led_flash_active = true;
  s_link_led_flash_state = true;
  s_link_led_flash_toggles_left = (uint8_t) (flashes * 2u - 1u); // Start ON immediately, then toggle remaining edges.
  s_link_led_flash_next_ms = to_ms_since_boot(get_absolute_time()) + LINK_LED_FLASH_ON_MS;
  link_led_apply_current_state();
}

static void link_led_task(void) {
  if (!s_link_led_flash_active) {
    return;
  }
  uint32_t now_ms = to_ms_since_boot(get_absolute_time());
  if ((int32_t) (now_ms - s_link_led_flash_next_ms) < 0) {
    return;
  }

  s_link_led_flash_state = !s_link_led_flash_state;
  if (s_link_led_flash_toggles_left > 0) {
    s_link_led_flash_toggles_left--;
  }
  if (s_link_led_flash_toggles_left == 0u) {
    s_link_led_flash_active = false;
    link_led_apply_current_state();
    return;
  }

  s_link_led_flash_next_ms = now_ms + (s_link_led_flash_state ? LINK_LED_FLASH_ON_MS : LINK_LED_FLASH_OFF_MS);
  link_led_apply_current_state();
}

static bool button_poll_pressed(button_state_t *state, bool raw_pressed, uint32_t now_ms) {
  if (raw_pressed != state->last_raw_pressed) {
    state->last_raw_pressed = raw_pressed;
    state->last_raw_change_ms = now_ms;
  }
  if ((int32_t) (now_ms - state->last_raw_change_ms) >= (int32_t) VOLUME_BUTTON_DEBOUNCE_MS &&
      state->stable_pressed != state->last_raw_pressed) {
    state->stable_pressed = state->last_raw_pressed;
    return state->stable_pressed;
  }
  return false;
}
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

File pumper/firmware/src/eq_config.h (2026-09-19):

#ifndef EQ_CONFIG_H_
#define EQ_CONFIG_H_

#include <stdbool.h>
#include <stdint.h>

typedef enum {
  EQ_FILTER_LOW_SHELF = 0,
  EQ_FILTER_PEAKING = 1,
  EQ_FILTER_HIGH_SHELF = 2,
  EQ_FILTER_LOW_PASS = 3,
  EQ_FILTER_HIGH_PASS = 4,
  EQ_FILTER_NOTCH = 5,
  EQ_FILTER_BAND_PASS = 6,
} eq_filter_type_t;

typedef enum {
  EQ_WIDTH_Q = 0,
  EQ_WIDTH_BANDWIDTH = 1,
} eq_width_mode_t;

typedef struct {
  bool enabled;
  eq_filter_type_t type;
  eq_width_mode_t width_mode;
  float frequency_hz;
  float q;
  float bw_octaves;
  float gain_db;
} eq_filter_config_t;

#define EQ_NUM_FILTERS 10u

typedef struct {
  bool enabled;
  float preamp_db;
  eq_filter_config_t filters[EQ_NUM_FILTERS];
} eq_config_t;

#define EQ_FREQUENCY_MIN_HZ 20.0f
#define EQ_FREQUENCY_MAX_HZ 20000.0f
#define EQ_GAIN_MIN_DB (-24.0f)
#define EQ_GAIN_MAX_DB 24.0f
#define EQ_PREAMP_MIN_DB (-241.0f)
#define EQ_PREAMP_MAX_DB 12.0f
#define EQ_Q_MIN 0.1f
#define EQ_Q_MAX 20.0f
#define EQ_BANDWIDTH_MIN_OCTAVES 0.1f
#define EQ_BANDWIDTH_MAX_OCTAVES 4.0f
#define EQ_SHELF_SLOPE_MIN 0.1f
#define EQ_SHELF_SLOPE_MAX 1.0f

extern eq_config_t const k_eq_default_config;

void eq_config_set_defaults(eq_config_t *config);
bool eq_config_validate(eq_config_t const *config);
bool eq_config_equal(eq_config_t const *left, eq_config_t const *right);

#endif

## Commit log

2025-10-23 feat: add LightWolf 2350
    [lightwolf.kicad_pcb, lightwolf.kicad_sch]
2025-10-23 feat: update design files and add production files
    [BOM-lightwolf.csv, lightwolf.kicad_pcb, lightwolf.kicad_sch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]
2025-10-23 feat: add blueprint files
    [bom.csv]
2025-10-23 feat: add cart photo and update bom
    [BOM-lightwolf.csv]
2025-10-26 fix: design issue and update project files
    [BOM-lightwolf.csv, bom.csv, lightwolf.kicad_pcb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]
2025-10-31 fix: decoupling issue for VREG_AVDD
    [BOM-lightwolf.csv, lightwolf.kicad_pcb, lightwolf.kicad_sch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]
2026-02-13 feat: upload kicad design source files
    [airnote.kicad_pcb, airnote.kicad_sch]
2026-02-22 feat: rename airnote to pumper and update kicad sources
    [2354a.kicad_sch, BOM-airnote.csv, BOM-pumper.csv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]
2026-02-22 feat: pumper journal update
2026-02-24 feat: update kicad source files
    [BOM-airnote.csv, BOM-pumper.csv, audio.kicad_sch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]
2026-03-05 feat: update design files
    [2354a.kicad_sch, audio.kicad_sch, bom.csv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]
2026-03-06 feat: update kicad files
    [2354a.kicad_sch, BOM-pumper.csv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]
2026-04-02 feat: update firmware for pumper
2026-04-02 fix: left and right channel reversed
    [i2s_out.c]
2026-04-06 feat: use blue led for audio level indicator
2026-04-18 feat: update blue led behavior
2026-04-28 Fix ring buffer comment: max sample rate is 192kHz, not 96kHz
    Agent-Logs-Url: https://github.com/wolf-yuan-6115/lightwolf/sessions/820f3689-2539-4cb6-b376-8353f344414f
    [i2s_out.c, main.c]
2026-04-28 Fix RP2040 references: board is RP2350
    Agent-Logs-Url: https://github.com/wolf-yuan-6115/lightwolf/sessions/717f7b5f-2044-4010-a480-f08d67685607
    [i2s_out.c, main.c, tusb_config.h]
2026-05-12 feat: add feather
    [bom.csv, feather.kicad_pcb, feather.kicad_sch]
2026-05-12 feat: feather production files
    [BOM-feather.csv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]
2026-05-12 feat: update pcb design and layout
    [BOM-feather.csv, feather.kicad_pcb, feather.kicad_sch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]
2026-05-12 fix: oops forget to connect 3v3 to led
    [CPL-feather.csv, feather-CuBottom.gbr, feather-CuIn1.gbr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]
2026-05-13 feat: update board design
    [CPL-feather.csv, feather-CuBottom.gbr, feather-CuIn1.gbr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]
2026-05-13 feat: update power line trace width
    [CPL-feather.csv, feather-CuBottom.gbr, feather-CuIn1.gbr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]
2026-05-13 feat: update feather design files
    [feather.kicad_pcb, feather.kicad_sch]
2026-05-13 feat: feather assets
    [feather.stl]
2026-05-13 feat: update jlcpcb production files
    [BOM-feather.csv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]
2026-05-16 feat: increase pumper led level
2026-05-16 feat: update firmware to new board design
2026-05-16 feat: add two more buttons
    [BOM-feather.csv, bom.csv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]
2026-07-18 feat: add unnecessary features to pumper
2026-07-18 feat: add pumper web panel
2026-07-18 feat: add pumper linux udev
2026-07-19 feat: add temp sensor
2026-07-19 feat: add temp sensor reading
2026-07-25 fix: pop sound on 192k when EQ adjust
    [main.c]
2026-09-20 fix: 192k not advertised
    [tusb_config.h]
2026-10-06 fix: 96k 24 bit fix
    [main.c]
2026-10-15 feat(pumper): refine desktop EQ controller and graph interaction
2026-11-01 feat(android): show filter response in band editor
2026-11-11 feat: add factory reset button and command
